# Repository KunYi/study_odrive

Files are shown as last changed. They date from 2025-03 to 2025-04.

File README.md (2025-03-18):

## Important Note

The firmware in this repository is compatible with the ODrive v3.x (NRND) and is no longer under active development.

Firmware for the new generation of ODrives ([ODrive Pro](https://odriverobotics.com/shop/odrive-pro), [S1](https://odriverobotics.com/shop/odrive-s1), [Micro](https://odriverobotics.com/shop/odrive-micro), etc.) is currently being actively maintained and developed, however its source code is currently not publicly available. Access may be available under NDA, please [reach out to us](mailto:info@odriverobotics.com) for inquiries.

## Overview

ODrive Logo

This project is all about accurately driving brushless motors, for cheap. The aim is to make it possible to use inexpensive brushless motors in high performance robotics projects, like [this](https://www.youtube.com/watch?v=WT4E5nb3KtY).

| Branch | Build Status |
|---|---|
| master |  |
| devel  |  |



Please refer to the [Developer Guide](https://docs.odriverobotics.com/v/latest/developer-guide.html#) to get started with ODrive firmware development.

### Repository Structure
 * **Firmware**: ODrive firmware
 * **tools**: Python library & tools
 * **docs**: Documentation

### Other Resources

 * [Main Website](https://www.odriverobotics.com/)
 * [User Guide](https://docs.odriverobotics.com/)
 * [Forum](https://discourse.odriverobotics.com/)
 * [Chat](https://discourse.odriverobotics.com/t/come-chat-with-us/281)

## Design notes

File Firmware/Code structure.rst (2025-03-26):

ODrive 代碼結構
==================

啟動流程
--------

啟動程序
^^^^^^^^

- **文件位置**: `Board/v3/startup_stm32f405xx.s`
- **功能**: 設置初始堆疊指針、配置中斷向量表、跳轉到 `SystemInit()`

系統初始化
^^^^^^^^^^

- **函數**: `SystemInit()`
- **文件位置**: `Board/v3/Src/system_stm32f4xx.c`
- **功能**: 重置系統狀態、配置向量表、設置系統時鐘

啟動前檢查
^^^^^^^^^^

- **函數**: `early_start_checks()`
- **文件位置**: `MotorControl/main.cpp`
- **功能**: 檢查是否需要進入DFU模式（當AUX L/H 拉高或標誌位被設置時）

主函數
^^^^^^

- **函數**: `main()`
- **文件位置**: `MotorControl/main.cpp`
- **功能**:

  - 讀取晶片UID生成USB設備描述符的序列號
  - 調用 `system_init()` 進行系統初始化
  - 透過 `config_manager` 載入系統設定
  - 調用 `board_init()` 進行板級與外設初始化
  - 初始化外設和控制系統
  - 設定 GPIO 模式
  - 建立 FreeRTOS 執行環境與創建預設執行Task, 執行 `rtos_main()`
  - 在 rtos_main 進行USB/ADC/PWM/UART/Communication/Axes 相關初始化，並開啟 axis 的 task thread 後結束 rtos_main 自己
  - 系統透過 axis status machine 運作，執行Motors 的初始化與定位相關

系統初始化
----------

板級初始化
^^^^^^^^^^

- **函數**: `system_init()`
- **文件位置**: `Board/v3/board.cpp`
- **功能**:

  - 初始化STM32 HAL庫
  - 檢查板卡硬件版本
  - 配置系統時鐘和引腳狀態

外設初始化
----------

GPIO初始化
^^^^^^^^^^

- **文件位置**: `Board/v3/Src/gpio.c`
- **相關函數**: `MX_GPIO_Init()`

ADC初始化
^^^^^^^^^

- **文件位置**: `Board/v3/Src/adc.c`
- **相關函數**: `MX_ADC1_Init()`, `MX_ADC2_Init()`, `MX_ADC3_Init()`
- **功能**: 用於電流檢測、電壓檢測等

定時器初始化
^^^^^^^^^^^^

- **文件位置**: `Board/v3/Src/tim.c`
- **相關函數**: `MX_TIM1_Init()`, `MX_TIM8_Init()`
- **功能**: 用於PWM生成控制電機

SPI初始化
^^^^^^^^^

- **文件位置**: `Board/v3/Src/spi.c`
- **相關函數**: `MX_SPI3_Init()`
- **功能**: 用於編碼器接口

CAN總線初始化
^^^^^^^^^^^^^

- **文件位置**: `Board/v3/Src/can.c`
- **相關函數**: `MX_CAN1_Init()`

USB初始化
^^^^^^^^^

- **文件位置**: `Board/v3/Src/usbd_conf.c`, `Board/v3/Src/usbd_cdc_if.c`
- **相關函數**: `MX_USB_DEVICE_Init()`

FOC電機控制
-----------

電機控制類
^^^^^^^^^^

- **文件位置**: `MotorControl/motor.cpp`, `MotorControl/motor.hpp`
- **主要類**: `Motor`
- **功能**: 電機參數初始化、電流控制、速度控制、位置控制

編碼器接口
^^^^^^^^^^

- **文件位置**: `MotorControl/encoder.cpp`, `MotorControl/encoder.hpp`
- **主要類**: `Encoder`
- **功能**: 編碼器初始化、位置讀取、速度計算

FOC控制算法
^^^^^^^^^^^

- **文件位置**: `MotorControl/foc.cpp`, `MotorControl/foc.hpp`
- **主要函數**: `FOC_current()`, `FOC_voltage()`
- **功能**: 實現Field Oriented Control算法

軸控制
^^^^^^

- **文件位置**: `MotorControl/axis.cpp`, `MotorControl/axis.hpp`
- **主要類**: `Axis`
- **功能**: 協調電機和編碼器，實現位置/速度閉環控制

軌跡規劃
^^^^^^^^

- **文件位置**: `MotorControl/trajectory.cpp`, `MotorControl/trajectory.hpp`
- **主要類**: `Trajectory`
- **功能**: 實現平滑的運動軌跡規劃

通信接口
--------

USB通信
^^^^^^^

- **文件位置**: `MotorControl/usb_communication.cpp`, `MotorControl/usb_communication.hpp`
- **功能**: 處理USB通信，解析命令

CAN總線通信
^^^^^^^^^^^^

- **文件位置**: `MotorControl/can_communication.cpp`, `MotorControl/can_communication.hpp`
- **功能**: 處理CAN總線通信

命令處理
^^^^^^^^

- **文件位置**: `MotorControl/commands.cpp`, `MotorControl/commands.hpp`
- **功能**: 解析和執行來自通信接口的命令

主循環與狀態機
--------------

主循環
^^^^^^

- **文件位置**: `MotorControl/main.cpp`
- **功能**: 調用狀態機更新、處理通信、執行控制算法

狀態機
^^^^^^

- **文件位置**: `MotorControl/state_machine.cpp`, `MotorControl/state_machine.hpp`
- **主要類**: `StateMachine`
- **功能**: 管理電機控制器的不同狀態（校準、閉環控制、錯誤狀態等）

安全檢查與錯誤處理
------------------

錯誤處理
^^^^^^^^

- **文件位置**: `MotorControl/error.cpp`, `MotorControl/error.hpp`
- **功能**: 定義錯誤類型、處理錯誤狀態

安全監控
^^^^^^^^

- **文件位置**: `MotorControl/safety.cpp`, `MotorControl/safety.hpp`
- **功能**: 監控過流、過壓、過溫等異常情況

ODrive 韌體架構分析
======================

第一章：系統初始化與啟動 (System Initialization and Startup)
--------------------------------------------------------------------

韌體的啟動流程由 rtos_main 函數開始
這個函數負責初始化核心周邊、通訊介面和馬達相關組件。

* USB 裝置初始化：首先會呼叫 MX_USB_DEVICE_Init() 初始化 USB 通訊。
* ADC 初始化：start_general_purpose_adc() 用於啟動 ADC，可能用於溫度和使用者自定義量測。
* 通訊初始化：init_communication() 負責設定不同的通訊介面，例如 UART、CAN 等。

  * 原始碼中提到 uart_poll() 函數，暗示了 UART 通訊的輪詢機制。
  * ODriveCAN can_; 的宣告表示支援 CAN Bus 通訊。
  *  程式碼中也看到對 enable_uart_a、enable_uart_b、enable_uart_c 和 enable_can_a 等配置的檢查，這些配置項在 BoardConfig_t 結構體中定義。

* PWM 輸入初始化：pwm0_input.init() 初始化 PWM 輸入捕獲模組，可能用於接收外部 PWM 訊號。
* 絕對式編碼器 CS 腳位設定：程式碼中針對具有絕對式編碼器的軸進行 CS (Chip Select) 腳位的初始化。
* 閘極驅動器初始化：每個軸的馬達物件會調用 setup() 函數，這可能包含閘極驅動器 (如 Drv8301) 的初始化。
* 編碼器初始化：每個軸的編碼器物件也會調用 setup() 函數，啟動編碼器硬體介面 (例如 HAL_TIM_Encoder_Start)。
* 組件連接：程式碼中將不同組件的輸出和輸入連接起來，例如感測器無感測估測器 (SensorlessEstimator) 的輸出連接到控制器的輸入。
* ADC PWM 同步啟動：start_adc_pwm() 啟動 PWM 產生和 ADC 中斷/回調，這是實現 FOC 的關鍵步驟。
* 類比線程啟動：start_analog_thread() 啟動一個專門處理類比訊號的線程。
* 等待馬達就緒：啟動流程會等待一段時間 (最長 2 秒) 讓馬達相關組件就緒，例如電流感測器的校準收斂。
* 載入使用者配置：韌體會嘗試載入儲存的使用者配置，如果成功則應用配置，否則清除並應用預設配置。
* ConfigManager 類別負責配置的載入和儲存。
* 板卡特定周邊初始化：board_init() 函數用於初始化特定硬體平台的周邊。
* GPIO 初始化：根據 odrv.config_.gpio_modes 中的配置，初始化每個 GPIO 腳位的功能 (例如數位輸入/輸出、類比輸入、UART、CAN、PWM、編碼器等)。

第二章：軸 (Axis) 管理
---------------------------

ODrive 的核心概念之一是 軸 (Axis)。 一個 ODrive 裝置可以有多個軸 (**在 AXIS_COUNT** 中定義)，每個軸通常對應一個馬達。

軸物件：
^^^^^^^^

**Axis** 類別封裝了控制一個馬達所需的所有組件和狀態。

每個 **Axis** 物件都包含了以下子物件

- **Encoder**: 負責馬達位置和速度的感測

  - **Controller**: 實現馬達的控制邏輯，包括位置、速度和扭矩控制模式。
  - **Motor**: 代表實際的馬達硬體，負責 PWM 控制、電流感測、溫度保護等。
  - **TrapezoidalTrajectory**: 用於產生梯形速度曲線，實現平滑的運動規劃。
  - **Endstop**: 用於限制馬達的運動範圍。
  - **MechanicalBrake**: 用於控制機械煞車 (如果存在)。

- **軸狀態機**：每個軸都有一個狀態機 (current_state_)，定義了軸的不同操作階段，例如啟動、校準、閉迴路控制、空閒等。task_chain_ 則定義了軸狀態轉換的順序。
- **執行緒管理**：每個軸都在一個獨立的 **FreeRTOS** 執行緒中運行其狀態機迴圈 (**run_state_machine_loop**)。**start_thread()** 函數負責創建這些執行緒。
- **步進/方向介面**：**Axis** 類別支援步進/方向訊號輸入，用於接收外部運動指令。**step_cb()** 函數處理步進訊號，並更新馬達的目標位置。
- **錯誤處理**：每個軸都有一個 error_ 變數，用於記錄該軸及其子組件發生的錯誤。**do_checks()** 函數會檢查軸及其子組件的錯誤狀態。
- **看門狗**： **watchdog_feed()** 和 **watchdog_check()** 函數用於實現看門狗機制，防止韌體因錯誤而停止響應。

第三章：通訊介面 (Communication Interfaces)
-----------------------------------------------

ODrive 韌體支援多種通訊介面，用於與外部設備進行控制和數據交換。

- **UART** (Universal Asynchronous Receiver/Transmitter):

在board.c 的程式碼中可以看到下面的宣告，表示使用 STM32F405 的 UASART4 作為UART_A 和 USART2 作為 UART_B。::

  UART_HandleTypeDef* uart_a = &huart4;
  UART_HandleTypeDef* uart_b = &huart2;

BoardConfig_t 設定中包含 enable_uart_a、enable_uart_b、enable_uart_c 和對應的 uart_a_baudrate 值等等。

ODriveIntf::StreamProtocolType 则是使用UART 的一種協議類型定義。

- **CAN** (Controller Area Network):

ODriveCAN can_; 的宣告表示支援 CAN Bus 通訊。

BoardConfig_t 中包含 enable_can_a 設定值

另外GPIO 配置中包含 ODriveIntf::GPIO_MODE_CAN_A 選項，並指定了相關的 GPIO 腳位 (CAN_R, CAN_D)。程式碼中檢查 GPIO 模式是否與 CAN 模式一致。

- **USB** (Universal Serial Bus):

  **MX_USB_DEVICE_Init()** 用於初始化 USB 裝置功能。

  - SystemStats_t 結構體中包含與 USB 相關的統計資訊，例如最大堆疊使用量 (max_stack_usage_usbv) 和優先級 (prio_usb)。
  - ODriveIntf::StreamProtocolType usb_cdc_protocol 用於定義 USB CDC (Communication Device Class) 的通訊協定。

- **GPIO** 作為通訊介面:

GPIO 可以配置為多種通訊相關的功能，例如 UART 和 I2C 的替代功能 (AF, Alternate Function)。

第四章：馬達控制 (Motor Control)
------------------------------------------

ODrive 主要採用 磁場導向控制 (Field-Oriented Control, FOC)。**FieldOrientedController** 類別實現了 FOC 演算法。

- 電流感測：馬達電流透過 ADC 進行感測。**Motor::current_meas_cb()** 函數處理電流感測的回調，並進行零點校準 ( DC_calib_ ) 和資料更新。**phase_current_from_adcval()** 函數將 **ADC** 值轉換為相電流。
- 電壓應用：FOC 控制器計算出所需的 α-β 參考系電壓 ( final_v_alpha_, final_v_beta_ )，然後透過 **空間向量脈寬調變 (Space Vector Modulation, SVM)** 將其轉換為三個 PWM 訊號的佔空比 (pwm_timings)。**Motor::pwm_update_cb()** 函數在 PWM 更新事件發生時被調用，並應用新的 PWM 時序。
  呼叫順序如下::

  Motor::pwm_update_cb() ==>> control_law_->get_output() (實際就是　AlphaBetaFrameController::get_output()) ==>> FieldOrientedController::get_alpha_beta_output() ==>> SVM()

- 控制模式：Controller 類別支援多種控制模式:

  - 位置控制 (Position Control): 將馬達控制到指定的角度。
  - 速度控制 (Velocity Control): 將馬達控制到指定的轉速。
  - 扭矩控制 (Torque Control): 直接控制馬達輸出的扭矩。

- 電流控制迴路：在電流控制模式下，FOC 控制器使用 PI (比例積分) 控制器 來追蹤目標 d 軸和 q 軸電流 (Idq_setpoint_)。PI 控制器的增益 (pi_gains_) 可以在電阻和電感測量後自動設定.
- 電壓控制迴路：在電壓控制模式下，FOC 控制器直接輸出目標 d 軸和 q 軸電壓 (Vdq_setpoint_)。
- 前饋控制：FOC 控制器支援多種前饋控制項，例如 bEMF 前饋 (bEMF_FF_enable) 和 RI、wL*I 前饋 (R_wL_FF_enable)，以提高控制性能。
- 扭矩限制和速度限制：控制器可以設定扭矩上限 (torque_limit) 和速度上限 (vel_limit)，以保護馬達和系統。
- 反饋來源：控制器可以選擇不同的位置和速度反饋來源，例如編碼器或無感測估測器.
- 開環控制：OpenLoopController 類別實現了開環控制模式，在沒有位置或速度反饋的情況下直接控制馬達的相位和電壓/電流。這通常用於馬達參數校準階段。

第五章：位置和速度估測 (Position and Velocity Estimation)
----------------------------------------------------------------------

韌體使用兩種主要方法來獲取馬達的位置和速度資訊：

- **編碼器 (Encoder)** ：Encoder 類別處理來自各種編碼器的訊號。支援增量式編碼器透過計數器 (timer_) 測量相對位置變化。也支援霍爾感測器，透過解碼霍爾訊號 (decode_hall_samples()) 獲取粗略的位置和速度資訊。對於絕對式編碼器，韌體透過 SPI 通訊 (abs_spi_start_transaction(), abs_spi_cb()) 讀取絕對位置。對於正餘弦編碼器，韌體讀取類比訊號 (sincos_sample_s_, sincos_sample_c_) 並計算相位。編碼器物件還實現了 鎖相迴路 (Phase-Locked Loop, PLL) (pll_)，用於濾除編碼器雜訊並估計速度。

- **無感測估測器 (Sensorless Estimator)** ：SensorlessEstimator 類別在沒有編碼器的情況下，基於馬達的電壓和電流資訊來估計轉子位置和速度。它使用基於磁鏈觀測器的演算法，通過測量到的相電流和施加的電壓來估計磁鏈狀態 (flux_state_)，進而推斷轉子位置和速度。

模式切換：韌體可以根據配置在編碼器模式和無感測模式之間切換。

第六章：校準程序 (Calibration Procedures)
--------------------------------------------------

為了獲得最佳的控制性能，ODrive 韌體包含多個校準程序-
- **電流感測器零點校準 (DC Calibration)** ： *Motor::dc_calib_cb()* 函數用於校準電流感測器的偏移量 ( DC_calib_ )。
- **相電阻測量 (Phase Resistance Measurement)** ： *Motor::measure_phase_resistance()* 函數透過施加一個已知的測試電流並測量電壓來估計馬達的相電阻 ( config_.phase_resistance )。
- **相電感測量 (Phase Inductance Measurement)** ： *Motor::measure_phase_inductance()* 函數透過快速切換輸出電壓並觀察電流漣波來估計馬達的相電感 ( config_.phase_inductance )。
- **編碼器偏移校準 (Encoder Offset Calibration)** ： *Encoder::run_offset_calibration()* 函數用於確定編碼器計數和馬達電氣相位的對應關係 ( config_.phase_offset, config_.phase_offset_float )。這通常涉及在開環模式下旋轉馬達並採集編碼器讀數。
- **霍爾感測器極性校準 (Hall Polarity Calibration)** ： *Encoder::run_hall_polarity_calibration()* 函數用於確定霍爾感測器的極性 ( config_.hall_polarity )。
- **霍爾感測器相位校準 (Hall Phase Calibration)** ： *Encoder::run_hall_phase_calibration()* 函數用於校準霍爾感測器訊號和馬達電氣相位的對應關係 ( config_.hall_edge_phcnt )。
- **方向尋找 (Direction Find)** ： *Encoder::run_direction_find()* 函數用於確定編碼器的方向 ( config_.direction )。
- **反齒槽效應校準 (Anticogging Calibration)** ： *Controller::anticogging_calibration()* 函數用於測量並補償由馬達磁極齒槽效應引起的扭矩波動 ( config_.anticogging.cogging_map )。

第七章：配置管理 (Configuration Management)
----------------------------------------------------

ODrive 韌體使用 ConfigManager 類別來管理配置參數的儲存和載入。

- **配置結構體** ：主要的配置參數儲存在 ODrive::config_ ( BoardConfig_t ) 和每個軸的 Axis::config_、Controller::config_、Motor::config_、Encoder::config_ 等結構體中。
- **預設配置** ：程式碼中可以看到許多預設配置值的定義 (例如 DEFAULT_BRAKE_RESISTANCE, DEFAULT_MIN_DC_VOLTAGE, DEFAULT_GPIO_MODES)。
- **載入配置** ：在啟動時，韌體會嘗試從非揮發性記憶體 (例如 Flash) 載入使用者配置。如果載入成功，則應用這些配置 ( config_read_all(), config_apply_all() ).
- **儲存配置** ：使用者可以透過通訊介面將目前的配置儲存到非揮發性記憶體 ( config_write_all(), config_manager.start_store(), config_manager.finish_store() ).
- **清除配置** ：韌體也提供清除所有使用者配置並恢復到預設值的機制 ( config_clear_all() ).
- **GPIO 模式配置** ：BoardConfig_t::gpio_modes 陣列定義了每個 GPIO 腳位的功能模式。在啟動時，韌體會根據這些配置初始化 GPIO 腳位。

第八章：錯誤處理與安全 (Error Handling and Safety)
------------------------------------------------------------------

ODrive 韌體具有完善的錯誤處理機制。

- 錯誤碼：每個主要組件 (ODrive 本身、Axis、Motor、Encoder、Controller、SensorlessEstimator) 都有一個 error_ 變數，用於記錄發生的錯誤。錯誤碼通常是枚舉類型 (例如 ODrive::Error, Axis::Error, Motor::Error)。
- 設定錯誤：組件可以使用 set_error() 函數設定其錯誤狀態。
- 檢查錯誤：Axis::do_checks() 函數會檢查軸及其子組件的錯誤狀態。ODrive::any_error() 函數檢查整個系統是否存在任何錯誤。
- 解除武裝 (Disarming)：在檢測到嚴重錯誤時，韌體會將馬達解除武裝 (Motor::disarm(), ODrive::disarm_with_error())，停止 PWM 輸出，以防止硬體損壞。
- 煞車電阻控制 (Brake Resistor Control)：韌體支援使用煞車電阻來吸收再生能量，防止直流母線過壓。brake_resistor_armed_, brake_resistor_saturated_, brake_resistor_current_ 等變數用於追蹤煞車電阻的狀態。 *update_brake_current()* 函數計算並設定煞車電阻的佔空比。
- 電流限制：Motor::effective_current_lim() 函數計算有效的電流限制。在 FOC 控制器中，電流會被限制在安全範圍內。
- 溫度保護：OnboardThermistorCurrentLimiter 和 OffboardThermistorCurrentLimiter 類別用於監控 FET 和馬達的溫度，並在溫度過高時限制電流或觸發錯誤。
- 看門狗計時器 (Watchdog Timer)：看門狗用於檢測韌體是否停止運行，並在超時時重置系統。

第九章：即時作業系統 (Real-Time Operating System, RTOS)
------------------------------------------------------------------

ODrive 韌體基於 FreeRTOS 運行。

- **執行緒 (Tasks)** ：系統和每個軸的功能都運行在不同的 FreeRTOS 執行緒中，實現並行處理.
- **優先級 (Priorities)** ：每個執行緒可以設定不同的優先級 (例如 thread_priority_, osPriorityHigh)，以確保關鍵任務 (例如控制迴路) 能夠及時執行.
- **訊號量 (Signals)** ： *osSignalWait()* 和 *osSignalSet()* 等 FreeRTOS API 可能用於執行緒間的同步和通訊 (例如 Axis::wait_for_control_iteration() 使用訊號量等待控制迴路完成).
- **互斥鎖 (Mutexes) 和臨界區段 (Critical Sections)** ： *CRITICAL_SECTION()* 宏用於保護共享資源免受多個執行緒同時存取的影響，防止競爭條件.
- **堆疊大小 (Stack Size)** ：每個執行緒都有分配的堆疊空間 (stack_size_)，用於儲存局部變數和函數調用資訊.

第十章：硬體抽象層 (Hardware Abstraction Layer, HAL)
---------------------------------------------------------

ODrive 韌體廣泛使用 STM32 HAL (Hardware Abstraction Layer) 庫來與底層的 STM32 微控制器硬體進行互動。
HAL 提供了對微控制器各種周邊 (例如 ADC、TIM、SPI、UART、GPIO) 的標準化 API，使得韌體開發人員可以更方便地存取和控制硬體，而無需深入了解底層硬體細節。
例如，HAL_ADC_Start_DMA(), HAL_TIM_Encoder_Start(), HAL_GPIO_Init(), HAL_SPI_TxRxCpltCallback() 等函數都是 HAL 庫提供的 API.
韌體中定義了許多指向 HAL 結構體的指標 (例如 TIM_HandleTypeDef* timer_, ADC_HandleTypeDef hadc1, SPI_HandleTypeDef hspi3)，用於操作特定的硬體周邊

系統主要參數設計
=================



ODrive 使用 TIMER1 & TIMER8 產生控制MOSFET 開關用的PWM，這也是STM32 本身具有的兩個高級定時器，它們兩個分別對應兩顆FOC馬達控制使用TIM1 對應M0, TIM8 對應M1，
都是使用 **TIM_COUNTERMODE_CENTERALIGNED3** (參考tim.c or ODrive.ioc)，所以向上或向下開始計數的時候都會產生事件, TIM_1_8_RCR(Repetition Counter Register) 設定為2

main.h 是透過 **ODrive.ioc** (*STM32CubeMX* 設定檔) 產生的。

- **TIM_1_8_CLOCK_HZ**: TIM1 & TIM8 的頻率來源 (168MHz), 定義在 main.h
- **TIM_1_8_PERIOD_CLOCKS**: TIM1 & TIM8 每個週期的計數 (3500), 所以TIM1/TIM8 的PWM一個週期為 168MHz/3500/2 = 24KHz, 2 是因為 center_aligned 上下數各一次，定義在 main.h
- **TIM_1_8_DEADTIME_CLOCKS**: TIM1 & TIM8 輸出的死區定義時間時脈數(20), 定義在 main.h

- **CURRENT_MEAS_PERIOD**:　量測電流的週期，目前設計為PWM週期的3倍長, 指定給常數 *current_meas_period* 定義在 board.h
- **CURRENT_MEAS_HZ**: 量測電流的頻率， 目前設計為PWM頻率的1/3，指定給常數 *current_meas_hz* 定義在board.h
- **VBUS_S_DIVIDER_RATIO**: 量測DCBUS/VBUS 電壓的分壓器比率, 24V 使用R6(10KOhm), R7(1KOhm) 分壓比率為11.0f, 大於等於48V系統則為R6(18KOhm), R7(1KOhm), 分壓比率為19.0f

所以 ODrive 的 FOC 控制頻率是24KHz, 電流環是 24KHz/3 = 8KHz。但是實際電流取樣的頻率設計不是透過這個常數進行。

而是在TIM8_UP_TIM13_IRQ 設定，因為它設定中間對齊與模式3 上下都觸發，因此為48KHz，但是該RCR 為 2，所以它實際的觸發頻率為48KHz/(2+1)=16KHz,等於一次觸發為上數，一次觸發為下數。
但是它又不是每次觸發都取樣，它只在TIM8上數時，進行取樣，所以為16KHz/2=8KHz。

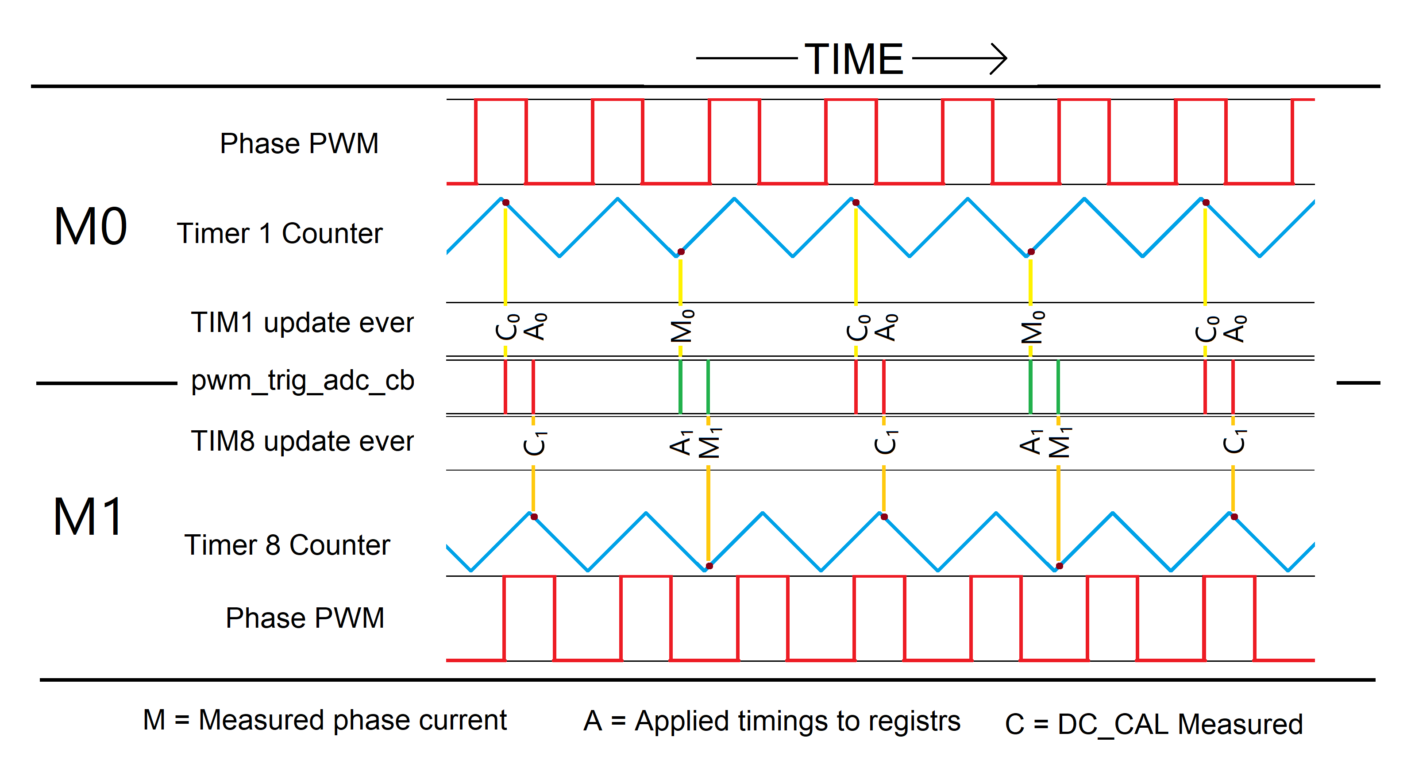
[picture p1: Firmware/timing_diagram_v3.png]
sampling timing


電流環的頻率設定，跟電機的電頻率跟磁極數目與轉速正相關，一般需要最少10倍來設計。

ODrive 中斷表與優先權
=========================

.. list-table:: **Interrupt Table**
   :widths: 25 25 25 25 50
   :header-rows: 1

   * - Interrupt Name
     - Priority Level
     - SubPriority
     - Source
     - Notes
   * - NMI_Handler
     - --
     - --
     - Default Cortex-M4
     - Non-Maskable Interrupt (Highest Priority)
   * - HardFault_Handler
     - --
     - --
     - Default Cortex-M4
     - Hard Fault (Second Highest Priority)
   * - MemoryManagement_IRQn
     - --
     - --
     - CubeMX Config []
     - Configured in CubeMX
   * - BusFault_IRQn
     - --
     - --
     - CubeMX Config []
     - Configured in CubeMX
   * - UsageFault_IRQn
     - --
     - --
     - CubeMX Config []
     - Configured in CubeMX
   * - TIM8_UP_TIM13_IRQn
     - 0
     - 0
     - board.cpp [], CubeMX Config []
     - Timer 8 Update and Timer 13 Interrupt (Note: Priority 0 is higher than 1)
   * - TIM1_UP_TIM10_IRQn
     - 0
     - 0
     - CubeMX Config []
     - Timer 1 Update and Timer 10 Interrupt (Note: Priority 0 is higher than 1)
   * - TIM8_TRG_COM_TIM14_IRQn
     - 0
     - 0
     - CubeMX Config []
     - Timer 8 Trigger and Commutation, Timer 14 Interrupt (Note: Priority 0 is higher than 1)
   * - EXTI0_IRQn
     - 1
     - 0
     - board.cpp []
     - External Interrupt 0
   * - EXTI1_IRQn
     - 1
     - 0
     - board.cpp []
     - External Interrupt 1
   * - EXTI2_IRQn
     - 1
     - 0
     - board.cpp []
     - External Interrupt 2
   * - EXTI3_IRQn
     - 1
     - 0
     - board.cpp []
     - External Interrupt 3
   * - EXTI4_IRQn
     - 1
     - 0
     - board.cpp []
     - External Interrupt 4
   * - EXTI9_5_IRQn
     - 1
     - 0
     - board.cpp []
     - External Interrupts 5 to 9
   * - EXTI15_10_IRQn
     - 1
     - 0
     - board.cpp []
     - External Interrupts 10 to 15
   * - ControlLoop_IRQn
     - 5
     - 0
     - board.cpp [], (OTG_HS_IRQHandler define [], CubeMX)
     - Used for the Field-Oriented Control (FOC) loop
   * - ADC_IRQn (ADC1, ADC2, ADC3)
     - 5
     - 0
     - CubeMX Config []
     - ADC1, ADC2, and ADC3 Interrupts (likely priority as per CubeMX, though not explicitly set in board.cpp like ControlLoop_IRQn)
   * - SPI3_IRQn
     - 5
     - 0
     - CubeMX Config []
     - SPI3 Interrupt (likely priority as per CubeMX)
   * - UART4_IRQn
     - 5
     - 0
     - board.cpp [], CubeMX Config []
     - UART4 Interrupt (if enable_uart_a is true)
   * - USART2_IRQn
     - 5
     - 0
     - CubeMX Config [] (likely)
     - USART2 Interrupt (if enable_uart_b is true, likely priority as per CubeMX)
   * - TIM5_IRQn
     - 5
     - 0
     - CubeMX Config []
     - TIM5 Interrupt (likely priority as per CubeMX)
   * - OTG_FS_IRQn
     - 5
     - 0
     - CubeMX Config []
     - USB OTG FS Interrupt
   * - DMA1_Stream0_IRQn
     - 5
     - 0
     - CubeMX Config []
     - DMA1 Stream 0 Interrupt (likely priority as per CubeMX)
   * - DMA1_Stream2_IRQn
     - 5
     - 0
     - CubeMX Config []
     - DMA1 Stream 2 Interrupt (likely priority as per CubeMX)
   * - DMA1_Stream4_IRQn
     - 5
     - 0
     - CubeMX Config []
     - DMA1 Stream 4 Interrupt (likely priority as per CubeMX)
   * - DMA1_Stream5_IRQn
     - 5
     - 0
     - CubeMX Config []
     - DMA1 Stream 5 Interrupt (likely priority as per CubeMX)
   * - DMA2_Stream0_IRQn
     - 5
     - 0
     - CubeMX Config []
     - DMA2 Stream 0 Interrupt (likely priority as per CubeMX)
   * - CAN1_TX_IRQn
     - 6
     - 0
     - CubeMX Config []
     - CAN1 Transmit Interrupt
   * - CAN1_RX0_IRQn
     - 6
     - 0
     - CubeMX Config []
     - CAN1 Receive FIFO 0 Interrupt
   * - CAN1_RX1_IRQn
     - 6
     - 0
     - CubeMX Config []
     - CAN1 Receive FIFO 1 Interrupt
   * - CAN1_SCE_IRQn
     - 6
     - 0
     - CubeMX Config []
     - CAN1 Status Change Interrupt
   * - DebugMonitor_IRQn
     - 0
     - 0
     - CubeMX Config []
     - Debug Monitor Interrupt
   * - SVCall_IRQn
     - 0
     - 0
     - CubeMX Config []
     - System Service Call via SWI instruction
   * - I2C1_EV_IRQn
     - N/A
     - N/A
     - board.cpp [] (HAL_I2C_EV_IRQHandler)
     - I2C1 Event Interrupt (Priority likely set in MX_I2C1_Init, but not explicitly shown in board_init like ControlLoop_IRQn)
   * - I2C1_ER_IRQn
     - N/A
     - N/A
     - board.cpp [] (HAL_I2C_ER_IRQHandler)
     - I2C1 Error Interrupt (Priority likely set in MX_I2C1_Init)
   * - PendSV_IRQn
     - 15
     - 0
     - CubeMX Config []
     - FreeRTOS PendSV Interrupt (for context switching)
   * - SysTick_IRQn
     - 15
     - 0
     - CubeMX Config []
     - FreeRTOS SysTick Interrupt (for time slicing and system tick)

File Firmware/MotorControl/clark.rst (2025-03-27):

Clarke 變換
==============

**1. 為何需要 Clarke 變換？**

在三相平衡交流系統中，通常會有三個相電壓/電流（Va, Vb, Vc），它們是彼此相差 120° 的正弦波。然而，這三個變數並非完全獨立，它們本身也受 **克希荷夫電流定律 (KCL)** 限制。把負載看成單一節點使用，所以一定會滿足 **KCL**：

.. math::

   V_a + V_b + V_c = 0

由於這個限制，三個變數中只有兩個是獨立的。**Clarke 變換** 的目的就是找到一個 **變換矩陣 T**，將三相電壓/電流 (Va, Vb, Vc) 轉換到一個二維的正交 **α-β 靜止坐標系** (Vα, Vβ) 中：

.. math::

   \left[
   \begin{matrix}
    V_\alpha \\
    V_\beta
   \end{matrix}
   \right]
   = T *
   \left[
   \begin{matrix}
   V_a \\
   V_b \\
   V_c
   \end{matrix}
   \right]

這樣做的優點是，我們可以使用兩個獨立的變數 :math:`\left(\textbf{V$_\mathbf{\alpha}, V_\mathbf{\beta}$}\right)` 在二維平面上 **完整地描述** 原始三相系統的電壓/電流資訊，簡化後續的分析和控制。

**2. 幾何直覺**

為了更好地理解 Clarke 變換，我們可以從幾何的角度來看：

-   **原始三相坐標 (Va, Vb, Vc)**：每一相電壓可以想像成對應到一個基底向量，這些向量之間相隔 120°。
-   **目標 α-β 二維坐標系**：我們希望建立一個 **正交基底** 來表示新的二維系統，方便分析：

    -   **α 軸**：方向與 A 相（Va）相同。
    -   **β 軸**：方向與 α 軸正交。

Clarke 變換的幾何意義就是將原始三相系統中的每個相電壓 **投影** 到這個新的正交 α 和 β 軸上，得到它們在二維平面上的分量 Vα 和 Vβ。

**3. 基底向量推導**

根據上述幾何直覺，我們可以推導出 Clarke 變換的基底向量和轉換矩陣：

-   **Va 的基底表示**: :math:`\left(\begin{matrix} 1_, 0\end{matrix}\right)`
-   **Vb 的基底表示**: :math:`\left(\begin{matrix} -\frac{1}{2}_, \frac{\sqrt{3}}{2}\end{matrix}\right)`
-   **Vc 的基底表示**: :math:`\left(\begin{matrix} -\frac{1}{2}_, -\frac{\sqrt{3}}{2}\end{matrix}\right)`

基於這些基底向量，我們可以 **構造出 Clarke 變換的矩陣 T**：

.. math::

   T =
   \left[
   \begin{matrix}
   1 & -\frac{1}{2} & -\frac{1}{2} \\
   0 & \frac{\sqrt{3}}{2} & -\frac{\sqrt{3}}{2}
   \end{matrix}
   \right]

**4. 矩陣驗證與標準公式**

將三相電壓 [Va, Vb, Vc]ᵀ 帶入上述轉換矩陣，我們可以得到 α 和 β 分量：

.. code-block::

   Vα = Va - 1/2Vb - 1/2Vc
   Vβ = √3/2Vb - √3/2Vc

這與常見的 Clarke 變換公式一致，證明了我們推導的正確性。

**5. Clarke 變換的程式碼實現**

在程式碼中，Clarke 變換通常會接收三相電流（Ia, Ib, Ic）或電壓作為輸入，並輸出兩相的 α-β 分量（Iα, Iβ 或 Vα, Vβ）。根據提供的程式碼片段，以下是一個 Clarke 變換的實現範例（針對電流）：

.. code-block:: c++

   std::optional<float2D> Ialpha_beta;

   if (currents.has_value()) {
       // Clarke transform
       Ialpha_beta = {
           (*currents),
           one_by_sqrt3 * ((*currents) - (*currents))
       };
   }

以及另一個範例：

.. code-block:: c++

   float I_alpha_beta = {
       current_meas->phA,
       one_by_sqrt3 * (current_meas->phB - current_meas->phC)};

在這些程式碼片段中，**三相電流被轉換為兩相靜止坐標系下的電流分量 Iα 和 Iβ**。``one_by_sqrt3`` 代表 **1/√3**。需要注意的是，Clarke 變換存在不同的版本，它們在最終的 α-β 分量上可能會有一個比例因子，例如 **功率保持不變** 的版本和 **幅值保持不變** 的版本。在實際應用中，應根據具體需求選擇合適的版本。

總結來說，**Clarke 變換** 是一種重要的坐標轉換，它將三相交流系統的變數轉換到一個更易於分析和控制的二維靜止坐標系中，是 **場導向控制 (FOC)** 等現代電機控制技術的基礎。

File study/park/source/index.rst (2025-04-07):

.. Park Transformation documentation master file, created by
   sphinx-quickstart on Wed Apr  2 17:21:10 2025.
   You can adapt this file completely to your liking, but it should at least
   contain the root `toctree` directive.

Park 轉換
===============================================

**Park 轉換 (Park Transformation)** 是電機工程中一種關鍵的數學工具，
常用於電機控制與向量控制 (Field-Oriented Control, FOC)。其基本概念是將二維靜態正交坐標 ( :math:`\alpha-\beta` 座標)
轉換至二維旋轉坐標 ( :math:`\mathbf{d-q}` 座標 )，以便簡化交流電機的控制與分析。

幾何原理與座標系統
----------------------------

在交流電機控制中，為了便於分析與控制，我們通常使用下列兩種不同的坐標系：

- :math:`\mathbf{\alpha-\beta}` **座標系**：靜態的直角坐標系，通常來自於 **Clarke 轉換** ，( :math:`i_\alpha` ) 和 ( :math:`i_\beta` ) 代表兩個正交的電壓或電流分量。
- **d-q 座標系**：一個相對於轉子磁場同步旋轉的坐標系，其中 **d 軸(Direct Axis)** 與磁場對齊， **q 軸(Quadrature Axis)** 則與 **d 軸** 垂直。

核心概念就是將 **Clarke 轉換** 後的 :math:`\alpha-\beta` 正交靜止座標，
透過代入旋轉的角速度 :math:`\mathbf{(\theta)}` 參數進行同步旋轉，
使其投影到 :math:`\mathbf{d-q}`　旋轉座標系 。在 **馬達上的角速度** 指的是 **電角速度(Electrical Angular Velocity)**

這樣本來觀察的弦波，就會變成直流信號，因為我們觀察的參考座標時刻隨著弦波同步旋轉，達到相對靜止的效果。

Park 轉換的推導過程
-----------------------

幾何推導
^^^^^^^^^^^^^^

考慮一個向量( :math:`\mathbf{I}` ) 在 :math:`\mathbf{\alpha-\beta}` 坐標系中的表示為：

.. math::
      \mathbf{I} = I_\alpha \hat{\imath} + I_\beta \hat{\jmath}

其中 :math:`(\hat{\imath})` 與 :math:`(\hat{\jmath})` 分別是 :math:`(\alpha)` 與 :math:`(\beta)` 軸的單位向量。

現在，假設 :math:`\mathbf{d-q}` 坐標系相對於 :math:`\mathbf{\alpha-\beta}` 坐標系旋轉了一個角度 :math:`(\theta)` ，我們希望將 :math:`(\mathbf{I})` 重新表示在 :math:`\mathbf{d-q}` 坐標系上。

d-q 坐標軸的表達式
^^^^^^^^^^^^^^^^^^^^^^^^^

當 dq 坐標系相對於 :math:`\mathbf{\alpha-\beta}` 坐標系 **順時針旋轉** :math:`\mathbf{(\theta)}` 角時，其新的基底向量 (單位向量) 可以表示為：

.. math::
   \begin{align}
   \hat{d} &= \cos\theta \hat{\imath} + \sin\theta \hat{\jmath}
   \\
   \hat{q} &= -\sin\theta \hat{\imath} + \cos\theta \hat{\jmath}
   \end{align}

這兩個向量的推導來自於標準二維旋轉矩陣的概念。若一個點 :math:`(x, y)` **逆時針旋轉** :math:`(\theta)` 角後的新坐標 :math:`(x', y')` 滿足：

.. math::
   \begin{bmatrix} x' \\ y' \end{bmatrix} =
   \begin{bmatrix} \cos\theta & -\sin\theta \\ \sin\theta & \cos\theta \end{bmatrix}
   \begin{bmatrix} x \\ y \end{bmatrix}

則相對於 :math:`\mathbf{\alpha-\beta}` 坐標系， :math:`\mathbf{d-q}` 坐標的單位向量由此獲得，
可以觀察到，就是只是旋轉方式的不同，一個 **逆時針方向**，一個 **順時針方向**。

向量投影計算
^^^^^^^^^^^^^^^^^^^

由於 :math:`\mathbf{d-q}` 軸的方向已知，:math:`(\mathbf{I})` 在 :math:`\mathbf{d-q}` 坐標上的投影可以通過 **內積** 計算：

.. math::
   \begin{align}
   i_d &= \mathbf{I} \cdot \hat{d} = i_\alpha \cos\theta + i_\beta \sin\theta
   \\
   i_q &= \mathbf{I} \cdot \hat{q} = -i_\alpha \sin\theta + i_\beta \cos\theta
   \end{align}

這兩個方程式可以用矩陣形式表示為：

.. math::
   \begin{bmatrix}
   i_d \\
   i_q
   \end{bmatrix} =
   \begin{bmatrix}
   \cos\theta & \sin\theta \\
   -\sin\theta & \cos\theta
   \end{bmatrix}
   \begin{bmatrix}
   i_\alpha \\
   i_\beta
   \end{bmatrix}

旋轉矩陣的特性
^^^^^^^^^^^^^^^^^^

上述矩陣是一個 **正交旋轉矩陣**，其特性如下：

1. 行向量與列向量皆為單位正交向量，確保坐標變換不改變向量長度。
2. 逆變換是其轉置，即：

.. math::
   \begin{bmatrix}
   \cos\theta & \sin\theta \\
   -\sin\theta & \cos\theta
   \end{bmatrix}^{-1} =
   \begin{bmatrix}
   \cos\theta & -\sin\theta \\
   \sin\theta & \cos\theta
   \end{bmatrix}

這表示若已知 :math:`\mathbf{d-q}` 坐標，可以逆推回 :math:`\mathbf{\alpha-\beta}` 坐標。

物理意義與應用
----------------

Park 轉換的主要優勢是簡化交流電機的控制。經過變換後：

- **d 軸** 分量對應於磁場方向的電壓或電流，用於控制磁場強度。因為 **d 軸** 與轉子磁場對齊，調節 :math:`\mathbf{i_d}` 影響磁鏈強度，進而影響電機勵磁。
- **q 軸** 分量對應於垂直於磁場的電壓或電流，用於控制轉矩。由於轉矩是由定子電流與轉子磁場的交互作用產生，因此調節 :math:`\mathbf{i_q}` 可以直接影響轉矩。

這樣，原本複雜的三相交流電機數學模型轉變為類似直流電機的控制方式，使向量控制更加直觀。

Park 的程式碼實現
----------------------

下面是ODrive 使用的代碼，位於 **FieldOriented::get_alpha_beta_output()** 內，
函式內進行了 **Park轉換** 與計算完畢後的 **逆Park轉換** 。

.. code-block:: c++

   ODriveIntf::MotorIntf::Error FieldOrientedController::get_alpha_beta_output(
      uint32_t output_timestamp, std::optional<float2D>* mod_alpha_beta,
      std::optional<float>* ibus) {

   if (!vbus_voltage_measured_.has_value() || !Ialpha_beta_measured_.has_value()) {
      // FOC didn't receive a current measurement yet.
      return Motor::ERROR_CONTROLLER_INITIALIZING;
   } else if (abs((int32_t)(i_timestamp_ - ctrl_timestamp_)) > MAX_CONTROL_LOOP_UPDATE_TO_CURRENT_UPDATE_DELTA) {
      // Data from control loop and current measurement are too far apart.
      return Motor::ERROR_BAD_TIMING;
   }

   // TODO: improve efficiency in case PWM updates are requested at a higher
   // rate than current sensor updates. In this case we can reuse mod_d and
   // mod_q from a previous iteration.

   if (!Vdq_setpoint_.has_value()) {
      return Motor::ERROR_UNKNOWN_VOLTAGE_COMMAND;
   } else if (!phase_.has_value() || !phase_vel_.has_value()) {
      return Motor::ERROR_UNKNOWN_PHASE_ESTIMATE;
   } else if (!vbus_voltage_measured_.has_value()) {
      return Motor::ERROR_UNKNOWN_VBUS_VOLTAGE;
   }

   auto [Vd, Vq] = *Vdq_setpoint_;
   float phase = *phase_;
   float phase_vel = *phase_vel_;
   float vbus_voltage = *vbus_voltage_measured_;

   std::optional<float2D> Idq;

   // Park transform
   if (Ialpha_beta_measured_.has_value()) {
      auto [Ialpha, Ibeta] = *Ialpha_beta_measured_;
      float I_phase = phase + phase_vel * ((float)(int32_t)(i_timestamp_ - ctrl_timestamp_) / (float)TIM_1_8_CLOCK_HZ);
      float c_I = our_arm_cos_f32(I_phase);
      float s_I = our_arm_sin_f32(I_phase);
      Idq = {
            c_I * Ialpha + s_I * Ibeta,
            c_I * Ibeta - s_I * Ialpha
      };
      Id_measured_ += I_measured_report_filter_k_ * (Idq->first - Id_measured_);
      Iq_measured_ += I_measured_report_filter_k_ * (Idq->second - Iq_measured_);
   } else {
      Id_measured_ = 0.0f;
      Iq_measured_ = 0.0f;
   }

   float mod_to_V = (2.0f / 3.0f) * vbus_voltage;
   float V_to_mod = 1.0f / mod_to_V;
   float mod_d;
   float mod_q;

   if (enable_current_control_) {
      // Current control mode

      if (!pi_gains_.has_value()) {
            return Motor::ERROR_UNKNOWN_GAINS;
      } else if (!Idq.has_value()) {
            return Motor::ERROR_UNKNOWN_CURRENT_MEASUREMENT;
      } else if (!Idq_setpoint_.has_value()) {
            return Motor::ERROR_UNKNOWN_CURRENT_COMMAND;
      }

      auto [p_gain, i_gain] = *pi_gains_;
      auto [Id, Iq] = *Idq;
      auto [Id_setpoint, Iq_setpoint] = *Idq_setpoint_;

      float Ierr_d = Id_setpoint - Id;
      float Ierr_q = Iq_setpoint - Iq;

      // Apply PI control (V{d,q}_setpoint act as feed-forward terms in this mode)
      mod_d = V_to_mod * (Vd + v_current_control_integral_d_ + Ierr_d * p_gain);
      mod_q = V_to_mod * (Vq + v_current_control_integral_q_ + Ierr_q * p_gain);

      // Vector modulation saturation, lock integrator if saturated
      // TODO make maximum modulation configurable
      float mod_scalefactor = 0.80f * sqrt3_by_2 * 1.0f / std::sqrt(mod_d * mod_d + mod_q * mod_q);
      if (mod_scalefactor < 1.0f) {
            mod_d *= mod_scalefactor;
            mod_q *= mod_scalefactor;
            // TODO make decayfactor configurable
            v_current_control_integral_d_ *= 0.99f;
            v_current_control_integral_q_ *= 0.99f;
      } else {
            v_current_control_integral_d_ += Ierr_d * (i_gain * current_meas_period);
            v_current_control_integral_q_ += Ierr_q * (i_gain * current_meas_period);
      }

   } else {
      // Voltage control mode
      mod_d = V_to_mod * Vd;
      mod_q = V_to_mod * Vq;
   }

   // Inverse park transform
   float pwm_phase = phase + phase_vel * ((float)(int32_t)(output_timestamp - ctrl_timestamp_) / (float)TIM_1_8_CLOCK_HZ);
   float c_p = our_arm_cos_f32(pwm_phase);
   float s_p = our_arm_sin_f32(pwm_phase);
   float mod_alpha = c_p * mod_d - s_p * mod_q;
   float mod_beta = c_p * mod_q + s_p * mod_d;

   // Report final applied voltage in stationary frame (for sensorless estimator)
   final_v_alpha_ = mod_to_V * mod_alpha;
   final_v_beta_ = mod_to_V * mod_beta;

   *mod_alpha_beta = {mod_alpha, mod_beta};

   if (Idq.has_value()) {
      auto [Id, Iq] = *Idq;
      *ibus = mod_d * Id + mod_q * Iq;
      power_ = vbus_voltage * (*ibus).value();
   }

   return Motor::ERROR_NONE;
   }

而下面的程式碼來自 STM MCSDK v6.2， 因為他的Clarke轉換出來的 :math:`\mathbf{i_\beta}` 方向相反，所以它轉換方程式也需要旋轉

.. code-block:: c++

   /**
   * @brief  This function transforms stator values alpha and beta, which
   *         belong to a stationary qd reference frame, to a rotor flux
   *         synchronous reference frame (properly oriented), so as q and d.
   *                   d= alpha *sin(theta)+ beta *cos(Theta)
   *                   q= alpha *cos(Theta)- beta *sin(Theta)
   * @param  Input: stator values alpha and beta in alphabeta_t format.
   * @param  Theta: rotating frame angular position in q1.15 format.
   * @retval Stator values q and d in qd_t format
   */
   __weak qd_t MCM_Park(alphabeta_t Input, int16_t Theta)
   {
   qd_t Output;
   int32_t d_tmp_1;
   int32_t d_tmp_2;
   int32_t q_tmp_1;
   int32_t q_tmp_2;
   int32_t wqd_tmp;
   int16_t hqd_tmp;
   Trig_Components Local_Vector_Components;

   Local_Vector_Components = MCM_Trig_Functions(Theta);

   /* No overflow guaranteed */
   q_tmp_1 = Input.alpha * ((int32_t )Local_Vector_Components.hCos);

   /* No overflow guaranteed */
   q_tmp_2 = Input.beta * ((int32_t)Local_Vector_Components.hSin);

   /* Iq component in Q1.15 Format */
   #ifndef FULL_MISRA_C_COMPLIANCY_MC_MATH
   /* WARNING: the below instruction is not MISRA compliant, user should verify
      that Cortex-M3 assembly instruction ASR (arithmetic shift right) is used by
      the compiler to perform the shift (instead of LSR logical shift right) */
   wqd_tmp = (q_tmp_1 - q_tmp_2) >> 15; //cstat !MISRAC2012-Rule-1.3_n !ATH-shift-neg !MISRAC2012-Rule-10.1_R6
   #else
   wqd_tmp = (q_tmp_1 - q_tmp_2) / 32768;
   #endif

   /* Check saturation of Iq */
   if (wqd_tmp > INT16_MAX)
   {
      hqd_tmp = INT16_MAX;
   }
   else if (wqd_tmp < (-32768))
   {
      hqd_tmp = ((int16_t)-32768);
   }
   else
   {
      hqd_tmp = ((int16_t)wqd_tmp);
   }

   Output.q = hqd_tmp;

   if (((int16_t)-32768) == Output.q)
   {
      Output.q = -32767;
   }
   else
   {
      /* Nothing to do */
   }

   /* No overflow guaranteed */
   d_tmp_1 = Input.alpha * ((int32_t )Local_Vector_Components.hSin);

   /* No overflow guaranteed */
   d_tmp_2 = Input.beta * ((int32_t )Local_Vector_Components.hCos);

   /* Id component in Q1.15 Format */
   #ifndef FULL_MISRA_C_COMPLIANCY_MC_MATH
   /* WARNING: the below instruction is not MISRA compliant, user should verify
      that Cortex-M3 assembly instruction ASR (arithmetic shift right) is used by
      the compiler to perform the shift (instead of LSR logical shift right) */
   wqd_tmp = (d_tmp_1 + d_tmp_2) >> 15; //cstat !MISRAC2012-Rule-1.3_n !ATH-shift-neg !MISRAC2012-Rule-10.1_R6
   #else
   wqd_tmp = (d_tmp_1 + d_tmp_2) / 32768;
   #endif

   /* Check saturation of Id */
   if (wqd_tmp > INT16_MAX)
   {
      hqd_tmp = INT16_MAX;
   }
   else if (wqd_tmp < (-32768))
   {
      hqd_tmp = ((int16_t)-32768);
   }
   else
   {
      hqd_tmp = ((int16_t)wqd_tmp);
   }

   Output.d = hqd_tmp;

   if (((int16_t)-32768) == Output.d)
   {
      Output.d = -32767;
   }
   else
   {
      /* Nothing to do */
   }

      return (Output);
   }

下面則是 **ARM CMSIS DSP Pack** 內的轉換函式 **Park轉換**

.. code-block:: c++

  /**
   * @brief Floating-point Park transform
   * @param[in]  Ialpha  input two-phase vector coordinate alpha
   * @param[in]  Ibeta   input two-phase vector coordinate beta
   * @param[out] pId     points to output   rotor reference frame d
   * @param[out] pIq     points to output   rotor reference frame q
   * @param[in]  sinVal  sine value of rotation angle theta
   * @param[in]  cosVal  cosine value of rotation angle theta
   * @return     none
   *
   * The function implements the forward Park transform.
   *
   */
  __STATIC_FORCEINLINE void arm_park_f32(
  float32_t Ialpha,
  float32_t Ibeta,
  float32_t * pId,
  float32_t * pIq,
  float32_t sinVal,
  float32_t cosVal)
  {
    /* Calculate pId using the equation, pId = Ialpha * cosVal + Ibeta * sinVal */
    *pId = Ialpha * cosVal + Ibeta * sinVal;

    /* Calculate pIq using the equation, pIq = - Ialpha * sinVal + Ibeta * cosVal */
    *pIq = -Ialpha * sinVal + Ibeta * cosVal;
  }

結論
-----

透過幾何分析與數學推導，我們得到了 Park 轉換的標準矩陣。這一變換是交流電機控制中的重要工具，使得三相電機的控制變得更為簡單高效。

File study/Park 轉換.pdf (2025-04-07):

# Park 轉換

## Park 轉換 (Park Transformation) 是電機⼯程中⼀種關鍵的數學⼯具，常⽤於電機控制與向量控制 (Field-Oriented Control, FOC)。其基本概念是將⼆維靜態正交坐標 ( 座標) 轉換⾄⼆維旋轉坐標 ( 座標 )，以便簡化交流電機的控制與分析。

# 幾何原理與座標系統

## 在交流電機控制中，為了便於分析與控制，我們通常使⽤下列兩種不同的坐標系：

## - 座標系：靜態的直角坐標系，通常來⾃於 Clarke 轉換 ，( ) 和 ( ) 代表兩個正交的電壓或 電流分量。 - d-q 座標系：⼀個相對於轉⼦磁場同步旋轉的坐標系，其中 d 軸(Direct Axis) 與磁場對⿑， q 軸 (Quadrature Axis) 則與 d 軸 垂直。

核心概念就是將 Clarke 轉換 後的 | 正交靜⽌座標，透過代⼊旋轉的角速度 | 參數進⾏同步旋轉，
使其投影到 | 旋轉座標系 。在 ⾺達上的角速度 指的是 電角速度(Electrical Angular Velocity)

## 這樣本來觀察的弦波，就會變成直流信號，因為我們觀察的參考座標時刻隨著弦波同步旋轉，達到相對靜⽌ 的效果。

# Park 轉換的推導過程

# 幾何推導

考慮⼀個向量( ) 在 | 坐標系中的表⽰為：
其中 | 與 | 分別是 | 與 | 軸的單位向量。
現在，假設 | 坐標系相對於 | 坐標系旋轉了⼀個角度 | ，我們希望將 | 重新表⽰在 | 坐

## 標系上。

# d-q 坐標軸的表達式

當 dq 坐標系相對於 | 坐標系 順時針旋轉 | 角時，其新的基底向量 (單位向量) 可以表⽰為：
這兩個向量的推導來⾃於標準⼆維旋轉矩陣的概念。若⼀個點 | 逆時針旋轉 | 角後的新坐標
滿⾜：
則相對於 | 坐標系， | 坐標的單位向量由此獲得，可以觀察到，就是只是旋轉⽅式的不同，⼀個

## 逆時針⽅向，⼀個 順時針⽅向。

# 向量投影計算

由於 | 軸的⽅向已知， 在 | 坐標上的投影可以通過 內積 計算：

α − β
d − q
α − β | i | i
α − β | (θ)
d − q

### I α − β

### I = I^ı + I^ȷ

(^ı) | (^ȷ) | (α) | (β)
d − q | α − β | (θ) | (I) | d − q
α − β | (θ)

### ^d = cos θı^ + sin θȷ^ ^q = − sin θı^ + cos θȷ^

(x, y) | (θ) | (x

, y
)
x
y

=

### cos θ −sin θ sin θ cos θ

⎤
⎦

x
y

⎤
⎦
α − β | d − q
d − q | (I) | d − q

## 這兩個⽅程式可以⽤矩陣形式表⽰為：

# 旋轉矩陣的特性

## 上述矩陣是⼀個 正交旋轉矩陣，其特性如下：

## 1. ⾏向量與列向量皆為單位正交向量，確保坐標變換不改變向量⻑度。 2. 逆變換是其轉置，即：

這表⽰若已知 | 坐標，可以逆推回 | 坐標。

# 物理意義與應⽤

## Park 轉換的主要優勢是簡化交流電機的控制。經過變換後：

## - d 軸 分量對應於磁場⽅向的電壓或電流，⽤於控制磁場強度。因為 d 軸 與轉⼦磁場對⿑，調節 影響 磁鏈強度，進⽽影響電機勵磁。 - q 軸 分量對應於垂直於磁場的電壓或電流，⽤於控制轉矩。由於轉矩是由定⼦電流與轉⼦磁場的交互作 ⽤產⽣，因此調節 可以直接影響轉矩。

## 這樣，原本複雜的三相交流電機數學模型轉變為類似直流電機的控制⽅式，使向量控制更加直觀。

# Park 的程式碼實現

## 下⾯是ODrive 使⽤的代碼，位於 FieldOriented::get_alpha_beta_output() 內，函式內進⾏了 Park轉 換 與計算完畢後的 逆Park轉換 。

ODriveIntf::MotorIntf::Error FieldOrientedController::get_alpha_beta_output(
uint32_t output_timestamp, std::optional<float2D>* mod_alpha_beta, std::optional<float>* ibus) {

if (!vbus_voltage_measured_.has_value() || !Ialpha_beta_measured_.has_value()) {
// FOC didn't receive a current measurement yet.
return Motor::ERROR_CONTROLLER_INITIALIZING;
} else if (abs((int32_t)(i_timestamp_ - ctrl_timestamp_)) > MAX_CONTROL_LOOP_UPDATE_TO_CURRENT_UPDATE_DELTA // Data from control loop and current measurement are too far apart.
return Motor::ERROR_BAD_TIMING;
}

// TODO: improve efficiency in case PWM updates are requested at a higher // rate than current sensor updates. In this case we can reuse mod_d and // mod_q from a previous iteration.

if (!Vdq_setpoint_.has_value()) {
return Motor::ERROR_UNKNOWN_VOLTAGE_COMMAND;
} else if (!phase_.has_value() || !phase_vel_.has_value()) { return Motor::ERROR_UNKNOWN_PHASE_ESTIMATE;
} else if (!vbus_voltage_measured_.has_value()) {
return Motor::ERROR_UNKNOWN_VBUS_VOLTAGE;
}

### i = I ⋅ d^ = i cos θ + i sin θ

### i = I ⋅ q^ = − i sin θ + i cos θ

i
i

=

### cos θ sin θ −sin θ cos θ

⎤
⎦
i
i

### cos θ sin θ −sin θ cos θ

⎤
⎦

−
=

### cos θ −sin θ sin θ cos θ

⎤
⎦
d − q | α − β

i

i

auto [Vd, Vq] = *Vdq_setpoint_;
float phase = *phase_;
float phase_vel = *phase_vel_;
float vbus_voltage = *vbus_voltage_measured_;

std::optional<float2D> Idq;

// Park transform
if (Ialpha_beta_measured_.has_value()) {
auto [Ialpha, Ibeta] = *Ialpha_beta_measured_;
float I_phase = phase + phase_vel * ((float)(int32_t)(i_timestamp_ - ctrl_timestamp_) / ( float c_I = our_arm_cos_f32(I_phase);
float s_I = our_arm_sin_f32(I_phase);
Idq = {
c_I * Ialpha + s_I * Ibeta,
c_I * Ibeta - s_I * Ialpha
};
Id_measured_ += I_measured_report_filter_k_ * (Idq->first - Id_measured_); Iq_measured_ += I_measured_report_filter_k_ * (Idq->second - Iq_measured_); } else {
Id_measured_ = 0.0f;
Iq_measured_ = 0.0f;
}

float mod_to_V = (2.0f / 3.0f) * vbus_voltage; float V_to_mod = 1.0f / mod_to_V;
float mod_d;
float mod_q;

if (enable_current_control_) { // Current control mode

if (!pi_gains_.has_value()) {
return Motor::ERROR_UNKNOWN_GAINS;
} else if (!Idq.has_value()) {
return Motor::ERROR_UNKNOWN_CURRENT_MEASUREMENT; } else if (!Idq_setpoint_.has_value()) {
return Motor::ERROR_UNKNOWN_CURRENT_COMMAND;
}

auto [p_gain, i_gain] = *pi_gains_;
auto [Id, Iq] = *Idq;
auto [Id_setpoint, Iq_setpoint] = *Idq_setpoint_;

float Ierr_d = Id_setpoint - Id;
float Ierr_q = Iq_setpoint - Iq;

// Apply PI control (V{d,q}_setpoint act as feed-forward terms in this mode) mod_d = V_to_mod * (Vd + v_current_control_integral_d_ + Ierr_d * p_gain); mod_q = V_to_mod * (Vq + v_current_control_integral_q_ + Ierr_q * p_gain);

// Vector modulation saturation, lock integrator if saturated
// TODO make maximum modulation configurable
float mod_scalefactor = 0.80f * sqrt3_by_2 * 1.0f / std::sqrt(mod_d * mod_d + mod_q * mod_q if (mod_scalefactor < 1.0f) {
mod_d *= mod_scalefactor;
mod_q *= mod_scalefactor;
// TODO make decayfactor configurable v_current_control_integral_d_ *= 0.99f;
v_current_control_integral_q_ *= 0.99f;
} else {
v_current_control_integral_d_ += Ierr_d * (i_gain * current_meas_period); v_current_control_integral_q_ += Ierr_q * (i_gain * current_meas_period); }

} else {
// Voltage control mode

mod_d = V_to_mod * Vd;
mod_q = V_to_mod * Vq;

// Inverse park transform
float pwm_phase = phase + phase_vel * ((float)(int32_t)(output_timestamp - ctrl_timestamp_) float c_p = our_arm_cos_f32(pwm_phase);
float s_p = our_arm_sin_f32(pwm_phase);
float mod_alpha = c_p * mod_d - s_p * mod_q;
float mod_beta = c_p * mod_q + s_p * mod_d;

// Report final applied voltage in stationary frame (for sensorless estimator) final_v_alpha_ = mod_to_V * mod_alpha;
final_v_beta_ = mod_to_V * mod_beta;

*mod_alpha_beta = {mod_alpha, mod_beta};

if (Idq.has_value()) {
auto [Id, Iq] = *Idq;
*ibus = mod_d * Id + mod_q * Iq; power_ = vbus_voltage * (*ibus).value(); }

return Motor::ERROR_NONE;
}

## ⽽下⾯的程式碼來⾃ STM MCSDK v6.2， 因為他的Clarke轉換出來的 ⽅向相反，所以它轉換⽅程式也 需要旋轉

/**
* @brief This function transforms stator values alpha and beta, which
* | belong to a stationary qd reference frame, to a rotor flux
* | synchronous reference frame (properly oriented), so as q and d.
* | d= alpha *sin(theta)+ beta *cos(Theta)
* | q= alpha *cos(Theta)- beta *sin(Theta)
* @param Input: stator values alpha and beta in alphabeta_t format.
* @param Theta: rotating frame angular position in q1.15 format. * @retval Stator values q and d in qd_t format
*/
__weak qd_t MCM_Park(alphabeta_t Input, int16_t Theta)
{
qd_t Output;
int32_t d_tmp_1;
int32_t d_tmp_2;
int32_t q_tmp_1;
int32_t q_tmp_2;
int32_t wqd_tmp;
int16_t hqd_tmp;
Trig_Components Local_Vector_Components;

Local_Vector_Components = MCM_Trig_Functions(Theta);

/* No overflow guaranteed */
q_tmp_1 = Input.alpha * ((int32_t )Local_Vector_Components.hCos);

/* No overflow guaranteed */
q_tmp_2 = Input.beta * ((int32_t)Local_Vector_Components.hSin);

/* Iq component in Q1.15 Format */
#ifndef FULL_MISRA_C_COMPLIANCY_MC_MATH

/* WARNING: the below instruction is not MISRA compliant, user should verify
| that Cortex-M3 assembly instruction ASR (arithmetic shift right) is used by
| the compiler to perform the shift (instead of LSR logical shift right) */
wqd_tmp = (q_tmp_1 - q_tmp_2) >> 15; //cstat !MISRAC2012-Rule-1.3_n !ATH-shift-neg !MISRAC2012-Rule-10.1_R6 #else
wqd_tmp = (q_tmp_1 - q_tmp_2) / 32768;
#endif

i

/* Check saturation of Iq */ if (wqd_tmp > INT16_MAX)
{
hqd_tmp = INT16_MAX;
}
else if (wqd_tmp < (-32768))
{
hqd_tmp = ((int16_t)-32768); }
else
{
hqd_tmp = ((int16_t)wqd_tmp); }

Output.q = hqd_tmp;

if (((int16_t)-32768) == Output.q) {
Output.q = -32767;
}
else
{
/* Nothing to do */
}

/* No overflow guaranteed */
d_tmp_1 = Input.alpha * ((int32_t )Local_Vector_Components.hSin);

/* No overflow guaranteed */
d_tmp_2 = Input.beta * ((int32_t )Local_Vector_Components.hCos);

/* Id component in Q1.15 Format */
#ifndef FULL_MISRA_C_COMPLIANCY_MC_MATH

/* WARNING: the below instruction is not MISRA compliant, user should verify
that Cortex-M3 assembly instruction ASR (arithmetic shift right) is used by
the compiler to perform the shift (instead of LSR logical shift right) */
wqd_tmp = (d_tmp_1 + d_tmp_2) >> 15; //cstat !MISRAC2012-Rule-1.3_n !ATH-shift-neg !MISRAC2012-Rule-10.1_R6 #else
wqd_tmp = (d_tmp_1 + d_tmp_2) / 32768;
#endif

/* Check saturation of Id */
if (wqd_tmp > INT16_MAX)
{
hqd_tmp = INT16_MAX;
}
else if (wqd_tmp < (-32768))
{
hqd_tmp = ((int16_t)-32768); }
else
{
hqd_tmp = ((int16_t)wqd_tmp); }

Output.d = hqd_tmp;

if (((int16_t)-32768) == Output.d) {
Output.d = -32767;
}
else
{
/* Nothing to do */
}

return (Output);

## 下⾯則是 ARM CMSIS DSP Pack 內的轉換函式 Park轉換

/**
* @brief Floating-point Park transform
* @param[in] Ialpha input two-phase vector coordinate alpha
* @param[in] Ibeta | input two-phase vector coordinate beta
* @param[out] pId | points to output | rotor reference frame d
* @param[out] pIq | points to output | rotor reference frame q
* @param[in] sinVal sine value of rotation angle theta
* @param[in] cosVal cosine value of rotation angle theta
* @return none
*
* The function implements the forward Park transform.
*
*/
__STATIC_FORCEINLINE void arm_park_f32(
float32_t Ialpha,
float32_t Ibeta,
float32_t * pId,
float32_t * pIq,
float32_t sinVal,
float32_t cosVal)
{
/* Calculate pId using the equation, pId = Ialpha * cosVal + Ibeta * sinVal */ *pId = Ialpha * cosVal + Ibeta * sinVal;

/* Calculate pIq using the equation, pIq = - Ialpha * sinVal + Ibeta * cosVal */ *pIq = -Ialpha * sinVal + Ibeta * cosVal;
}
結論

## 透過幾何分析與數學推導，我們得到了 Park 轉換的標準矩陣。這⼀變換是交流電機控制中的重要⼯具，使 得三相電機的控制變得更為簡單⾼效。

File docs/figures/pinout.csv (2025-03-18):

# | Label | GPIO_MODE_DIGITAL | GPIO_MODE_ANALOG_IN | GPIO_MODE_UART_A | GPIO_MODE_UART_B | GPIO_MODE_PWM | GPIO_MODE_CAN_A | GPIO_MODE_I2C_A | GPIO_MODE_ENC0 | GPIO_MODE_ENC1 | GPIO_MODE_MECH_BRAKE
0 | not a pin
1 | GPIO1 (+) | general purpose | analog input | **UART_A.TX** |  | PWM0.0 |  |  |  |  | mechanical brake
2 | GPIO2 (+) | general purpose | analog input | **UART_A.RX** |  | PWM0.1 |  |  |  |  | mechanical brake
3 | GPIO3 | general purpose | **analog input** |  | **UART_B.TX** | PWM0.2 |  |  |  |  | mechanical brake
4 | GPIO4 | general purpose | **analog input** |  | **UART_B.RX** | PWM0.3 |  |  |  |  | mechanical brake
5 | GPIO5 | general purpose | **analog input (*)** |  |  |  |  |  |  |  | mechanical brake
6 | GPIO6 (*) (+) | **general purpose** |  |  |  |  |  |  |  |  | mechanical brake
7 | GPIO7 (*) (+) | **general purpose** |  |  |  |  |  |  |  |  | mechanical brake
8 | GPIO8 (*) (+) | **general purpose** |  |  |  |  |  |  |  |  | mechanical brake
9 | M0.A | general purpose |  |  |  |  |  |  | **ENC0.A**
10 | M0.B | general purpose |  |  |  |  |  |  | **ENC0.B**
11 | M0.Z | **general purpose**
12 | M1.A | general purpose |  |  |  |  |  | I2C.SCL |  | **ENC1.A**
13 | M1.B | general purpose |  |  |  |  |  | I2C.SDA |  | **ENC1.B**
14 | M1.Z | **general purpose**
15 | not exposed | general purpose |  |  |  |  | **CAN_A.RX** | I2C.SCL
16 | not exposed | general purpose |  |  |  |  | **CAN_A.TX** | I2C.SDA

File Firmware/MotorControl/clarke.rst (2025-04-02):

Clarke 變換
==============

**1. 為何需要 Clarke 變換？**

在三相平衡交流系統中，通常會有三個相電壓/電流（ :math:`i_A, i_B, i_C` ），它們是彼此相差 120° 的正弦波。然而，這三個變數並非完全獨立，它們本身也受 **克希荷夫電流定律 (KCL)** 限制。
從馬達的三相看，電流一定是任意一相或兩相流入，配合另外兩相或一相流出，所以一定會滿足 **KCL**。

三相電機控制中，三相電流在物理上代表一個旋轉向量( :math:`i_A,i_B,i_C` )，Clarke 變換的目標是把三相電流轉換成二維正交坐標系 ( :math:`i_\alpha,i_\beta` )，這樣可以用二維空間來描述三相電流的變化，可以更容易處理旋轉坐標的問題。

基於 **KCL**，三個變數中只有兩個是獨立的。**Clarke 變換** 的目的就是找到一個 **變換矩陣 T**，將三相電壓/電流 ( :math:`i_A,i_B,i_C` ) 轉換到一個二維的正交 **α-β 靜止坐標系** ( :math:`i_\alpha,i_\beta` ) 中：

.. math::
   \left[
   \begin{matrix}
    i_\alpha \\
    i_\beta
   \end{matrix}
   \right]
   = T *
   \left[
   \begin{matrix}
   i_A \\
   i_B \\
   i_C
   \end{matrix}
   \right]

這樣做的優點是，我們可以使用兩個獨立的變數 :math:`\left(\textbf{i}_\mathbf{\alpha}, \textbf{i}_\mathbf{\beta}\right)` 在二維平面上 **完整地描述** 原始三相系統的電壓/電流資訊，簡化後續的分析和控制。

**2. 幾何直覺**

為了更好地理解 Clarke 變換，我們可以從幾何的角度來看：

-   **原始三相坐標** ( :math:`\mathbf{i_A, i_B, i_C}` )：每一相電流可以想像成對應到一個基底向量，這些向量之間相隔 **120°**。

.. math::
   0 &= i_A + i_B + i_C　\\
   \omega &= 2{\pi}f \\
   i_A &= sin({\omega}t + \theta) \\
   i_B &= sin({\omega}t + \theta + \frac{2\pi}{\sqrt{3}}) \\
   i_C &= sin({\omega}t + \theta - \frac{2\pi}{\sqrt{3}})

-   **目標 α-β 二維坐標系**：我們希望建立一個 **正交基底** 來表示新的二維系統，方便分析：

    -   **α 軸**：方向與 A 相（ :math:`i_A` ）相同。
    -   **β 軸**：方向與 α 軸正交。

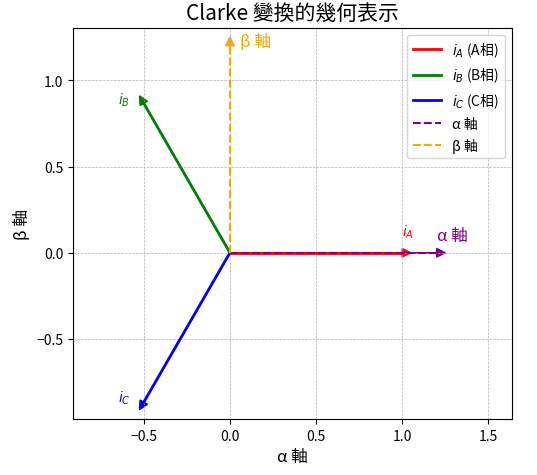
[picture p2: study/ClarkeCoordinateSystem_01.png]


Clarke 變換的幾何意義就是將原始三相系統中的每個相電流 **投影** 到這個新的正交 :math:`\mathbf{\alpha}` 和 :math:`\mathbf{\beta}` 軸上，
得到它們在二維平面上的分量 :math:`i_\mathbf{\alpha}` 和 :math:`i_\mathbf{\beta}`。

**3. 基底向量推導**

根據上述幾何直覺，我們可以推導出 Clarke 變換的基底向量和轉換矩陣：

-   :math:`\textbf{i}_A` **的基底表示**: :math:`\left(\begin{matrix} 1,& 0\end{matrix}\right)`

    將 :math:`i_A 對齊 \alpha軸`, 可以得到下面投影

    .. math::
      \alpha 軸&: cos(0^\circ) &= 1 \\
      \beta 軸&: sin(0^\circ) &= 0

-   :math:`\textbf{i}_B` **的基底表示**: :math:`\left(\begin{matrix} \frac{-1}{2},& \frac{\sqrt{3}}{2}\end{matrix}\right)`

    而 :math:`i_B` 的投影則對應到

    .. math::
      \alpha 軸&: cos(120^\circ) &= \frac{-1}{2} \\
      \beta 軸&: sin(120^\circ) &= \frac{2}{\sqrt{3}}

-   :math:`\textbf{i}_C` **的基底表示**: :math:`\left(\begin{matrix} \frac{-1}{2},& \frac{-\sqrt{3}}{2}\end{matrix}\right)`

    而 :math:`i_C` 的投影則對應到

    .. math::
      \alpha 軸&: cos(240^\circ) &= \frac{-1}{2} \\
      \beta 軸&: sin(240^\circ) &= \frac{-2}{\sqrt{3}}

基於這些基底向量，我們可以 **構造出 Clarke 變換的矩陣 T**：

.. math::

   T =
   \left[
   \begin{matrix}
   1 & -\frac{1}{2} & -\frac{1}{2} \\
   0 & \frac{\sqrt{3}}{2} & -\frac{\sqrt{3}}{2}
   \end{matrix}
   \right]

**4. 矩陣驗證與標準公式**

將三相電流 :math:`[i_A, i_B, i_C]^T` 帶入上述轉換矩陣，我們可以得到 :math:`\mathbf{\alpha}` 和 :math:`\mathbf{\beta}` 分量：

.. math::
   i_\alpha &= i_A - \frac{1}{2}i_B - \frac{1}{2}i_C \\
            &= i_A - \frac{1}{2}(i_B + i_C) \\
   i_\beta &= \frac{\sqrt{3}}{2}i_B - \frac{\sqrt{3}}{2}i_C \\
           &= \frac{\sqrt{3}}{2}(i_B - i_C)

上面的變換只是做了相關相位角度的變換，我們期望轉換完後的　:math:`(i_A, i_B, i_C)` 與 :math:`(i_\alpha, i_\beta)` 的功率大小(RMS)也不變。

.. math::
      {i_A}^2 + {i_B}^2 + {i_C}^2 = {i_{\alpha}}^2 + {i_{\beta}}^2

經過均方根計算比較後，我們得到一個需要相乘縮放係數　:math:`k = \frac{2}{3}` 才能讓信號維持相同振幅(RMS相等)。而基於 **KCL**　原則，則可以進一步簡化為下列形式

.. math::
      i_A &= -(i_B + i_C) \\
      i_\alpha &= k(i_A - \frac{1}{2}(i_B + i_C)) \\
      &= \frac{2}{3}(i_A + \frac{1}{2}i_A) \\
      &= i_A \\
      \\
      i_\beta &= k\frac{\sqrt{3}}{2}(i_B - i_C) \\
      &= \frac{2}{3}\frac{\sqrt{3}}{2}(i_B - i_C) \\
      &=\frac{\sqrt{3}}{3}(i_B - i_C)\quad\dots\text{將分子, 分母同乘}\sqrt{3} 有理化　\\
      &=\frac{1}{\sqrt{3}}(i_B - i_C)

倘若系統不平衡的話，需要另外一個零序分量，我們現在只考慮平衡狀態

**5. Clarke 變換的程式碼實現**

在程式碼中，Clarke 變換通常會接收三相電流 :math:`(i_A, i_B, i_C)` 或電壓作為輸入，並輸出兩相的 :math:`{\alpha}-{\beta}` 分量 :math:`(i_{\alpha}, i_{\beta})` 。以下是ODrive 使用的　Clarke 變換的實現程式碼：

.. code-block:: c++

   Motor::Error AlphaBetaFrameController::on_measurement(
               std::optional<float> vbus_voltage,
               std::optional<std::array<float, 3>> currents,
               uint32_t input_timestamp) {

      std::optional<float2D> Ialpha_beta;

      if (currents.has_value()) {
         // Clarke transform
         Ialpha_beta = {
               (*currents)[0],
               one_by_sqrt3 * ((*currents)[1] - (*currents)[2])
         };
      }

      return on_measurement(vbus_voltage, Ialpha_beta, input_timestamp);
   }

而 STM32 的MCSDK 則使用下面程式碼實做，一樣透過**KCL** 把 :math:`(i_B - i_C)` 轉換為 :math:`(2i_B - i_A)` :

.. code-block:: c++

   /**
   * @brief  This function transforms stator values a and b (which are
   *         directed along axes each displaced by 120 degrees) into values
   *         alpha and beta in a stationary qd reference frame.
   *                               alpha = a
   *                       beta = -(2*b+a)/sqrt(3)
   * @param  Input: stator values a and b in ab_t format.
   * @retval Stator values alpha and beta in alphabeta_t format.
   */
   __weak alphabeta_t MCM_Clarke(ab_t Input)
   {
      alphabeta_t Output;

      int32_t a_divSQRT3_tmp;
      int32_t b_divSQRT3_tmp;
      int32_t wbeta_tmp;
      int16_t hbeta_tmp;

      /* qIalpha = qIas*/
      Output.alpha = Input.a;

      a_divSQRT3_tmp = divSQRT_3 * ((int32_t)Input.a);

      b_divSQRT3_tmp = divSQRT_3 * ((int32_t)Input.b);

      /* qIbeta = -(2*qIbs+qIas)/sqrt(3) */
      #ifndef FULL_MISRA_C_COMPLIANCY_MC_MATH
      /* WARNING: the below instruction is not MISRA compliant, user should verify
         that Cortex-M3 assembly instruction ASR (arithmetic shift right) is used by
         the compiler to perform the shift (instead of LSR logical shift right) */
      //cstat !MISRAC2012-Rule-1.3_n !ATH-shift-neg !MISRAC2012-Rule-10.1_R6
      wbeta_tmp = (-(a_divSQRT3_tmp) - (b_divSQRT3_tmp) - (b_divSQRT3_tmp)) >> 15;
      #else
      wbeta_tmp = (-(a_divSQRT3_tmp) - (b_divSQRT3_tmp) - (b_divSQRT3_tmp)) / 32768;
      #endif

      /* Check saturation of Ibeta */
      if (wbeta_tmp > INT16_MAX)
      {
         hbeta_tmp = INT16_MAX;
      }
      else if (wbeta_tmp < (-32768))
      {
         hbeta_tmp =  ((int16_t)-32768);
      }
      else
      {
         hbeta_tmp = ((int16_t)wbeta_tmp);
      }

      Output.beta = hbeta_tmp;

      if (((int16_t )-32768) == Output.beta)
      {
         Output.beta = -32767;
      }
      else
      {
         /* Nothing to do */
      }

      return (Output);
   }

在 ARM CMSIS-DSP Pack 中則定義為下面，一樣為 :math:`\frac{1}{\sqrt{3}}(2i_B + i_A)`

.. code-block:: c++

   /**
   *
   * @brief  Floating-point Clarke transform
   * @param[in]  Ia       input three-phase coordinate <code>a</code>
   * @param[in]  Ib       input three-phase coordinate <code>b</code>
   * @param[out] pIalpha  points to output two-phase orthogonal vector axis alpha
   * @param[out] pIbeta   points to output two-phase orthogonal vector axis beta
   * @return        none
   */
   __STATIC_FORCEINLINE void arm_clarke_f32(
   float32_t Ia,
   float32_t Ib,
   float32_t * pIalpha,
   float32_t * pIbeta)
   {
     /* Calculate pIalpha using the equation, pIalpha = Ia */
     *pIalpha = Ia;

     /* Calculate pIbeta using the equation, pIbeta = (1/sqrt(3)) * Ia + (2/sqrt(3)) * Ib */
     *pIbeta = ((float32_t) 0.57735026919 * Ia + (float32_t) 1.15470053838 * Ib);
   }

在程式碼中，**三相電流被轉換為兩相靜止坐標系下的電流分量** :math:`i_\alpha` **和** :math:`i_\beta` 。

上面的程式碼中的 ``one_by_sqrt3``　與 ``divSQRT_3`` 都是代表 :math:`\mathbf{\frac{1}{\sqrt{3}}}` ，
並且所有程式碼內都是預先計算好的常數。

總體來說，**Clarke 變換** 是一種重要的坐標轉換手段，它將三相交流系統的變數轉換到一個更易於分析和控制的二維靜止坐標系中，是 **場導向控制 (FOC)** 等現代電機控制技術的基礎。

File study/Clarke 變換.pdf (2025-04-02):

# Clarke 變換

## 1. 為何需要 Clarke 變換？

在三相平衡交流系統中，通常會有三個相電壓/電流（ | ），它們是彼此相差 | 的正弦波。然

## ⽽，這三個變數並⾮完全獨⽴，它們本⾝也受 克希荷夫電流定律 (KCL) 限制。從⾺達的三相看，電流⼀定 是任意⼀相或兩相流⼊，配合另外兩相或⼀相流出，所以⼀定會滿⾜ KCL。

三相電機控制中，三相電流在物理上代表⼀個旋轉向量( | )，Clarke 變換的⽬標是把三相電流轉
換成⼆維正交坐標系 ( | )，這樣可以⽤⼆維空間來描述三相電流的變化，可以更容易處理旋轉坐標的
問題。

## 基於 KCL，三個變數中只有兩個是獨⽴的。Clarke 變換 的⽬的就是找到⼀個 變換矩陣 T，將三相電壓/電

流 ( | ) 轉換到⼀個⼆維的正交 α-β 靜⽌坐標系 ( | ) 中：
這樣做的優點是，我們可以使⽤兩個獨⽴的變數 | 在⼆維平⾯上 完整地描述 原始三相系統的電壓/電

## 流資訊，簡化後續的分析和控制。

## 2. 幾何直覺

## 為了更好地理解 Clarke 變換，我們可以從幾何的角度來看：

- 原始三相坐標 ( | )：每⼀相電流可以想像成對應到⼀個基底向量，這些向量之間相隔 120°。

## - ⽬標 α-β ⼆維坐標系：我們希望建⽴⼀個 正交基底 來表⽰新的⼆維系統，⽅便分析： - α 軸：⽅向與 A 相（ ）相同。 - β 軸：⽅向與 α 軸正交。

i,i,i | 120∘

### i,i,i

i,i

i,i,i | i,i
i
i

= T ∗

| i i i

⎤
⎦

i, i

### i, i, i

### 0 = i + i + i ω = 2πf i = sin(ωt + θ)

### i = sin(ωt + θ +

2π
3 √ )

### i = sin(ωt + θ − 2π

3 √ )

i

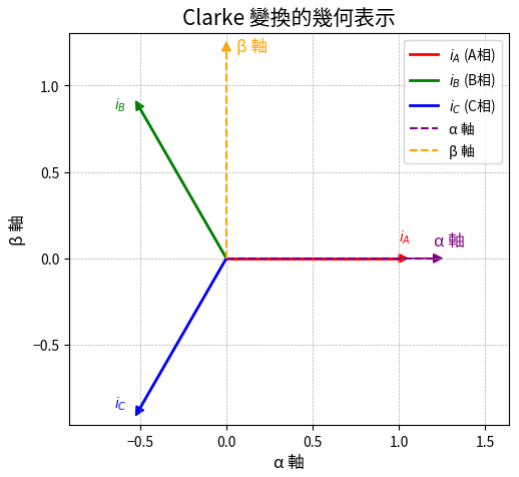
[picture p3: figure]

## Clarke 變換的幾何意義就是將原始三相系統中的每個相電流 投影 到這個新的正交 和 軸上，得到它們 在⼆維平⾯上的分量 和 。

## 3. 基底向量推導

## 根據上述幾何直覺，我們可以推導出 Clarke 變換的基底向量和轉換矩陣：

## - 的基底表⽰:

將 | , 可以得到下⾯投影

## - 的基底表⽰:

## ⽽ 的投影則對應到

## - 的基底表⽰:

## ⽽ 的投影則對應到

## 基於這些基底向量，我們可以 構造出 Clarke 變換的矩陣 T：

## 4. 矩陣驗證與標準公式

α | β
i | i
i | 1, 0

### i 對⿑ α 軸

### α 軸: cos(0∘

) = 1

### β 軸: sin(0∘

) = 0

i | ⁻
, | √

i

### α 軸: cos(120∘

) = −1
2

### β 軸: sin(120∘

) = 2
3 √
i | ⁻
, | − √

i

### α 軸: cos(240∘

) = −1
2

### β 軸: sin(240∘

) = −2
3 √

T =

1 −

−
0 | √
| − √

將三相電流 | 帶⼊上述轉換矩陣，我們可以得到 和 分量：
上⾯的變換只是做了相關相位角度的變換，我們期望轉換完後的 | 與 | 的功率⼤⼩

## (RMS)也不變。

## 經過均⽅根計算⽐較後，我們得到⼀個需要相乘縮放係數 才能讓信號維持相同振幅(RMS相等)。⽽ 基於 KCL 原則，則可以進⼀步簡化為下列形式

## 倘若系統不平衡的話，需要另外⼀個零序分量，我們現在只考慮平衡狀態

## 5. Clarke 變換的程式碼實現

在程式碼中，Clarke 變換通常會接收三相電流 | 或電壓作為輸⼊，並輸出兩相的 | 分量

## 。以下是ODrive 使⽤的 Clarke 變換的實現程式碼：

Motor::Error AlphaBetaFrameController::on_measurement( std::optional<float> vbus_voltage, std::optional<std::array<float, 3>> currents, uint32_t input_timestamp) {

std::optional<float2D> Ialpha_beta;

if (currents.has_value()) {
// Clarke transform
Ialpha_beta = {
(*currents)[0],
one_by_sqrt3 * ((*currents)[1] - (*currents)[2]) };
}

return on_measurement(vbus_voltage, Ialpha_beta, input_timestamp); }

### [i,i,i]

| α | β

i = i − 1
2
| i − 1
| 2

i

= i − 1
2
| (i + i)
i = 3 √

2

i − 3 √

2

| i
= 3 √
| 2 (i − i)
(i,i,i) | (i,i)

i

+ i

+ i

= i

+ i

k =

### i = − (i + i) i = k(i − 1

2

(i + i))

= 2
3

(i +

1
2

i)

= i
i = k 3 √
2 (i − i)

= 2
3

3 √
2 (i − i)
= 3 √

### 3 (i − i) …將分⼦, 分⺟同乘 3

# √ 有理化

= 1
3 √ (i − i)
(i,i,i) | α − β | (
i,i)

⽽ STM32 的MCSDK v6.2 則使⽤下⾯程式碼實做，⼀樣透過 KCL 把 | 轉換為

## 這裡差了⼀個 - 號，表⽰⽅向跟公式相反:

/**
* @brief This function transforms stator values a and b (which are
* | directed along axes each displaced by 120 degrees) into values
* | alpha and beta in a stationary qd reference frame.
* | alpha = a
* | beta = -(2*b+a)/sqrt(3)
* @param Input: stator values a and b in ab_t format.
* @retval Stator values alpha and beta in alphabeta_t format. */
__weak alphabeta_t MCM_Clarke(ab_t Input)
{
alphabeta_t Output;

int32_t a_divSQRT3_tmp;
int32_t b_divSQRT3_tmp;
int32_t wbeta_tmp;
int16_t hbeta_tmp;

/* qIalpha = qIas*/
Output.alpha = Input.a;

a_divSQRT3_tmp = divSQRT_3 * ((int32_t)Input.a);

b_divSQRT3_tmp = divSQRT_3 * ((int32_t)Input.b);

/* qIbeta = -(2*qIbs+qIas)/sqrt(3) */
#ifndef FULL_MISRA_C_COMPLIANCY_MC_MATH

/* WARNING: the below instruction is not MISRA compliant, user should verify that Cortex-M3 assembly instruction ASR (arithmetic shift right) is used by the compiler to perform the shift (instead of LSR logical shift right) */ //cstat !MISRAC2012-Rule-1.3_n !ATH-shift-neg !MISRAC2012-Rule-10.1_R6 wbeta_tmp = (-(a_divSQRT3_tmp) - (b_divSQRT3_tmp) - (b_divSQRT3_tmp)) >> 15; #else
wbeta_tmp = (-(a_divSQRT3_tmp) - (b_divSQRT3_tmp) - (b_divSQRT3_tmp)) / 32768; #endif

/* Check saturation of Ibeta */
if (wbeta_tmp > INT16_MAX)
{
hbeta_tmp = INT16_MAX;
}
else if (wbeta_tmp < (-32768))
{
hbeta_tmp = ((int16_t)-32768); }
else
{
hbeta_tmp = ((int16_t)wbeta_tmp); }

Output.beta = hbeta_tmp;

if (((int16_t )-32768) == Output.beta) {
Output.beta = -32767;
}
else
{
/* Nothing to do */
}

return (Output);
}

(i − i)

−(2i + i)

## 在 ARM CMSIS-DSP Pack 中則定義為下⾯，⼀樣為

/**
*
* @brief Floating-point Clarke transform
* @param[in] Ia | input three-phase coordinate <code>a</code>
* @param[in] Ib | input three-phase coordinate <code>b</code>
* @param[out] pIalpha points to output two-phase orthogonal vector axis alpha
* @param[out] pIbeta | points to output two-phase orthogonal vector axis beta
* @return | none
*/
__STATIC_FORCEINLINE void arm_clarke_f32(
float32_t Ia,
float32_t Ib,
float32_t * pIalpha,
float32_t * pIbeta)
{
/* Calculate pIalpha using the equation, pIalpha = Ia */
*pIalpha = Ia;

/* Calculate pIbeta using the equation, pIbeta = (1/sqrt(3)) * Ia + (2/sqrt(3)) * Ib */ *pIbeta = ((float32_t) 0.57735026919 * Ia + (float32_t) 1.15470053838 * Ib);
}

## 在程式碼中，三相電流被轉換為兩相靜⽌坐標系下的電流分量 和 。

## 上⾯的程式碼中的 one_by_sqrt3 與 divSQRT_3 都是代表 ，並且所有程式碼內都是預先計算好的常

數。

## 總體來說，Clarke 變換 是⼀種重要的坐標轉換⼿段，它將三相交流系統的變數轉換到⼀個更易於分析和控 制的⼆維靜⽌坐標系中，是 場導向控制 (FOC) 等現代電機控制技術的基礎。

√ (2i + i)

i i

√

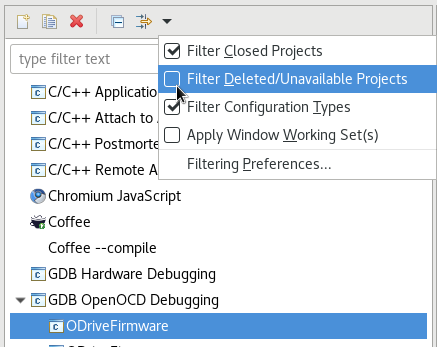
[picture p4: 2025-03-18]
docs/figures/LaunchConfigFilter.png

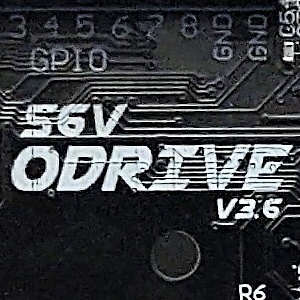
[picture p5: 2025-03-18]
GUI/src/assets/images/56v_300x300.png

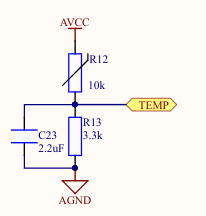
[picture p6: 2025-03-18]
docs/figures/thermistor-voltage-divider.png

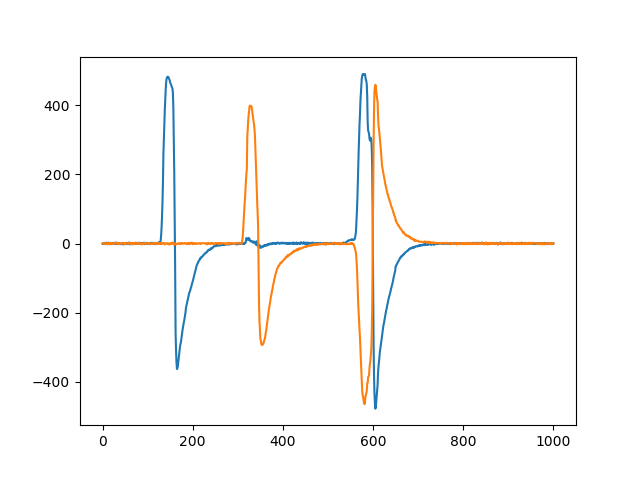
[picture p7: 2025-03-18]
docs/figures/liveplotter-pos-estimate.png

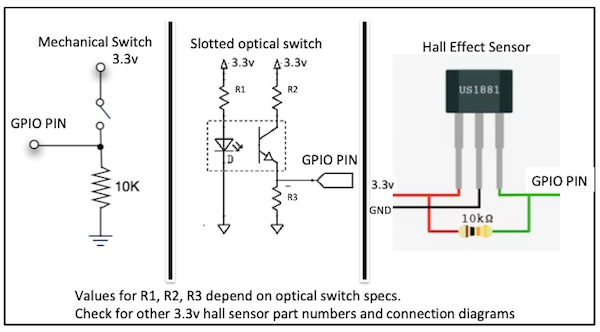
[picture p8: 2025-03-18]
docs/figures/endstop_figure.png

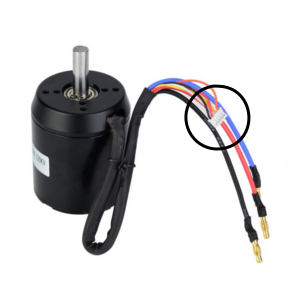
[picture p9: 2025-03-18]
GUI/src/assets/images/hall_effect_300x300.png

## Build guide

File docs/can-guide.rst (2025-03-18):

.. _can-guide:

================================================================================
CAN Bus Guide for ODrive
================================================================================

.. contents::
   :depth: 1
   :local:
   
ODrive v3 supports CAN 2.0b. We've built a :ref:`simple protocol <can-protocol>` (named CANSimple) so that most ODrive functions can be controlled without a full CAN Open or similar stack.  
This guide is intended for beginners to set up CAN on the ODrive and on their host device.  
We will be focusing on Raspberry Pi and Arduino-compatible devices using the MCP2515 CAN Controller.

What is CAN bus?
--------------------------------------------------------------------------------

Borrowing from `Wikipeda <https://en.wikipedia.org/wiki/CAN_bus>`_:

> A Controller Area Network (CAN bus) is a robust vehicle bus standard designed to allow microcontrollers and devices to communicate with each other's applications without a host computer. 
It is a message-based protocol, designed originally for multiplex electrical wiring within automobiles to save on copper, but it can also be used in many other contexts. 
For each device, the data in a frame is transmitted sequentially but in such a way that if more than one device transmits at the same time, the highest priority device can continue while the others back off. 
Frames are received by all devices, including by the transmitting device.

In simple terms, CAN is a way of communicating between many devices over a single twisted pair of wires. 
The signal is transmitted as the difference in voltage between the two wires (differential signalling), which makes it very robust against noise. 
Instead of using a unique address (like I2C) or a select pin (like SPI), CAN *messages* have a unique ID that also acts as the priority. 
At the beginning of a message frame, all devices talk and read at the same time.  As the message ID is transmitted, the lowest value "wins" and that message will be transmitted (ID **0** has the *highest* priority). 
All other devices will wait for the next chance to send.  If two devices send the same message ID at the same time, they will conflict and a bus failure may occur. 
Make sure your devices can never send the same message ID at the same time!

See also `this great article <https://danfosseditron.zendesk.com/hc/en-gb/articles/360042232992-CAN-bus-physical-layer>`_ from Danfoss that quickly describes how to put together the wiring for a CAN bus 

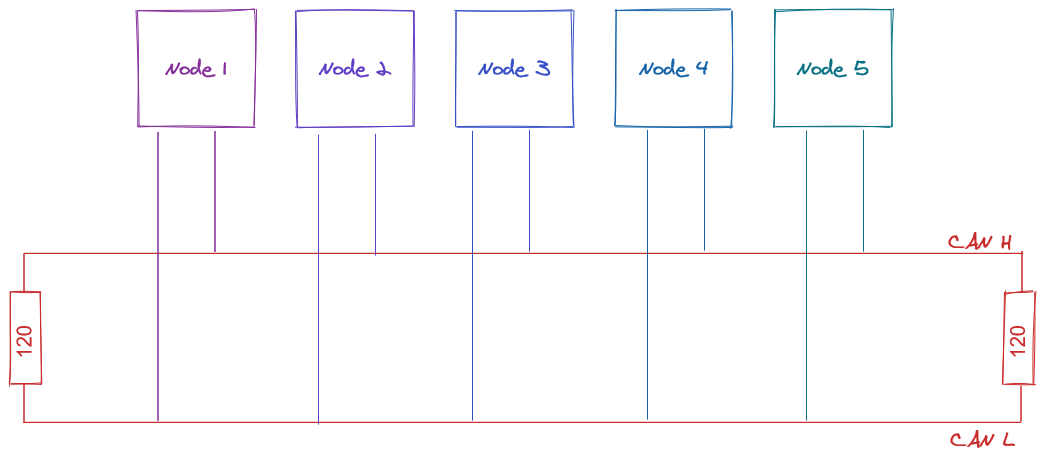
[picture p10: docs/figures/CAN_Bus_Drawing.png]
CAN picture


Why use CAN?
--------------------------------------------------------------------------------

CAN is convenient for its simple and robust Physical Layer (PHY) that requires only a twisted pair of wires and a 120ohm termination resistor at each end. 
It has low jitter and low latency, because there is no host computer.  It is relatively fast (CAN 2.0b supports 1 Mbps).  Messages are easy to configure and load with data. 
Transceivers and controllers are inexpensive and widely available, thanks to its use in automotive.

Hardware Setup
--------------------------------------------------------------------------------

ODrive assumes the CAN PHY is a standard differential twisted pair in a linear bus configuration with 120 ohm termination resistance at each end. 
ODrive versions less than V3.5 include a soldered 120 ohm termination resistor, but ODrive versions V3.5 and greater implement a dip switch to toggle the termination.  
ODrive uses 3.3v as the high output, but conforms to the CAN PHY requirement of achieving a differential voltage > 1.5V to represent a "0".  
As such, it is compatible with standard 5V bus architectures.

Setting up CAN on ODrive
--------------------------------------------------------------------------------

CANSimple breaks the CAN Message ID into two parts:  An axis ID and a command ID.  By default, CAN is enabled on the ODrive, where Axis 0 has ID 0, and Axis 1 has ID 1.  
The ID of each axis should be unique; each should be set via :code:`odrivetool` before connecting to the bus with the command:

.. code:: iPython
    
    <odrv>.<axis>.config.can.node_id = <number>

By default, ODrive supports a value up to 63 (:code:`0x3F`).  See :ref:`can-protocol <can-protocol>` for more information.

You should also set the CAN bus speed on ODrive with the command 

.. code:: iPython
    
    <odrv>.can.config.baud_rate = <number>

.. list-table:: 
   :widths: 25 25
   :header-rows: 1

   * - Speed
     - value
   * - 125 kbps
     - 125000
   * - 250 kbps
     - 250000
   * - 500 kbps
     - 500000
   * - 1000 kbps
     - 1000000

That's it!  You're ready to set up your host device.

Example
~~~~~~~~~~~~~~~~~~~~~~~~~~~~~~~~~~~~~~~~~~~~~~~~~~~~~~~~~~~~~~~~~~~~~~~~~~~~~~~~

.. code:: iPython
    
    odrv0.axis0.config.can.node_id = 0
    odrv0.axis1.config.can.node_id = 1
    odrv0.can.config.baud_rate = 250000

Setting up a Raspberry Pi for CAN Communications
--------------------------------------------------------------------------------

First, you will need a CAN Hat for your Raspberry Pi.  
We are using `this CAN hat <https://www.amazon.com/Raspberry-Long-Distance-Communication-Transceiver-SN65HVD230/dp/B07DQPYFYV>`_.

Setting up the Raspberry Pi essentially involves the following:
#. Enable SPI communications to the MCP2515
#. Install :code:`can-utils` with :code:`apt-get install can-utils`
#. Creating a connection between your application and the :code:`can0` socket

There are many tutorials for this process. 
`This one is pretty good <https://www.hackster.io/youness/how-to-connect-raspberry-pi-to-can-bus-b60235>`_, and `this recent forum post <https://www.raspberrypi.org/forums/viewtopic.php?t=296117>`_ also works.  
However, be careful.  You have to set the correct parameters for the particular CAN hat you're using!

#. Set the correct oscillator value

We configure the MCP2515 in section 2.2 of the tutorial, but the hat we recommend uses a 12MHz crystal instead of a 16 MHz crystal. 
If you're not sure what value to use, the top of the `oscillator <https://en.wikipedia.org/wiki/Crystal_oscillator>`_ will have the value printed on it in MHz.

My Settings:

.. code:: Bash
    
    dtparam=spi-on
    dtoverlay=mcp2515-can0,oscillator=12000000,interrupt=25
    dtoverlay=spi0-hw-cs

#. Use the correct CAN baud rate

By default, ODrive uses 250 kbps (250000) but the tutorial is using 500 kbps.  Make sure you use the value set earlier on the ODrive.

.. code:: Bash

    sudo ip link set can0 up type can bitrate 250000

Wiring ODrive to CAN
~~~~~~~~~~~~~~~~~~~~~~~~~~~~~~~~~~~~~~~~~~~~~~~~~~~~~~~~~~~~~~~~~~~~~~~~~~~~~~~~

The CANH and CANL pins on J2 are used for CAN communication.  Connect CANH to CANH on all other devices, and CANL to CANL.

If your ODrive is the "last" (furthest) device on the bus, you can use the on-board 120 Ohm termination resistor by switching the DIP switch to "CAN 120R". 
Otherwise, add an external resistor.

Follow this recommended wiring schematic for non-isolated systems (most systems):

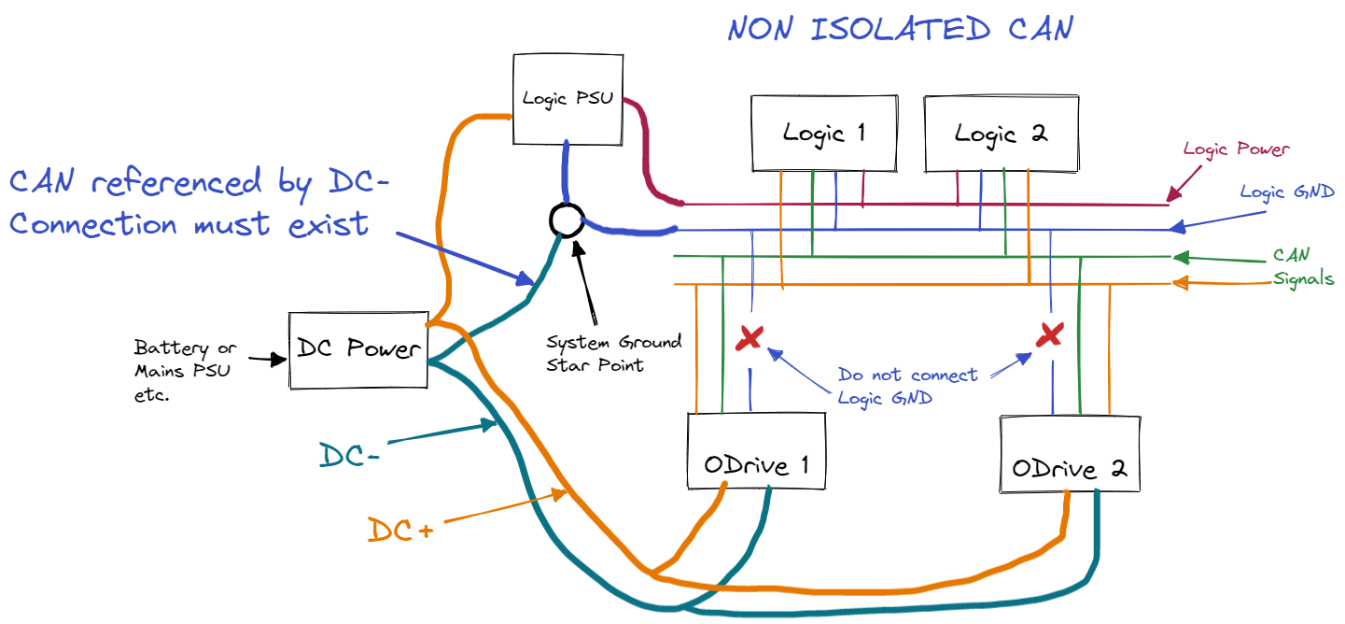
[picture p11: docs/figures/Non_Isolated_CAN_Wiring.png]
CAN Wiring


Verifying Communcation
~~~~~~~~~~~~~~~~~~~~~~~~~~~~~~~~~~~~~~~~~~~~~~~~~~~~~~~~~~~~~~~~~~~~~~~~~~~~~~~~

By default, each ODrive axis will send a heartbeat message at 10Hz.  We can confirm our ODrive communication is working by starting the :code:`can0` interface, and then reading from it:

.. code:: Bash

    sudo ip link set can0 up type can bitrate 250000
    candump can0 -xct z -n 10

This will read the first 10 messages from the ODrive and stop.  If you'd like to see all messages, remove the :code:`-n 10` part (hit CTRL+C to exit).  
The other flags (x, c, t) are adding extra information, colouring, and a timestamp, respectively.

.. code:: Bash

    candump can0 -xct z -n 10
    (000.000000)  can0  RX - -  001   [8]  00 00 00 00 01 00 00 00
    (000.001995)  can0  RX - -  021   [8]  00 00 00 00 08 00 00 00
    (000.099978)  can0  RX - -  001   [8]  00 00 00 00 01 00 00 00
    (000.101963)  can0  RX - -  021   [8]  00 00 00 00 08 00 00 00
    (000.199988)  can0  RX - -  001   [8]  00 00 00 00 01 00 00 00
    (000.201980)  can0  RX - -  021   [8]  00 00 00 00 08 00 00 00
    (000.299986)  can0  RX - -  001   [8]  00 00 00 00 01 00 00 00
    (000.301976)  can0  RX - -  021   [8]  00 00 00 00 08 00 00 00
    (000.399986)  can0  RX - -  001   [8]  00 00 00 00 01 00 00 00
    (000.401972)  can0  RX - -  021   [8]  00 00 00 00 08 00 00 00

Alternatively, if you have python can installed (:code:`pip3 install python-can`), you can use the can.viewer script:

:code:`python3 -m can.viewer -c "can0" -i "socketcan"` which will give you a nice readout.  
See the `python-can docs <https://python-can.readthedocs.io/en/master/scripts.html#can-viewer>`_ for an example.

Commanding the ODrive
--------------------------------------------------------------------------------

Now that we've verified the communication is working, we can try commanding the ODrive. 
Make sure your ODrive is configured and working properly over USB with:code:`odrivetool` before continuing. 
See the :ref:`Getting Started Guide <getting-started>` for help with first-time configuration.

To move the ODrive, we use the command :code:`Set Input Pos`, or cmd ID :code:`0x00C`.  First we create a message with this ID, and then "OR" in the axis ID. 
Then we create an 8-byte array of data with input position that we want, with a float value turned into bytes... this can be a pain though.

DBC Files
--------------------------------------------------------------------------------

A DBC file (.dbc) is a database of all the messages and signals in a CAN protocol. 
This file can be used with Python cantools to serialize and deserialize messages without having to handle the bitshifting etc yourself. 
We have generated a .dbc for CANSimple for you!

* `CANSimple DBC File <https://github.com/odriverobotics/ODrive/tree/master/tools/odrive-cansimple.dbc>`_
* `CANSimple DBC Generator Script <https://github.com/odriverobotics/ODrive/tree/master/tools/create_can_dbc.py>`_

Instead of manually writing values into the data, we can create a dictionary of signal:value pairs and serialize the data according to the database definition.

#. Load the database into memory
#. Use :code:`encode_message()` to get a byte array representation of data for sending
#. Use :code:`decode_message()` to get a dictionary representation of data for receiving

The `CAN DBC Example <https://github.com/odriverobotics/ODrive/blob/master/tools/can_dbc_example.py>`_ script shows you how this can be used.  This is the recommended method of serializing and deserializing.

If you're using C++, then you can use the `CANHelpers <https://github.com/odriverobotics/ODrive/blob/master/Firmware/communication/can/can_helpers.hpp>`_ single-header library to do this instead, although the DBC file isn't used.

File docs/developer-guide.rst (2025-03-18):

.. _developer-guide-doc:

================================================================================
ODrive Firmware Developer Guide
================================================================================

.. contents::
   :depth: 1
   :local:

This guide is intended for developers who wish to modify the firmware of the ODrive.
As such it assumes that you know things like how to use Git, what a compiler is, etc. If that sounds scary, turn around now.

The official releases are maintained on the `master` branch. However since you are a developer, you are encouraged to use the `devel` branch, as it contains the latest features.

The project is under active development, so make sure to check the `Changelog <https://github.com/odriverobotics/ODrive/tree/master/CHANGELOG.md>`_ to keep track of updates.

.. _dev-prereq:

Prerequisites
-------------------------------------------------------------------------------

The recommended tools for ODrive development are:

 * **make**: Used to invoke tup
 * **Tup**: The build system used to invoke the compile commands
 * **ARM GNU Compiler**: For cross-compiling code
 * **ARM GDB**: For debugging the code and stepping through on the device
 * **OpenOCD**: For flashing the ODrive with the STLink/v2 programmer
 * **Python 3**, along with the packages :code:`PyYAML`, :code:`Jinja2` and :code:`jsonschema`: For running the Python tools (:code:`odrivetool`). Also required for compiling firmware.

See below for specific installation instructions for your OS.

Depending on what you're gonna do, you may not need all of the components.

Once you have everything, you can verify the correct installation by running:

.. code:: Bash

  arm-none-eabi-gcc --version
  arm-none-eabi-gdb --version
  openocd --version             # should be 0.10.0 or later
  tup --version                 # should be 0.7.5 or later
  python --version              # should be 3.7 or later

**Installing Prerequisites**

.. tabs::
  .. tab:: Linux (Ubuntu < 20.04)

    .. code:: Bash
      
      sudo add-apt-repository ppa:team-gcc-arm-embedded/ppa

    .. code:: Bash
      
      sudo apt-get update

    .. code:: Bash
      
      sudo apt-get install gcc-arm-embedded

    .. code:: Bash
      
      sudo apt-get install openocd

    .. code:: Bash
      
      sudo apt-get install git-lfs

    .. code:: Bash
      
      sudo add-apt-repository ppa:jonathonf/tup && sudo apt-get update && sudo apt-get install tup

    .. code:: Bash
      
      sudo apt-get install python3 python3-yaml python3-jinja2 python3-jsonschema

  .. tab:: Linux (Ubuntu >= 20.04)

    .. code:: Bash
      
      sudo apt install gcc-arm-none-eabi

    .. code:: Bash
      
      sudo apt install openocd

    .. code:: Bash
      
      sudo apt install git-lfs

    .. code:: Bash
      
      sudo apt install tup

    .. code:: Bash
      
      sudo apt install python3 python3-yaml python3-jinja2 python3-jsonschema

  .. tab:: Arch Linux

    .. code:: Bash
      
      sudo pacman -S arm-none-eabi-gcc arm-none-eabi-binutils

    .. code:: Bash
      
      sudo pacman -S arm-none-eabi-gdb

    .. code:: Bash
      
      sudo pacman -S git-lfs

    .. code:: Bash
      
      sudo pacman -S tup

    .. code:: Bash
      
      sudo pacman -S python python-yaml python-jinja python-jsonschema

    * `OpenOCD AUR package <https://aur.archlinux.org/packages/openocd/>`__

  .. tab:: Mac
    First install `Homebrew <https://brew.sh/>`__ Then you can run these commands in Terminal:

    .. code:: Bash
      
      brew install armmbed/formulae/arm-none-eabi-gcc

    .. code:: Bash
      
      brew install --cask osxfuse && brew install tup

    .. code:: Bash
      
      brew install openocd

    .. code:: Bash
      
      brew install git-lfs

    .. code:: Bash
      
      pip3 install PyYAML Jinja2 jsonschema

  .. tab:: Windows

    .. note:: make sure these programs are not only installed but also added to your `PATH`.

    Some instructions in this document may assume that you're using a bash command prompt, such as the Windows 10 built-in bash or `Git <https://git-scm.com/download/win>`__ bash.

    * `ARM compiler <https://developer.arm.com/open-source/gnu-toolchain/gnu-rm/downloads>`__

      .. note:: 

        After installing, create an environment variable named `ARM_GCC_ROOT` whose value is the path you installed to.  e.g. :code:`C:\Program Files (x86)\GNU Tools Arm Embedded\7 2018-q2-update`.  
        This variable is used to locate include files for the c/c++ Visual Studio Code extension.

      .. note:: 8-2018-q4-major seems to have a bug on Windows.  Please use 7-2018-q2-update.
    * `Tup <http://gittup.org/tup/index.html>`__
    * `GNU MCU Eclipse's Windows Build Tools <https://github.com/gnu-mcu-eclipse/windows-build-tools/releases>`__
    * `Python 3 <https://www.python.org/downloads/>`__
      * Install Python packages: :code:`pip install PyYAML Jinja2 jsonschema`
    * `OpenOCD <https://github.com/xpack-dev-tools/openocd-xpack/releases/>`__
    * `ST-Link/V2 Drivers <https://www.st.com/content/st_com/en/products/development-tools/software-development-tools/stm32-software-development-tools/stm32-utilities/stsw-link009.html>`__

Configuring the Build
--------------------------------------------------------------------------------

To customize the compile time parameters, copy or rename the file :code:`Firmware/tup.config.default` to :code:`Firmware/tup.config` and edit the following parameters in that file:

* **CONFIG_BOARD_VERSION** The board version you're using. Can be `v3.1`, `v3.2`, `v3.3`, `v3.4-24V`, `v3.4-48V`, `v3.5-24V`, `v3.5-48V`, etc. Check for a label on the upper side of the ODrive to find out which version you have. 
  Some ODrive versions don't specify the voltage: in that case you can read the value of the main capacitors: 120uF are 48V ODrives, 470uF are 24V ODrives.

* **CONFIG_DEBUG** Defines whether debugging will be enabled when compiling the firmware; specifically the :code:`-g -gdwarf-2` flags. 
  Note that printf debugging will only function if your tup.config specifies the :code:`USB_PROTOCOL` or :code:`UART_PROTOCOL` as stdout and :code:`DEBUG_PRINT` is defined. 
  See the IDE specific documentation for more information.

You can also modify the compile-time defaults for all :code:`.config` parameters. 
You will find them if you search for :code:`AxisConfig`, :code:`MotorConfig`, etc.

.. _build-and-flash:

Building and Flashing the Firmware
--------------------------------------------------------------------------------

#. Run :code:`make` in the :code:`Firmware` directory.
#. Connect the ODrive via USB and power it up.
#. Flash the firmware using :ref:`odrivetool dfu <firmware-update>`.

.. _flashing-with-an-stlink: 

Flashing using an STLink/v2 
~~~~~~~~~~~~~~~~~~~~~~~~~~~~~~~~~~~~~~~~~~~~~~~~~~~~~~~~~~~~~~~~~~~~~~~~~~~~~~~~

* Connect `GND`, `SWD`, and `SWC` on connector J2 to the programmer. 

  .. note:: Always plug in `GND` first!

* You need to power the board by only **ONE** of the following: VCC(3.3v), 5V, or the main power connection (the DC bus). The USB port (J1) does not power the board.
* Run :code:`make flash` in the :code:`Firmware` directory.

.. note:: If you receive the error `can't find target interface/stlink-v2.cfg` or similar, create and set an environment variable named :code:`OPENOCD_SCRIPTS` to the location of the openocd scripts directory.

If the flashing worked, you can connect to the board using the :ref:`odrivetool <odrivetool-startup>`.

Testing
--------------------------------------------------------------------------------

.. include:: testing.rst

Debugging
--------------------------------------------------------------------------------

If you're using VSCode, make sure you have the Cortex Debug extension, OpenOCD, and the STLink.  
You can verify that OpenOCD and STLink are working by ensuring you can flash code.  
Open the ODrive_Workspace.code-workspace file, and start a debugging session (F5).  
VSCode will pick up the correct settings from the workspace and automatically connect.  
Breakpoints can be added graphically in VSCode.

* Run :code:`make gdb`. This will reset and halt at program start. Now you can set breakpoints and run the program. If you know how to use gdb, you are good to go.

Setting up an IDE
--------------------------------------------------------------------------------

For working with the ODrive code you don't need an IDE, but the open-source IDE VSCode is recommended.  
It is also possible to use Eclipse. If you'd like to go that route, please see the respective configuration document:

* :ref:`Configuring VSCode <configuring-vscode>`
* :ref:`Configuring Eclipse <configuring-eclipse>`

STM32CubeMX
--------------------------------------------------------------------------------

This project uses the STM32CubeMX tool to generate startup code and to ease the configuration of the peripherals. 
You can download it from `here <http://www2.st.com/content/st_com/en/products/development-tools/software-development-tools/stm32-software-development-tools/stm32-configurators-and-code-generators/s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>`___. 
All CubeMX related files are in :code:`Firmware/Board/v3`.

You will likely want the pinout for this process. It is available `here <https://docs.google.com/spreadsheets/d/1QXDCs1IRtUyG__M_9WruWOheywb-GhOwFtfPcHuN2Fg/edit#gid=404444347>`__.

Maintaining Modified Generated Code
~~~~~~~~~~~~~~~~~~~~~~~~~~~~~~~~~~~~~~~~~~~~~~~~~~~~~~~~~~~~~~~~~~~~~~~~~~~~~~~~

When generating the code, STM32CubeMX will nuke everything except some special sections that they provide. 
These sections are marked like `USER CODE BEGIN`...`USER CODE END`.
We used to try to make sure all edits we made to the generated code would only go in these sections, so some code structrure may reflect that.
However over time we realized this will not be tenable, so instead we use git to rebase all changes of the generated code whenever we need to regenerate it.
We use two special branches that will help us to do this, they are :code:`STM32CubeMX-start` and :code:`STM32CubeMX-end`.
How to use these is shown in the following example.

.. note:: 
  Due to how this rebasing is done, all development that changes the generated code should be done directly on :code:`STM32CubeMX-end`, and not based on :code:`devel`, then follow step 4 below to carry them over to your feature branch. If you did some changes to the generated code based from :code:`devel`, you need to cherry pick just those changes over to :code:`STM32CubeMX-end`.

#. **Ensuring a clean slate**

  * We do all changes to the STM32CubeMX config and regenerate the code on top of :code:`STM32CubeMX-start`.
    * :code:`git checkout STM32CubeMX-start`

  * Run stm32cubeMX and load the :code:`Firmware/Board/v3/Odrive.ioc` project file.
    * If the tool asks if you wish to migrate to a new version, choose to download the old firmware package (unless you want to use the latest libraries)
  
  * Without changing any settings, press :code:`Project -> Generate code`.
  * You may need to let it download some drivers and such.
  * STM32CubeMX may now have a newer version of some of the libraries, so there may be changes to the generated code even though we didn't change any settings. We need to check that everything is still working, and hence check in the changes:
  * :code:`git config --local core.autocrlf input` - This will tell git that all files should be checked in with LF endings (CubeMX generates CRLF endings).
  * :code:`git diff` - Ignore the pile of line ending warnings.
  * If you feel qualified: you can now ispect if CubeMX introduced something stupid. If there were any changes, and they look acceptable, we should commit them:
    
    * :code:`git commit -am "Run STM32CubeMX v1.21"` - Replace with actual version of CubeMX

#. **Making Changes to the STM32CubeMX Config**

  * After completing the above steps, make sure the working directory is clean:
    * :code:`git status` should include "nothing to commit, working tree clean"

  * Make your changes in STM32CubeMX, save the project and generate the code. (:code:`Project -> Generate code`)
  * :code:`git diff` - Check that the introduced changes are as expected
  * If everything looks ok, you can commit your changes.

#. **Rebasing the Modifications to the Generated Code**

  * :code:`git checkout STM32CubeMX-end`
  * :code:`git rebase STM32CubeMX-start`
  * Make sure the rebase finishes, fixing any conflicts that may arise

#. **Merge New STM32CubeMX Code to your Feature Branch**

  Simply merge the new state at:code: `STM32CubeMX-end` into your feature branch.
  * :code:`git checkout your-feature`
  * :code:`git merge STM32CubeMX-end`

#. **Pushing back Upstream**

  * Generate a PR like normal for your feature.
  * Make sure youhave pushed to the :code:`STM32CubeMX-start` and :code:`STM32CubeMX-end` branches on your fork.
  * Make a note in your PR to the maintainer that they need to update the STM32CubeMX branches when they merge the PR.

Troubleshooting
--------------------------------------------------------------------------------

:code:`LIBUSB_ERROR_IO` when flashing with the STLink/v2
~~~~~~~~~~~~~~~~~~~~~~~~~~~~~~~~~~~~~~~~~~~~~~~~~~~~~~~~~~~~~~~~~~~~~~~~~~~~~~~~

**Problem:** when I try to flash the ODrive with the STLink using :code:`make flash` I get this error:

.. code:: Bash

  Open On-Chip Debugger 0.10.0
  Licensed under GNU GPL v2
  For bug reports, read
    http://openocd.org/doc/doxygen/bugs.html
  Info : auto-selecting first available session transport "hla_swd". To override use 'transport select <transport>'.
  Info : The selected transport took over low-level target control. The results might differ compared to plain JTAG/SWD
  adapter speed: 2000 kHz
  adapter_nsrst_delay: 100
  none separate
  Info : Unable to match requested speed 2000 kHz, using 1800 kHz
  Info : Unable to match requested speed 2000 kHz, using 1800 kHz
  Info : clock speed 1800 kHz
  Error: libusb_open() failed with LIBUSB_ERROR_IO
  Error: open failed
  in procedure 'init' 
  in procedure 'ocd_bouncer'

**Solution:**
This happens from time to time.

#. Unplug the STLink and all ODrives from your computer
#. Power off the ODrive you're trying to flash
#. Plug in the STLink into your computer
#. Power on the ODrive
#. Run :code:`make flash` again

:code:`Cannot identify target as a STM32 family` when flashing using openocd
~~~~~~~~~~~~~~~~~~~~~~~~~~~~~~~~~~~~~~~~~~~~~~~~~~~~~~~~~~~~~~~~~~~~~~~~~~~~~~~~

**Problem:** When I try to flash ODrive v4.1 with :code:`make flash` then I get:

.. code:: Bash

  [...]
  ** Programming Started **
  auto erase enabled
  Info : device id = 0x10006452
  Warn : Cannot identify target as a STM32 family.
  Error: auto_probe failed
  embedded:startup.tcl:487: Error: ** Programming Failed **
  in procedure 'program' 
  in procedure 'program_error' called at file "embedded:startup.tcl", line 543
  at file "embedded:startup.tcl", line 487

**Solution:**
Compile and install a recent version of openocd from source. 
The latest official release (0.10.0 as of Nov 2020) doesn't support the STM32F722 yet.

.. code:: Bash

  sudo apt-get install libtool libusb-1.0
  git clone https://git.code.sf.net/p/openocd/code openocd
  cd openocd/
  ./bootstrap
  ./configure --enable-stlink
  make
  sudo make install

Documentation
--------------------------------------------------------------------------------
.. admonition:: In Progress 

  ODrive documentation is now built using `Sphinx <https://www.sphinx-doc.org/en/master/>`_.

  * Prerequisites:

    * Install Sphinx: :code:`pip install -U sphinx`
    * Install packages: :code:`pip install sphinx-copybutton sphinx-panels sphinx-rtd-theme`

  * Run :code:`make html` within the :kbd:`./docs/reStructuredText` folder 
  * Open :kbd:`./docs/reStructuredText/_build/index.html` to view

.. _modifying-libfibre:

Modifying libfibre
--------------------------------------------------------------------------------

If you need to modify libfibre add :code:`CONFIG_BUILD_LIBFIBRE=true` to your tup.config and rerun :code:`make`. 
After this you can start :code:`odrivetool` (on your local PC) and it will use the updated libfibre.

To cross-compile libfibre for the Raspberry Pi, run :code:`make libfibre-linux-armhf` or :code:`make libfibre-all`. 
This will require a docker container. See ;:ref:`fibre-cpp readme <../Firmware/fibre-cpp/README.md>` for details.

.. code:: Bash

  docker run -it -v "$(pwd)":/build -v /tmp/build:/build/build -w /build fibre-compiler configs/linux-armhf.config

If you're satisfied with the changes don't forget to generate binaries for all
supported systems using :code:`make libfibre-all`.

Releases
--------------------------------------------------------------------------------

We use GitHub Releases to provide firmware releases.

#. Cut off the changelog to reflect the new release
#. Merge the release candidate into master.
#. Push a (lightweight) tag to the master branch. Follow the existing naming convention.
#. If you changed something in libfibre, regenerate the binaries using :code:`make libfibre-all`. 
   See :ref:`Modifying libfibre <modifying-libfibre>` for details.
#. Push the python tools to PyPI (see setup.py for details).
#. Edit the release on GitHub to add a title and description (copy&paste from changelog).

Code Maintenance Notes
--------------------------------------------------------------------------------

The cortex M4F processor has hardware single precision float unit. However double precision operations are not accelerated, and hence should be avoided. 
The following regex is helpful for cleaning out double constants:

find: 

.. code::

  ([-+]?[0-9]+\.[0-9]+(?:[eE][-+]?[0-9]+)?)([^f0-9e])

replace: 

  .. code::

    \1f\2

Notes for Contributors
--------------------------------------------------------------------------------

In general the project uses the `Google C++ Style Guide <https://google.github.io/styleguide/cppguide.html>`__ with a few exceptions:

 * The default indentation is 4 spaces.
 * The 80 character limit is not very strictly enforced, merely encouraged.
 * The file extensions `*.cpp` and `*.hpp` are used instead of `*.cc` and `*.h`.

Your help is welcome! However before you start working on a feature/change that will take you a non-negligible amount of time and that you plan to upstream please discuss your plans with us on GitHub or Discord. 
This will ensure that your implementation is in line with the direction that ODrive is going.

When filing a PR please go through this checklist:

 * Make sure you adhere to the same coding style that we use (see note above).
 * Update CHANGELOG.md.
 * If you removed/moved/renamed things in :code:`odrive-interface.yaml` make sure to add corresponding bullet points tp the "API migration notes" section in the changelog. Use git to compare against the :code:`devel` branch.
 * Also, for each removed/moved/renamed API item use your IDE's search feature to search for occurrences of this name. Update the places you found (this will usually be documentation and test scripts).
 * If you added things to :code:`odrive-interface.yaml` make sure the new things have decent documentation in the YAML file. We don't expect 100% coverage but use good sense of what to document.
 * Make sure your PR doesn't contain spurious changes that unnecessarily add or remove whitespace. These add noise and make the reviewer's lifes harder.
 * If you changed any enums in :code:`odrive-interface.yaml`, make sure you update `enums.py <https://github.com/odriverobotics/ODrive/blob/master/tools/odrive/enums.py>`_ and `ODriveEnums.h <https://github.com/odriverobotics/ODrive/blob/master/Arduino/ODriveArduino/ODriveEnums.h>`_. 
   The file includes instructions on how to do this. Check the diff to verify that none of the existing enumerators changed their value.

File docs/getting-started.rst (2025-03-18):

================================================================================
Getting Started
================================================================================

.. contents::
   :depth: 1
   :local:

Hardware Requirements
--------------------------------------------------------------------------------

**You will need**

* One or two `brushless motors <https://docs.google.com/spreadsheets/d/12vzz7XVEK6YNIOqH0jAz51F5VUpc-lJEs3mmkWP1H4Y>`__. It is fine, even recommended, to start testing with just a single motor and encoder.
* One or two `encoder(s) <https://docs.google.com/spreadsheets/d/1OBDwYrBb5zUPZLrhL98ezZbg94tUsZcdTuwiVNgVqpU>`__.
* A power supply (12V-24V for the 24V board variant, 12V-56V for the 56V board variant). A battery is also fine. Some advice on choosing a power supply can be found `here <https://things-in-motion.blogspot.com/2018/12/how-to-select-right-power-source-for.html>`__.

.. dropdown:: What voltage variant do I have?

    On all ODrives shipped July 2018 or after have a silkscreen label clearly indicating the voltage variant.

    ODrives before this may or may not have this label. If you don't have a label, then you can look at the bus capacitors (8 gray cylinder components on the underside of the board). If they read 470uF, you have a 24V version; if they read 120uF you have a 48V version.
 
* A power resistor. A good starting point would be the 50W resistor included with your ODrive.

.. dropdown:: Do I really need a power resistor? What values to choose?

    If you don't have a brake resistor, the ODrive will pump excess power back into the power supply during deceleration to achieve the desired deceleration torque. If your power supply doesn't eat that power (which it won't if it's not a battery), the bus voltage will inevitebly rise. If you're unlucky this will break the power supply.
    At some point, the ODrive's overvoltage protection will trip, after which both motors will be allowed to spin freely. Depending on your machine, this may or may not be a problem.

    The power resistor values you need depends on your motor setup, and peak/average deceleration power.

    To be on the safe side, think about what speed and current limits you want to set for the motor.

    When braking at max speed and with maximum motor current, the power that is dissipated in the power resistor can be calulated as: `P_brake = V_emf * I_motor` where `V_emf = motor_rpm / motor_kv`.

Wiring up the ODrive
~~~~~~~~~~~~~~~~~~~~~~~~~~~~~~~~~~~~~~~~~~~~~~~~~~~~~~~~~~~~~~~~~~~~~~~~~~~~~~~~

.. warning:: Firmware, software, and documentation is intended for use with ODrive motor controllers purchased from odriverobotics.com. ODrive Robotics does not sell products through any channel other than odriverobotics.com. We do not provide support for ODrives purchased elsewhere.

.. warning:: Make sure you have a good mechanical connection between the encoder and the motor, slip can cause disastrous oscillations or runaway.

All non-power I/O is 3.3V output and 5V tolerant on input, on ODrive v3.3 and newer.

Wiring up the motors
********************************************************************************

Connect the motor phases into the 3-phase screw terminals. It is not recommended to use a clip-on connector such as an alligator clip, as this can cause issues with the phase resistance/inductance measurements. 

Wiring up the encoders
********************************************************************************

Connect the encoder(s) to J4. The A,B phases are required, and the Z (index pulse) is optional. The A,B and Z lines have 3.3k pull up resistors, for use with open-drain encoder outputs. For single ended push-pull signals with weak drive current (\<4mA), you may want to desolder the pull-ups.

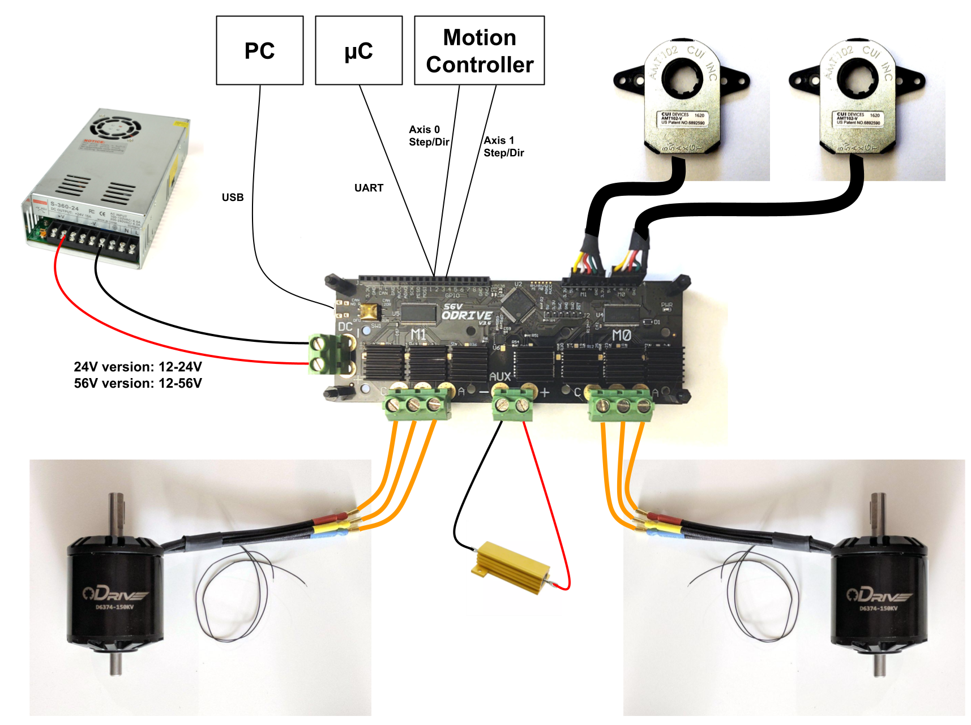
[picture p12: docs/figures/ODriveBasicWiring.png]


Safety & Power UP
********************************************************************************
.. warning:: Always think safety before powering up the ODrive if motors are attached. Consider what might happen if the motor spins as soon as power is applied.

* Unlike some devices, the ODrive does not recieve power over the USB port so the 24/56 volt power input is required even just to communicate with it using USB. It is ok to power up the ODrive before or after connecting the USB cable.

* To power up the ODrive, connect the power source to the DC terminals. Make sure to pay attention to the polarity. Try to connect the power source first and then turn it on to avoid inrush current. If this can't be avoided then a small spark is normal. This is caused by the capacitors charging up.

* Make sure to avoid a ground loop! See the :ref:`ground loop page <ground-loops>` for details.

.. _install-odrivetool:

Downloading and Installing :code:`odriveool`
~~~~~~~~~~~~~~~~~~~~~~~~~~~~~~~~~~~~~~~~~~~~~~~~~~~~~~~~~~~~~~~~~~~~~~~~~~~~~~~~

Most instructions in this guide refer to a utility called `odrivetool`, so you should install that first.

.. tabs::
    .. tab:: Windows

        #. Install Python 3

            We recommend the Anaconda distribution because it packs a lot of useful scientific tools, however you can also install the standalone python.
            
            * **Anaconda**: Download the installer from `here <https://www.anaconda.com/download/#windows>`__. Execute the downloaded file and follow the instructions.
            * **Standalone Python**: Download the installer for 3.8.6 from `here <https://www.python.org/downloads/release/python-386/>`__. Execute the downloaded file and follow the instructions.  As of Oct 2020, Matplotlib (required by odrivetool) had not been updated to work with 3.9, so please use 3.8.6.
            * If you have Python 2 installed alongside Python 3, replace :code:`pip` by :code:`C:\Users\YOUR_USERNAME\AppData\Local\Programs\Python\Python36-32\Scripts\pip`. If you have trouble with this step then refer to `this walkthrough <https://www.youtube.com/watch?v=jnpC_Ib_lbc>`__.

        #. Launch the command prompt.

            * **Anaconda**: In the start menu, type :code:`Anaconda Prompt` :kbd:`Enter`
            * **Standalone Python** In the start menu, type :code:`cmd` :kbd:`Enter`

        #. Install odrivetool by running      

            .. code-block:: Bash
                
                pip install --upgrade odrive

    .. tab:: macOS

        We are going to run the following commands for installation in Terminal.

        #. If you don't already have it, install homebrew: 

            .. code-block:: Bash

                /usr/bin/ruby -e "$(curl -fsSL https://raw.githubusercontent.com/Homebrew/install/master/install)"

        #. Install python:

            .. code-block:: Bash

                brew install python

            .. note::
                If you get an error saying `python 2.7.* is already installed`, then upgrade to Python 3 by running:  

                .. code-block:: Bash

                    brew upgrade python

        #. Install libusb:

            libusb is required for odrivetool to communicate with the ODrive:
        
            .. code-block:: Bash

                brew install libusb

            .. _installodrivetool:

        #. Install odrivetool:

            Now that you have Python 3 and all the package managers, run:
        
            .. code-block:: Bash

                pip3 install --upgrade odrive

        **Troubleshooting**

        #. Permission Errors:

            Just run the previous command in sudo

            .. code-block:: Bash

                sudo pip3 install --upgrade odrive

        #. Dependency Errors:

            If the installer doesn't complete and you get a dependency error (Ex. :code:`No module...`` or :code:`module_name not found`), run the command
            
            .. code-block:: Bash

                sudo pip3 install module_name

            and try to :ref:`install odrivetool <installodrivetool>` again.

        #. Other Install Errors: 

            If the installer fails at installing dependencies, try

            .. code-block:: Bash

                sudo pip3 install odrive --no-deps

            .. warning:: If you do this, brace yourself for runtime errors when you run :code:`odrivetool` (the basic functionality should work though).

    .. tab:: Linux

        #. `Install Python 3 <https://www.python.org/downloads/>`__. 
        
            For example, on Ubuntu, run

            .. code-block:: Bash

                sudo apt install python3 python3-pip

        #. Install odrivetool by opening a terminal and typing

            .. code-block:: Bash

                sudo pip3 install --upgrade odrive

            .. note:: This should automatically add the udev rules. If this fails for some reason you can add them manually:

                .. code-block:: Bash

                    echo 'SUBSYSTEM=="usb", ATTR{idVendor}=="1209", ATTR{idProduct}=="0d[0-9][0-9]", MODE="0666"' | sudo tee /etc/udev/rules.d/91-odrive.rules
                    sudo udevadm control --reload-rules
                    sudo udevadm trigger

        .. admonition:: **Ubuntu**, **Raspbian**

            If you can't invoke :code:`odrivetool` at this point, try adding :code:`~/.local/bin` to your :code:`$PATH`, `see related bug <https://unix.stackexchange.com/a/392710/176715>`__. 
            This is done for example by running :code:`nano ~/.bashrc`, scrolling to the bottom, pasting :code:`export PATH=$PATH:~/.local/bin`, and then saving and closing, then close and reopen the terminal window.

Firmware
~~~~~~~~~~~~~~~~~~~~~~~~~~~~~~~~~~~~~~~~~~~~~~~~~~~~~~~~~~~~~~~~~~~~~~~~~~~~~~~~

To simplify the start up procedure we suggest using the latest firmware verion. Please follow the instructions :ref:`here <firmware-update>` to make sure your firmware is up to date.

.. admonition:: **ODrive v3.5 and later**

    Your board should come preflashed with the latest firmware. If you run into problems, check your firmware version and upgrade if possible.

.. admonition:: **ODrive v3.4 and earlier**

    Your board does **not** come preflashed with any firmware. Follow the instructions :ref:`here <st-link-flash>` on the ST Link procedure before you continue.

.. _odrivetool-startup:

Start :code:`odrivetool`
--------------------------------------------------------------------------------

* To launch the main interactive ODrive tool, type :code:`odrivetool` and :kbd:`Enter`. 
* Connect your ODrive and wait for the tool to find it. If it dos not connect after a few seconds refer to the :ref:`troubleshooting guide <troubleshooting>`. 
* Now you can, for instance type :code:`odrv0.vbus_voltage` :kbd:`Enter` to inspect the boards main supply voltage.

It should look something like this:

.. code:: iPython

    ODrive control utility v0.5.4
    Please connect your ODrive.
    Type help() for help.

    Connected to ODrive 306A396A3235 as odrv0
    In [1]: odrv0.vbus_voltage
    Out[1]: 11.97055721282959

The tool you're looking at is a fully capable Python command prompt, so you can type any valid python code.
You can read more about :code:`odrivetool` :ref:`here <odrivetool-doc>`.

.. _motor-config:

Motor Configuration
--------------------------------------------------------------------------------

.. warning:: Read this section carefully, else you risk breaking something.

Configuration of a motor is done within the :code:`odrivetool` console, type :code:`odrivetool` and :kbd:`Enter` to launch. Make sure you have completed :ref:` Start odrivetool <odrivetool-startup>` before continuing.

This section assumes that the motor being configured is connected to the ODrive as M0 (:code:`axis0`). To configure M1, simply replace all instances of :code:`axis0` with :code:`axis1`. 

If any of the following steps fail, print the errors by running :code:`dump_errors(odrv0)` and refer to the :ref:`Error codes <error-codes>` section for debugging.
Once the error(s) have been identified and corrected, run :code:`odrv0.clear_errors()` to clear them before moving forward.

.. admonition:: Working on a hoverboard?

    There is a :ref:`separate guide <hoverboard-doc>` specifically for hoverboard motors

Setting the Limits
~~~~~~~~~~~~~~~~~~~~~~~~~~~~~~~~~~~~~~~~~~~~~~~~~~~~~~~~~~~~~~~~~~~~~~~~~~~~~~~~

With :code:`odrivetool` open you can assign variables directly by name.
For instance, to set the current limit of M0 to 10A you would type

.. code:: iPython

    odrv0.axis0.motor.config.current_lim = 10

Current limit
*********************************************************************************

    The default current limit, for safety reasons, is set to 10A. This is quite weak, but good for making sure the drive is stable. 
    To change the current limit, 

    .. code:: iPython

        odrv0.axis0.motor.config.current_lim = val

    Once you have tuned the ODrive, you can increase this to 60A to increase performance.   

    .. dropdown:: Need more than 60A?

        For current limits above 60A, you must change the current amplifier gains. 
        You do this by requesting a different current range. i.e. for 90A on M0

        .. code:: iPython

            odrv0.axis0.motor.config.requested_current_range = 90   

        then :ref:`save the configuration and reboot <save-config>` as the gains are written out to the DRV (MOSFET driver) only during startup.
    
    .. Note:: The motor current and the current drawn from the power supply is not the same in general. You should not look at the power supply current to see what is going on with the motor current.*

        .. dropdown:: Ok, so tell me how it actually works then...

            The current in the motor is only connected to the current in the power supply `sometimes` and other times it just cycles out of one phase and back in the other. 
            This is what the modulation magnitude is (sometimes people call this duty cycle, but that's a bit confusing because we use `SVM <https://www.mathworks.com/solutions/power-electronics-control/space-vector-modulation.html>`__ not straight PWM). 
            When the modulation magnitude is 0, the average voltage seen across the motor phases is 0, and the motor current is never connected to the power supply. 
            When the magnitude is 100%, it is always connected, and at 50% it's connected half the time, and cycled in just the motor half the time.

            The largest effect on modulation magnitude is speed. There are other smaller factors, but in general: if the motor is still it's not unreasonable to have 50A in the motor from 5A on the power supply. 
            When the motor is spinning close to top speed, the power supply current and the motor current will be somewhat close to each other.

Velocity limit
*********************************************************************************

The motor will be limited to this speed in [turn/s]. Again the default value is quite slow.

.. code:: iPython
    
    odrv0.axis0.controller.config.vel_limit = 2

Calibration Current
*********************************************************************************

You can change :code:`odrv0.axis0.motor.config.calibration_current` [A] to the largest value you feel comfortable leaving running through the motor continuously when the motor is stationary. 
If you are using a small motor (i.e. 15A current rated) you may need to reduce :code:`calibration_current` to a value smaller than the default.

Setting Other Hardware Parameters
~~~~~~~~~~~~~~~~~~~~~~~~~~~~~~~~~~~~~~~~~~~~~~~~~~~~~~~~~~~~~~~~~~~~~~~~~~~~~~~~

Enable Brake Resistor
*********************************************************************************

Set this to `True` if using a brake resistor. You need to :ref:`save the configuration and reboot <save-config>` the ODrive for this to take effect.

.. code:: iPython

    odrv0.config.enable_brake_resistor

Brake Resistor Value
*********************************************************************************

This is the resistance [Ohms] of the brake resistor. You can leave this at the default setting if you are not using a brake resistor.

.. code:: iPython
    
    odrv0.config.brake_resistance

.. note:: There may be some extra resistance in your wiring and in the screw terminals, so if you are getting issues while braking you may want to increase this parameter by around 0.05 ohm.

Negative Current
*********************************************************************************

This is the amount of current [Amps] allowed to flow back into the power supply. The convention is that it is negative. By default, it is set to a conservative value of 10mA. If you are using a brake resistor and getting :code:`DC_BUS_OVER_REGEN_CURRENT` errors, raise it slightly. 
If you are not using a brake resistor and you intend to send braking current back to the power supply, set this to a safe level for your power source.

.. code:: iPython

    odrv0.config.dc_max_negative_current

Pole Pairs
*********************************************************************************

This is the number of **magnet poles** in the rotor, **divided by two**. To find this, you can simply count the number of permanent magnets in the rotor, if you can see them.

.. code:: iPython
    
    odrv0.axis0.motor.config.pole_pairs

.. Note:: This is **not** the same as the number of coils in the stator.

A good way to find the number of pole pairs is with a current limited power supply. Connect any two of the three phases to a power supply outputting around 2A, spin the motor by hand, and count the number of detents. 
This will be the number of pole pairs. If you can't distinguish the detents from the normal cogging present when the motor is disconnected, increase the current.
Another way is sliding a loose magnet in your hand around the rotor, and counting how many times it stops. This will be the number of `pole pairs`. If you use a ferrous piece of metal instead of a magnet, you will get the number of `magnet poles`.

Torque Constant
*********************************************************************************

This is the ratio of torque produced by the motor per Amp of current delivered to the motor. This should be set to **8.27 / (motor KV)**.

.. code:: iPython
    
    odrv0.axis0.motor.config.torque_constant

If you decide that you would rather command torque in units of Amps, you could simply set the torque constant to 1.

Motor Type
*********************************************************************************

This is the type of motor being used. Currently two types of motors are supported: High-current motors (`MOTOR_TYPE_HIGH_CURRENT, [0]`) and gimbal motors (`MOTOR_TYPE_GIMBAL, [2]`).

.. code:: iPython

    odrv0.axis0.motor.config.motor_type

.. dropdown:: Which :code:`motor_type` to choose?

    If you're using a regular hobby brushless motor like `this <https://hobbyking.com/en_us/turnigy-aerodrive-sk3-5065-236kv-brushless-outrunner-motor.html>`__ one, you should set :code:`motor_mode` to :code:`MOTOR_TYPE_HIGH_CURRENT`. 
    For low-current gimbal motors like `this <https://hobbyking.com/en_us/turnigy-hd-5208-brushless-gimbal-motor-bldc.html>`__ one, you should choose :code:`MOTOR_TYPE_GIMBAL`. Do not use :code:`MOTOR_TYPE_GIMBAL` on a motor that is not a gimbal motor, as it may overheat the motor or the ODrive.

    **Further detail:**
    If 100's of mA of current noise is "small" for you, you can choose :code:`MOTOR_TYPE_HIGH_CURRENT`.
    If 100's of mA of current noise is "large" for you, and you do not intend to spin the motor very fast (Ω * L << R), and the motor is fairly large resistance (1 ohm or larger), you can chose :code:`MOTOR_TYPE_GIMBAL`.
    If 100's of mA current noise is "large" for you, `and` you intend to spin the motor fast, then you need to replace the shunt resistors on the ODrive.

.. note:: 
    When using gimbal motors, :code:`current_lim` `and` :code:`calibration_current` actually mean `voltage limit` and `calibration voltage` respectively, since we don't use current feedback. 
    This means that if you set it to 10, it means 10V, despite the name of the parameter.

Motor Thermistor
*********************************************************************************

If using motor thermistor please see the :ref:`thermistors <thermistor-doc>` page for setup.

Encoder Configuration
--------------------------------------------------------------------------------

With Encoder
~~~~~~~~~~~~~~~~~~~~~~~~~~~~~~~~~~~~~~~~~~~~~~~~~~~~~~~~~~~~~~~~~~~~~~~~~~~~~~~~

Set the encoder count per revolution [CPR] value

.. code:: iPython
    
    odrv0.axis0.encoder.config.cpr

This is 4x the Pulse Per Revolution (PPR) value. Usually this is indicated in the datasheet of your encoder.
If you purchased an encoder from our shop, you can find the parameters `here <https://docs.google.com/spreadsheets/d/1OBDwYrBb5zUPZLrhL98ezZbg94tUsZcdTuwiVNgVqpU/edit#gid=0>`__.

Without Encoder
~~~~~~~~~~~~~~~~~~~~~~~~~~~~~~~~~~~~~~~~~~~~~~~~~~~~~~~~~~~~~~~~~~~~~~~~~~~~~~~~

* If you wish to run in sensorless mode, please see :ref:`Setting up sensorless. <sensorless-setup>`
* If you are using hall sensor feedback, please see the :ref:`hoverboard motor example <hoverboard-doc>`.

.. _save-config:

Save Configuration
--------------------------------------------------------------------------------

You can save all :code:`.config` parameters to persistent memory so the ODrive remembers them between power cycles. This will reboot the board.

.. code:: iPython
    
    odrv0.save_configuration() 

Position control of M0
--------------------------------------------------------------------------------
Let's get motor 0 up and running. The procedure for motor 1 is exactly the same, so feel free to substitute :code:`axis1` wherever it says :code:`axis0`.

    #. Start the calibratrion sequence by entering

    .. code:: iPython
        
        odrv0.axis0.requested_state = AXIS_STATE_FULL_CALIBRATION_SEQUENCE
        
    and press :kbd:`Enter`. 

    After about 2 seconds you should hear a beep. Then the motor will turn slowly in one direction for a few seconds, then back in the other direction.

    .. dropdown:: What's the point of this?

        This procedure first measures your motor's electrical properties (namely phase resistance and phase inductance) and then the offset between the motor's electrical phase and the encoder position.

    The startup procedure is demonstrated `here <https://www.youtube.com/watch?v=VCX1bA2xnuY>`__.

    .. note::
        The rotor must be allowed to rotate without any biased load during startup. 
        That means mass and weak friction loads are fine, but gravity or spring loads are not okay. 
        Also note that in the video, the motors spin after initialization, but in the current software the default behaviour is not like that.

    .. dropdown:: Help, something isn't working!
    
        Check the encoder wiring and that the encoder is firmly connected to the motor. Check the value of :code:`dump_errors(odrv0)` and then refer to the :ref:`error code documentation <error-codes>` for details.
        Once you understand the error and have fixed its cause, you may clear the error state with (:code:`odrv0.clear_errors()` :kbd:`Enter`) and retry.

    #. Start closed loop control by typing

        .. code:: iPython
            
            odrv0.axis0.requested_state = AXIS_STATE_CLOSED_LOOP_CONTROL
            
        and press :kbd:`Enter`. From now on the ODrive will try to hold the motor's position. If you try to turn it by hand, it will fight you gently. That is unless you bump up :code:`odrv0.axis0.motor.config.current_lim`, in which case it will fight you more fiercely. 
        If the motor begins to vibrate either immediately or after being disturbed you will need to :ref:`lower the controller gains <control-tuning>`.

    #. Send the motor a new position setpoint with 

        .. code:: iPython

            odrv0.axis0.controller.input_pos = 1
            
        The units are in turns.

    #. At this point you will probably want to :ref:`Properly tune <control-doc>` the motor controller in order to maximize system performance.

Other Control Modes
~~~~~~~~~~~~~~~~~~~~~~~~~~~~~~~~~~~~~~~~~~~~~~~~~~~~~~~~~~~~~~~~~~~~~~~~~~~~~~~~

The default control mode is unfiltered position control in the absolute encoder reference frame. 
The ODrive can be used with a variety of control modes, to learn more, check out the :ref:`control modes <control-modes-doc>` documentation page.

Watchdog Timer
--------------------------------------------------------------------------------

Each axis has a configurable watchdog timer that can stop the motors if the
control connection to the ODrive is interrupted.

Each axis has a configurable watchdog timeout: :code:`axis.config.watchdog_timeout`,
measured in seconds. Set 

.. code:: iPython
    
    axis.config.enable_watchdog = True
    
to turn on this feature.

The watchdog is fed using the :code:`axis.watchdog_feed()` method of each axis. 
Some :ref:`ascii commands <acsii-cmd-ref>` and most CANSimple commands feed the watchdog automatically.

What's next?
--------------------------------------------------------------------------------

You can now:
* :ref:`Properly tune <control-doc>` the motor controller to unlock the full potential of the ODrive.
* See what other :ref:`commands and parameters <commands-doc>` are available, in order to better control the ODrive.
* Control the ODrive from your own program or hook it up to an existing system through one of it's :ref:`interfaces <pinout-chart>`.
* See how you can improve the behavior during the startup procedure, like :ref:`bypassing encoder calibration <encoder-with-index-signal>`.
* The CAN communication is the most reliable way of talking to ODrive in a real application.  Check out the :ref:`CAN Guide <can-guide>` and :ref:`CAN Protocol <can-protocol>`

If you have any issues or any questions please get in touch. The `ODrive Community <https://discourse.odriverobotics.com/>`__ warmly welcomes you.

Upgrading from 0.4.12
--------------------------------------------------------------------------------

A new version (0.5.4) of ODrive firmware has released, complete with a new odrivetool. 
Follow the installation instructions, making sure to add the :code:`--upgrade` flag to pip commands, and check out the `Changelog <https://github.com/odriverobotics/ODrive/blob/master/CHANGELOG.md>`_ for changes!

The odrivetool will stage and restore your configuration.  
This probably isn't wise for the 0.4.12 -> 0.5.1 upgrade, so we suggest using :code:`odrv0.erase_configuration()` immediately after connecting the first time.

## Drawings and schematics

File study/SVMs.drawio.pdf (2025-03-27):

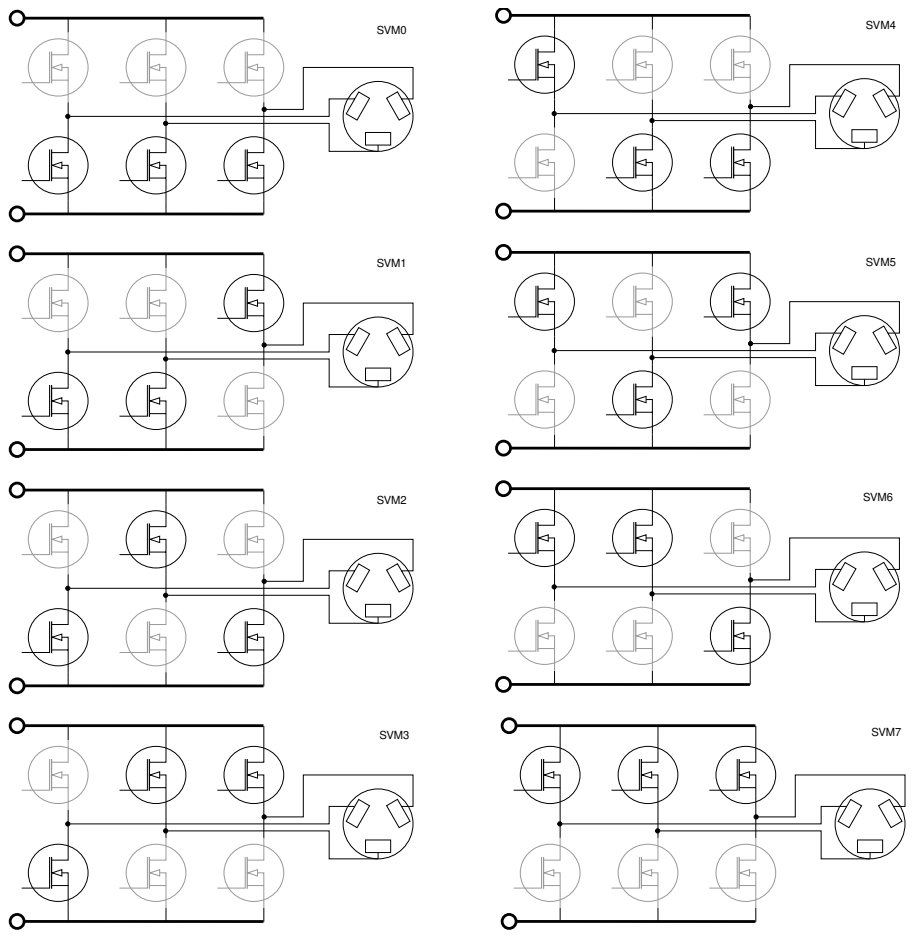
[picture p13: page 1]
SVM1; SVM4 SVM0; SVM5; SVM2; SVM6; SVM3; SVM7

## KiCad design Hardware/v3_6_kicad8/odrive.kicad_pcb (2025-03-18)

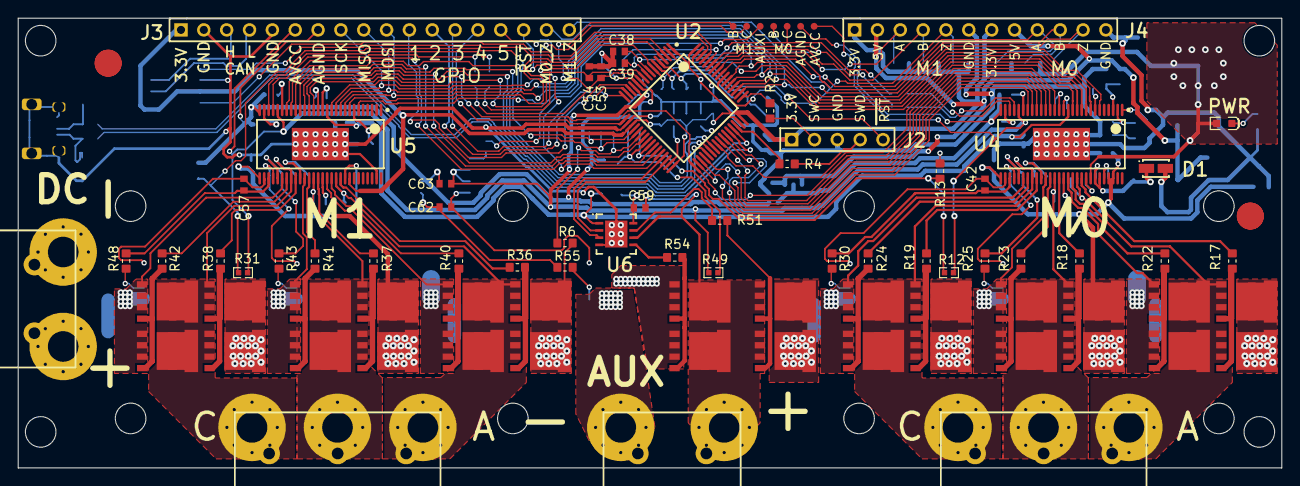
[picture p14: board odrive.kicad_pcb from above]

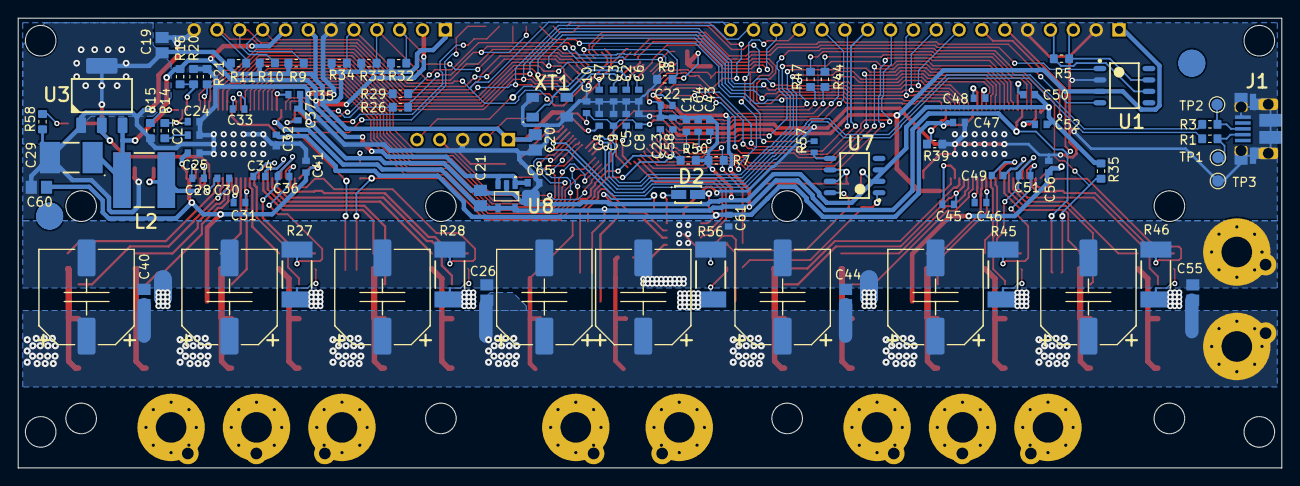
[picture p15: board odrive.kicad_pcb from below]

Board: 2 copper layers, 140.5 x 50.0 mm, 217 parts (109 on the bottom side), 152 nets.

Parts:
C1, C4, C5, C23, C32, C35, C37, C43, C47, C50, C52, C58, C61, C65: 2.2µF; CAPC1608X09L
C2, C3: 10pF; CAPC1608X09L
C6, C7, C8, C9, C10, C22, C25, C28, C30, C31, C34, C41, C45, C46, C49, C56, C59, C63: 0.1uF; CAPC1608X09L
C11, C12, C13, C14, C15, C16, C17, C18: 470uF; CAP_ELEC_SIZE_G
C19, C20, C21, C26, C40, C44, C55, C60: 4.7uF; CAPC2012X09N
C24: 82pF; CAPC1608X09L
C27: 270pF; CAPC1608X09L
C29: 68uF; CAPCP6032X28N
C33, C48: 0.022µF; CAPC1608X09L
C36, C38, C39, C42, C51, C53, C54, C57, C62, C64: 2200pF; CAPC1608X09L
D1, D2: DIOM2717X10N
FID1, FID2, FID3, FID4: FIDUCIAL
H1, H2, H3, H4, H5, H6, H7, H8, H9, H10, H11, H12: M3 Hole
J1: USB_0103594-0001LF
J2: HDR1X5
J3: Leftheader; HDR1X18
J4: Rightheader; HDR1X12
J7, J8, J11, J12, J13, J16, J17, J18, J21, J22: M3 Spade Hole
J9, J23: 1868076
J14, J19: 1704936
L2: 22uH; INDC6060X28N
LED1: Green; LED-0603-GREEN
NT1: NetTie_2mm
NT2, NT3, NT4, NT5, NT6, NT7, NT8, NT9, NT10, NT11: 0.25mm; NetTie_0.25mm
Q1, Q3, Q5, Q7, Q8, Q9, Q10, Q11, Q12, Q13, Q15, Q17, Q19, Q20, Q21, Q22, Q23, Q24, Q26, Q27, Q28: SO8FL
Q2, Q4, Q6, Q14, Q16, Q18, Q25: FILL_FOOTPRINT; SO8FL_FILL
R1, R2, R3, R4, R26, R29, R44, R47: 22R; RESC1608X55N
R5, R25, R30, R43, R48, R55: 120R; RESC1608X55N
R6: 10K; RESC1608X55N
R7, R58: 1k; RESC1608X55N
R8, R14: 47K; RESC1608X55N
R9, R10, R11, R13, R20, R32, R33, R34, R35, R50: 3.3k; RESC1608X55N
R12, R31, R49: 10k; RESC1005X40N
R15: 220k; RESC1608X55N
R16, R21, R39: 18k; RESC1608X55N
R17, R18, R19, R22, R23, R24, R36, R37, R38, R40, R41, R42, R51, R54: 2.2R; RESC1608X55N
R27, R28, R45, R46, R56: 500uOhm; RESC6432X09N
R57: 120R; RESC1608X06L
TP1, TP2, TP3: TESTPOINT; TP-R60
TP4, TP5, TP6, TP7, TP8, TP9, TP10: TESTPOINT; TP-R30
U1: SN65HVD232D; SOIC127P600X175-8N
U2: STM-LQFP64_N
U3: 3.3V; SOT223
U4, U5: TSSOP50P810X120_HS-57N
U6: SON80P400X80_HS-9N
U7: SOIC127P600X175-8N
U8: 3.3V; SOT23-5
XT1: 8 MHz; DFN220P320X110-4N

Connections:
5V: C29.1, C65.2, J4.2, J4.8, L2.2, R16.1, U3.3, U8.1, U8.3
AGND: C1.1, C21.1, C22.2, C23.1, C35.1, C37.1, C38.2, C39.2, C43.1, C50.1, C52.1, C53.2, C54.2, C58.1, C63.2, C64.2, J3.7, NT1.2, R7.1, R13.2, R35.2, R50.2, TP5.1, U2.12, U4.28, U5.28, U7.2, U7.3, U8.2
AUX_H_1: U2.30, U6.2
AUX_I_1: C64.1, R57.2, TP10.1, U2.21
AUX_L_1: U2.29, U6.3
AUX_TEMP_1: C58.2, R49.1, R50.1, U2.24
AVCC: C21.2, C22.1, C63.1, J3.6, R12.2, R31.2, R49.2, TP4.1, U2.13, U4.24, U5.24, U7.6, U7.7, U8.4, U8.5
BOOT0_1: R8.2, U2.60
CAN_D_1: U1.1, U2.62
CAN_H_1: J3.3, R5.2, U1.7
CAN_L_1: J3.4, R5.1, U1.6
CAN_R_1: U1.4, U2.61
DCBUS: C11.1, C12.1, C13.1, C14.1, C15.1, C16.1, C17.1, C18.1, C25.1, C26.2, C40.2, C41.1, C44.2, C55.2, C56.1, C60.2, J7.1, J9.2, Q1.D, Q2.D, Q3.D, Q4.D, Q5.D, Q6.D, Q13.D, Q14.D, Q15.D, Q16.D, Q17.D, Q18.D, Q25.D, Q26.D, R6.2, U4.29, U4.53, U4.54, U5.29
EN_GATE_1: U2.33, U4.16, U5.16
GH_A_2: R17.2, U4.47
GH_A_3: R36.1, U5.47
GH_B_2: R18.2, U4.42
GH_B_3: R37.1, U5.42
GH_C_2: R19.2, U4.37
GH_C_3: R38.1, U5.37
GL_A_2: R22.2, U4.45
GL_A_3: R40.1, U5.45
GL_B_2: R23.2, U4.40
GL_B_3: R41.1, U5.40
GL_C_2: R24.2, U4.35
GL_C_3: R42.1, U5.35
GND: C2.2, C3.2, C4.1, C5.1, C6.1, C7.2, C8.2, C9.2, C10.2, C19.1, C20.1, C24.2, C25.2, C27.2, C29.2, C32.1, C41.2, C47.1, C56.2, C60.1, C65.1, D1.A, J1.5, J1.SH, J2.3, J3.2, J3.5, J4.6, J4.12, NT1.1, NT7.1, R8.1, R15.2, R20.2, R21.2, R39.2, R58.2, TP3.1, U1.2, U2.18, U2.63, U3.1, U4.57, U5.55, U5.57, XT1.G
GPIO_1_1: J3.11, U2.14
GPIO_2_1: J3.12, U2.15
GPIO_3_1: J3.13, U2.16
GPIO_4_1: J3.14, U2.17
GPIO_5_1: J3.15, U2.28
GVDD: C32.2, C47.2, C61.2, D2.A, U4.13, U5.13, U6.1
M0_AH_1: U2.41, U4.17
M0_AL_1: U2.34, U4.18
M0_BH_1: U2.42, U4.19
M0_BL_1: U2.35, U4.20
M0_CH_1: U2.43, U4.21
M0_CL_1: U2.36, U4.22
M0_DC_CAL_1: U2.40, U4.12
M0_ENC_A_1: J4.9, R9.1, U2.56
M0_ENC_B_1: J4.10, R10.1, U2.57
M0_ENC_Z_1: J3.17, J4.11, R11.1, U2.50
M0_NCS_1: U2.2, U4.8
M0_SO1_1: C38.1, R26.2, TP6.1, U2.8
M0_SO2_1: C39.1, R29.2, TP7.1, U2.9
M0_TEMP_1: C23.2, R12.1, R13.1, U2.25
M1_AH_1: U2.37, U5.17
M1_AL_1: U2.23, U5.18
M1_BH_1: U2.38, U5.19
M1_BL_1: U2.26, U5.20
M1_CH_1: U2.39, U5.21
M1_CL_1: U2.27, U5.22
M1_DC_CAL_1: U2.4, U5.12
M1_ENC_A_1: J4.3, R32.2, U2.58
M1_ENC_B_1: J4.4, R33.2, U2.59
M1_ENC_Z_1: J3.18, J4.5, R34.2, U2.55
M1_NCS_1: U2.3, U5.8
M1_SO1_1: C53.1, R44.2, TP8.1, U2.11
M1_SO2_1: C54.1, R47.2, TP9.1, U2.10
M1_TEMP_1: C43.2, R31.1, R35.1, U2.20
NFAULT_1: U2.54, U4.6, U5.6
NRST_1: C6.2, J2.5, J3.16, U2.7
NetC2_1: C2.1, U2.6, XT1.1
NetC3_1: C3.1, U2.5, XT1.3
NetC4_2: C4.2, U2.47
NetC5_2: C5.2, U2.31
NetC24_1: C24.1, R14.1, U4.2
NetC27_1: C27.1, R14.2
NetC28_1: C28.1, D1.K, L2.1, U4.50, U4.51
NetC28_2: C28.2, U4.52
NetC30_2: C30.2, U4.48
NetC31_2: C31.2, U4.43
NetC33_1: C33.1, U4.14
NetC33_2: C33.2, U4.15
NetC34_2: C34.2, U4.38
NetC35_2: C35.2, U4.23
NetC36_1: C36.1, R25.2, U4.33
NetC37_2: C37.2, U4.27
NetC42_1: C42.1, R30.2, U4.31
NetC45_2: C45.2, U5.48
NetC46_2: C46.2, U5.43
NetC48_1: C48.1, U5.14
NetC48_2: C48.2, U5.15
NetC49_2: C49.2, U5.38
NetC50_2: C50.2, U5.23
NetC51_1: C51.1, R43.2, U5.33
NetC52_2: C52.2, U5.27
NetC57_1: C57.1, R48.2, U5.31
NetC59_1: C59.1, D2.K, U6.8
NetC59_2: C59.2, J21.1, J23.2, Q25.S, Q26.S, Q27.D, Q28.D, U6.6
NetC62_1: C62.1, R55.1, U7.1
NetC62_2: C62.2, NT6.1, U7.8
NetJ1_2: J1.2, R1.2, TP1.1
NetJ1_3: J1.3, R3.2, TP2.1
NetJ2_2: J2.2, R2.1
NetJ2_4: J2.4, R4.1
NetJ22_1: J22.1, J23.1, R55.2, R56.1
NetLED1_K: LED1.K, R58.1
NetQ1_G: Q1.G, Q2.G, R17.1
NetQ3_G: Q3.G, Q4.G, R18.1
NetQ5_G: Q5.G, Q6.G, R19.1
NetQ7_G: Q7.G, Q8.G, R22.1
NetQ9_G: Q9.G, Q10.G, R23.1
NetQ11_G: Q11.G, Q12.G, R24.1
NetQ13_G: Q13.G, Q14.G, R36.2
NetQ15_G: Q15.G, Q16.G, R37.2
NetQ17_G: Q17.G, Q18.G, R38.2
NetQ19_G: Q19.G, Q20.G, R40.2
NetQ21_G: Q21.G, Q22.G, R41.2
NetQ23_G: Q23.G, Q24.G, R42.2
NetQ25_G: Q25.G, Q26.G, R51.2
NetQ27_G: Q27.G, Q28.G, R54.2
NetR15_1: R15.1, U4.1
NetR16_2: R16.2, R20.1, U4.3
NetR21_1: R21.1, U4.7
NetR26_1: R26.1, U4.25
NetR29_1: R29.1, U4.26
NetR39_1: R39.1, U5.7
NetR44_1: R44.1, U5.25
NetR47_1: R47.1, U5.26
NetR51_1: R51.1, U6.7
NetR54_1: R54.1, U6.5
NetR57_1: R57.1, U7.5
PGND: C11.2, C12.2, C13.2, C14.2, C15.2, C16.2, C17.2, C18.2, C26.1, C40.1, C44.1, C55.1, C61.1, J8.1, J9.1, NT2.2, NT3.2, NT4.2, NT5.2, NT6.2, NT7.2, Q7.S, Q8.S, Q19.S, Q20.S, Q27.S, Q28.S, R27.1, R28.1, R45.1, R46.1, R56.2, U4.44, U5.44, U6.4, U6.9
SH_A_2: C30.1, J11.1, J14.3, Q1.S, Q2.S, Q7.D, Q8.D, U4.46
SH_A_3: C45.1, J16.1, J19.3, Q13.S, Q14.S, Q19.D, Q20.D, U5.46
SH_B_2: C31.1, J12.1, J14.2, Q3.S, Q4.S, Q9.D, Q10.D, U4.41
SH_B_3: C46.1, J17.1, J19.2, Q15.S, Q16.S, Q21.D, Q22.D, U5.41
SH_C_2: C34.1, J13.1, J14.1, Q5.S, Q6.S, Q11.D, Q12.D, U4.36
SH_C_3: C49.1, J18.1, J19.1, Q17.S, Q18.S, Q23.D, Q24.D, U5.36
SL_B_2: NT8.2, Q9.S, Q10.S, R27.2, U4.39
SL_B_3: NT10.2, Q21.S, Q22.S, R45.2, U5.39
SL_C_2: NT9.2, Q11.S, Q12.S, R28.2, U4.34
SL_C_3: NT11.2, Q23.S, Q24.S, R46.2, U5.34
SN1_2: NT8.1, R25.1
SN1_3: NT10.1, R43.1
SN2_2: NT9.1, R30.1
SN2_3: NT11.1, R48.1
SP1_2: C36.2, NT2.1, U4.32
SP1_3: C51.2, NT4.1, U5.32
SP2_2: C42.2, NT3.1, U4.30
SP2_3: C57.2, NT5.1, U5.30
SPI_MISO_1: J3.9, U2.52, U4.10, U5.10
SPI_MOSI_1: J3.10, U2.53, U4.9, U5.9
SPI_SCK_1: J3.8, U2.51, U4.11, U5.11
SWCLK_1: R2.2, U2.49
SWDIO_1: R4.2, U2.46
USB_DM_1: R1.1, U2.44
USB_DP_1: R3.1, U2.45
VBUS_S_1: C1.2, R6.1, R7.2, U2.22
VCC: C7.1, C8.1, C9.1, C10.1, C19.2, C20.2, J2.1, J3.1, J4.1, J4.7, LED1.A, R9.2, R10.2, R11.2, R32.1, R33.1, R34.1, U1.3, U2.1, U2.19, U2.32, U2.48, U2.64, U3.2, U3.4, U4.49, U5.49

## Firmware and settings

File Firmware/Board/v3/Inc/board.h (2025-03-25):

/*
* @brief Contains board specific configuration for ODrive v3.x
*/

#ifndef __BOARD_CONFIG_H
#define __BOARD_CONFIG_H

#include <stdbool.h>

// STM specific includes
#include <stm32f4xx_hal.h>
#include <gpio.h>
#include <spi.h>
#include <tim.h>
#include <can.h>
#include <i2c.h>
#include <usb_device.h>
#include <main.h>
#include "cmsis_os.h"

#include <arm_math.h>

#include <Drivers/STM32/stm32_system.h>

#if HW_VERSION_MINOR <= 3
#define SHUNT_RESISTANCE (675e-6f)
#else
#define SHUNT_RESISTANCE (500e-6f)
#endif

#define AXIS_COUNT (2)

// Total count of GPIOs, including encoder pins, CAN pins and a dummy GPIO0.
// ODrive v3.4 and earlier don't have GPIOs 6, 7 and 8 but to keep the numbering
// consistent we just leave a gap in the counting scheme.
#define GPIO_COUNT  (17)

#define CAN_FREQ (2000000UL)

#if HW_VERSION_MINOR >= 5 && HW_VERSION_VOLTAGE >= 48
#define DEFAULT_BRAKE_RESISTANCE (2.0f) // [ohm]
#else
#define DEFAULT_BRAKE_RESISTANCE (0.47f) // [ohm]
#endif

#define DEFAULT_ERROR_PIN 0
#define DEFAULT_MIN_DC_VOLTAGE 8.0f

#define DEFAULT_GPIO_MODES \
    ODriveIntf::GPIO_MODE_DIGITAL, \
    ODriveIntf::GPIO_MODE_UART_A, \
    ODriveIntf::GPIO_MODE_UART_A, \
    ODriveIntf::GPIO_MODE_ANALOG_IN, \
    ODriveIntf::GPIO_MODE_ANALOG_IN, \
    ODriveIntf::GPIO_MODE_ANALOG_IN, \
    ODriveIntf::GPIO_MODE_DIGITAL, \
    ODriveIntf::GPIO_MODE_DIGITAL, \
    ODriveIntf::GPIO_MODE_DIGITAL, \
    ODriveIntf::GPIO_MODE_ENC0, \
    ODriveIntf::GPIO_MODE_ENC0, \
    ODriveIntf::GPIO_MODE_DIGITAL_PULL_DOWN, \
    ODriveIntf::GPIO_MODE_ENC1, \
    ODriveIntf::GPIO_MODE_ENC1, \
    ODriveIntf::GPIO_MODE_DIGITAL_PULL_DOWN, \
    ODriveIntf::GPIO_MODE_CAN_A, \
    ODriveIntf::GPIO_MODE_CAN_A,

#define TIM_TIME_BASE TIM14

// Run control loop at the same frequency as the current measurements.
#define CONTROL_TIMER_PERIOD_TICKS  (2 * TIM_1_8_PERIOD_CLOCKS * (TIM_1_8_RCR + 1))

#define TIM1_INIT_COUNT (TIM_1_8_PERIOD_CLOCKS / 2 - 1 * 128) // TODO: explain why this offset

// The delta from the control loop timestamp to the current sense timestamp is
// exactly 0 for M0 and TIM1_INIT_COUNT for M1.
#define MAX_CONTROL_LOOP_UPDATE_TO_CURRENT_UPDATE_DELTA (TIM_1_8_PERIOD_CLOCKS / 2 + 1 * 128)

#ifdef __cplusplus
#include <Drivers/DRV8301/drv8301.hpp>
#include <Drivers/STM32/stm32_gpio.hpp>
#include <Drivers/STM32/stm32_spi_arbiter.hpp>
#include <MotorControl/pwm_input.hpp>
#include <MotorControl/thermistor.hpp>

using TGateDriver = Drv8301;
using TOpAmp = Drv8301;

#include <MotorControl/motor.hpp>
#include <MotorControl/encoder.hpp>

extern std::array<Axis, AXIS_COUNT> axes;
extern Motor motors[AXIS_COUNT];
extern OnboardThermistorCurrentLimiter fet_thermistors[AXIS_COUNT];
extern Encoder encoders[AXIS_COUNT];
extern Stm32Gpio gpios[GPIO_COUNT];

struct GpioFunction { int mode = 0; uint8_t alternate_function = 0xff; };
extern std::array<GpioFunction, 3> alternate_functions[GPIO_COUNT];

extern USBD_HandleTypeDef& usb_dev_handle;

extern Stm32SpiArbiter& ext_spi_arbiter;

extern UART_HandleTypeDef* uart_a;
extern UART_HandleTypeDef* uart_b;
extern UART_HandleTypeDef* uart_c;

extern PwmInput pwm0_input;
#endif

// Period in [s]
#define CURRENT_MEAS_PERIOD ( (float)2*TIM_1_8_PERIOD_CLOCKS*(TIM_1_8_RCR+1) / (float)TIM_1_8_CLOCK_HZ )
static const float current_meas_period = CURRENT_MEAS_PERIOD;

// Frequency in [Hz]
#define CURRENT_MEAS_HZ ( (float)(TIM_1_8_CLOCK_HZ) / (float)(2*TIM_1_8_PERIOD_CLOCKS*(TIM_1_8_RCR+1)) )
static const int current_meas_hz = CURRENT_MEAS_HZ;

#if HW_VERSION_VOLTAGE >= 48
// Voltage Divider, 18KOhm(R6)/1KOhm(R7)
#define VBUS_S_DIVIDER_RATIO 19.0f
#elif HW_VERSION_VOLTAGE == 24
// Voltage Divider, 10KOhm(R6)/1KOhm(R7)
#define VBUS_S_DIVIDER_RATIO 11.0f
#else
#error "unknown board voltage"
#endif

// Linear range of the DRV8301 opamp output: 0.3V...5.7V. We set the upper limit
// to 3.0V so that it's symmetric around the center point of 1.65V.
#define CURRENT_SENSE_MIN_VOLT  0.3f
#define CURRENT_SENSE_MAX_VOLT  3.0f

// This board has no board-specific user configurations
static inline bool board_read_config() { return true; }
static inline bool board_write_config() { return true; }
static inline void board_clear_config() { }
static inline bool board_apply_config() { return true; }

void system_init();
bool board_init();
void start_timers();

#endif // __BOARD_CONFIG_H

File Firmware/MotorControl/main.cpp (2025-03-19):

#define __MAIN_CPP__
#include "odrive_main.h"
#include "nvm_config.hpp"

#include "usart.h"
#include "freertos_vars.h"
#include "usb_device.h"
#include <communication/interface_usb.h>
#include <communication/interface_uart.h>
#include <communication/interface_i2c.h>
#include <communication/interface_can.hpp>

osSemaphoreId sem_usb_irq;
osMessageQId uart_event_queue;
osMessageQId usb_event_queue;
osSemaphoreId sem_can;

#if defined(STM32F405xx)
// Place FreeRTOS heap in core coupled memory for better performance
__attribute__((section(".ccmram")))
#endif
uint8_t ucHeap[configTOTAL_HEAP_SIZE];

uint32_t _reboot_cookie __attribute__ ((section (".noinit")));
extern char _estack; // provided by the linker script


ODrive odrv{};


ConfigManager config_manager;

class StatusLedController {
public:
    void update();
};

StatusLedController status_led_controller;

void StatusLedController::update() {
#if HW_VERSION_MAJOR == 4
    uint32_t t = HAL_GetTick();

    bool is_booting = std::any_of(axes.begin(), axes.end(), [](Axis& axis){
        return axis.current_state_ == Axis::AXIS_STATE_UNDEFINED;
    });

    if (is_booting) {
        return;
    }

    bool is_armed = std::any_of(axes.begin(), axes.end(), [](Axis& axis){
        return axis.motor_.is_armed_;
    });
    bool any_error = odrv.any_error();

    if (is_armed) {
        // Fast green pulsating
        const uint32_t period_ms = 256;
        const uint8_t min_brightness = 0;
        const uint8_t max_brightness = 255;
        uint32_t brightness = std::abs((int32_t)(t % period_ms) - (int32_t)(period_ms / 2)) * (max_brightness - min_brightness) / (period_ms / 2) + min_brightness;
        brightness = (brightness * brightness) >> 8; // eye response very roughly sqrt
        status_led.set_color(rgb_t{(uint8_t)(any_error ? brightness / 2 : 0), (uint8_t)brightness, 0});
    } else if (any_error) {
        // Red pulsating
        const uint32_t period_ms = 1024;
        const uint8_t min_brightness = 0;
        const uint8_t max_brightness = 255;
        uint32_t brightness = std::abs((int32_t)(t % period_ms) - (int32_t)(period_ms / 2)) * (max_brightness - min_brightness) / (period_ms / 2) + min_brightness;
        brightness = (brightness * brightness) >> 8; // eye response very roughly sqrt
        status_led.set_color(rgb_t{(uint8_t)brightness, 0, 0});
    } else {
        // Slow blue pulsating
        const uint32_t period_ms = 4096;
        const uint8_t min_brightness = 50;
        const uint8_t max_brightness = 160;
        uint32_t brightness = std::abs((int32_t)(t % period_ms) - (int32_t)(period_ms / 2)) * (max_brightness - min_brightness) / (period_ms / 2) + min_brightness;
        brightness = (brightness * brightness) >> 8; // eye response very roughly sqrt
        status_led.set_color(rgb_t{0, 0, (uint8_t)brightness});
    }
#endif
}

static bool config_read_all() {
    bool success = board_read_config() &&
           config_manager.read(&odrv.config_) &&
           config_manager.read(&odrv.can_.config_);
    for (size_t i = 0; (i < AXIS_COUNT) && success; ++i) {
        success = config_manager.read(&encoders[i].config_) &&
                  config_manager.read(&axes[i].sensorless_estimator_.config_) &&
                  config_manager.read(&axes[i].controller_.config_) &&
                  config_manager.read(&axes[i].trap_traj_.config_) &&
                  config_manager.read(&axes[i].min_endstop_.config_) &&
                  config_manager.read(&axes[i].max_endstop_.config_) &&
                  config_manager.read(&axes[i].mechanical_brake_.config_) &&
                  config_manager.read(&motors[i].config_) &&
                  config_manager.read(&motors[i].fet_thermistor_.config_) &&
                  config_manager.read(&motors[i].motor_thermistor_.config_) &&
                  config_manager.read(&axes[i].config_);
    }
    return success;
}

static bool config_write_all() {
    bool success = board_write_config() &&
           config_manager.write(&odrv.config_) &&
           config_manager.write(&odrv.can_.config_);
    for (size_t i = 0; (i < AXIS_COUNT) && success; ++i) {
        success = config_manager.write(&encoders[i].config_) &&
                  config_manager.write(&axes[i].sensorless_estimator_.config_) &&
                  config_manager.write(&axes[i].controller_.config_) &&
                  config_manager.write(&axes[i].trap_traj_.config_) &&
                  config_manager.write(&axes[i].min_endstop_.config_) &&
                  config_manager.write(&axes[i].max_endstop_.config_) &&
                  config_manager.write(&axes[i].mechanical_brake_.config_) &&
                  config_manager.write(&motors[i].config_) &&
                  config_manager.write(&motors[i].fet_thermistor_.config_) &&
                  config_manager.write(&motors[i].motor_thermistor_.config_) &&
                  config_manager.write(&axes[i].config_);
    }
    return success;
}

static void config_clear_all() {
    odrv.config_ = {};
    odrv.can_.config_ = {};
    for (size_t i = 0; i < AXIS_COUNT; ++i) {
        encoders[i].config_ = {};
        axes[i].sensorless_estimator_.config_ = {};
        axes[i].controller_.config_ = {};
        axes[i].controller_.config_.load_encoder_axis = i;
        axes[i].trap_traj_.config_ = {};
        axes[i].min_endstop_.config_ = {};
        axes[i].max_endstop_.config_ = {};
        axes[i].mechanical_brake_.config_ = {};
        motors[i].config_ = {};
        motors[i].fet_thermistor_.config_ = {};
        motors[i].motor_thermistor_.config_ = {};
        axes[i].clear_config();
    }
}

static bool config_apply_all() {
    bool success = odrv.can_.apply_config();
    for (size_t i = 0; (i < AXIS_COUNT) && success; ++i) {
        success = encoders[i].apply_config(motors[i].config_.motor_type)
               && axes[i].controller_.apply_config()
               && axes[i].min_endstop_.apply_config()
               && axes[i].max_endstop_.apply_config()
               && motors[i].apply_config()
               && motors[i].motor_thermistor_.apply_config()
               && axes[i].apply_config();
    }
    return success;
}

bool ODrive::save_configuration(void) {
    bool success;

    CRITICAL_SECTION() {
        bool any_armed = std::any_of(axes.begin(), axes.end(),
            [](auto& axis){ return axis.motor_.is_armed_; });
        if (any_armed) {
            return false;
        }

        size_t config_size = 0;
        success = config_manager.prepare_store()
               && config_write_all()
               && config_manager.start_store(&config_size)
               && config_write_all()
               && config_manager.finish_store();

        // FIXME: during save_configuration we might miss some interrupts
        // because the CPU gets halted during a flash erase. Missing events
        // (encoder updates, step/dir steps) is not good so to be sure we just
        // reboot.
        NVIC_SystemReset();
    }

    return success;
}

void ODrive::erase_configuration(void) {
    NVM_erase();

    // FIXME: this reboot is a workaround because we don't want the next save_configuration
    // to write back the old configuration from RAM to NVM. The proper action would
    // be to reset the values in RAM to default. However right now that's not
    // practical because several startup actions depend on the config. The
    // other problem is that the stack overflows if we reset to default here.
    NVIC_SystemReset();
}

void ODrive::enter_dfu_mode() {
    if ((hw_version_major_ == 3) && (hw_version_minor_ >= 5)) {
        __asm volatile ("CPSID I\n\t":::"memory"); // disable interrupts
        _reboot_cookie = 0xDEADBEEF;
        NVIC_SystemReset();
    } else {
        /*
        * DFU mode is only allowed on board version >= 3.5 because it can burn
        * the brake resistor FETs on older boards.
        * If you really want to use it on an older board, add 3.3k pull-down resistors
        * to the AUX_L and AUX_H signals and _only then_ uncomment these lines.
        */
        //__asm volatile ("CPSID I\n\t":::"memory"); // disable interrupts
        //_reboot_cookie = 0xDEADFE75;
        //NVIC_SystemReset();
    }
}

bool ODrive::any_error() {
    return error_ != ODrive::ERROR_NONE
        || std::any_of(axes.begin(), axes.end(), [](Axis& axis){
            return axis.error_ != Axis::ERROR_NONE
                || axis.motor_.error_ != Motor::ERROR_NONE
                || axis.sensorless_estimator_.error_ != SensorlessEstimator::ERROR_NONE
                || axis.encoder_.error_ != Encoder::ERROR_NONE
                || axis.controller_.error_ != Controller::ERROR_NONE;
        });
}

uint64_t ODrive::get_drv_fault() {
#if AXIS_COUNT == 1
    return motors[0].gate_driver_.get_error();
#elif AXIS_COUNT == 2
    return (uint64_t)motors[0].gate_driver_.get_error() | ((uint64_t)motors[1].gate_driver_.get_error() << 32ULL);
#else
    #error "not supported"
#endif
}

void ODrive::clear_errors() {
    for (auto& axis: axes) {
        axis.motor_.error_ = Motor::ERROR_NONE;
        axis.controller_.error_ = Controller::ERROR_NONE;
        axis.sensorless_estimator_.error_ = SensorlessEstimator::ERROR_NONE;
        axis.encoder_.error_ = Encoder::ERROR_NONE;
        axis.encoder_.spi_error_rate_ = 0.0f;
        axis.error_ = Axis::ERROR_NONE;
    }
    error_ = ERROR_NONE;
    if (odrv.config_.enable_brake_resistor) {
        safety_critical_arm_brake_resistor();
    }
}

extern "C" {

void vApplicationStackOverflowHook(xTaskHandle *pxTask, signed portCHAR *pcTaskName) {
    for(auto& axis: axes){
        axis.motor_.disarm();
    }
    safety_critical_disarm_brake_resistor();
    for (;;); // TODO: safe action
}

void vApplicationIdleHook(void) {
    if (odrv.system_stats_.fully_booted) {
        odrv.system_stats_.uptime = xTaskGetTickCount();
        odrv.system_stats_.min_heap_space = xPortGetMinimumEverFreeHeapSize();

        uint32_t min_stack_space[AXIS_COUNT];
        std::transform(axes.begin(), axes.end(), std::begin(min_stack_space), [](auto& axis) { return uxTaskGetStackHighWaterMark(axis.thread_id_) * sizeof(StackType_t); });
        odrv.system_stats_.max_stack_usage_axis = axes[0].stack_size_ - *std::min_element(std::begin(min_stack_space), std::end(min_stack_space));
        odrv.system_stats_.max_stack_usage_usb = stack_size_usb_thread - uxTaskGetStackHighWaterMark(usb_thread) * sizeof(StackType_t);
        odrv.system_stats_.max_stack_usage_uart = stack_size_uart_thread - uxTaskGetStackHighWaterMark(uart_thread) * sizeof(StackType_t);
        odrv.system_stats_.max_stack_usage_startup = stack_size_default_task - uxTaskGetStackHighWaterMark(defaultTaskHandle) * sizeof(StackType_t);
        odrv.system_stats_.max_stack_usage_can = odrv.can_.stack_size_ - uxTaskGetStackHighWaterMark(odrv.can_.thread_id_) * sizeof(StackType_t);
        odrv.system_stats_.max_stack_usage_analog =  stack_size_analog_thread - uxTaskGetStackHighWaterMark(analog_thread) * sizeof(StackType_t);

        odrv.system_stats_.stack_size_axis = axes[0].stack_size_;
        odrv.system_stats_.stack_size_usb = stack_size_usb_thread;
        odrv.system_stats_.stack_size_uart = stack_size_uart_thread;
        odrv.system_stats_.stack_size_startup = stack_size_default_task;
        odrv.system_stats_.stack_size_can = odrv.can_.stack_size_;
        odrv.system_stats_.stack_size_analog = stack_size_analog_thread;

        odrv.system_stats_.prio_axis = osThreadGetPriority(axes[0].thread_id_);
        odrv.system_stats_.prio_usb = osThreadGetPriority(usb_thread);
        odrv.system_stats_.prio_uart = osThreadGetPriority(uart_thread);
        odrv.system_stats_.prio_startup = osThreadGetPriority(defaultTaskHandle);
        odrv.system_stats_.prio_can = osThreadGetPriority(odrv.can_.thread_id_);
        odrv.system_stats_.prio_analog = osThreadGetPriority(analog_thread);

        status_led_controller.update();
    }
}
}

/**
 * @brief Runs system-level checks that need to be as real-time as possible.
 *
 * This function is called after every current measurement of every motor.
 * It should finish as quickly as possible.
 */
void ODrive::do_fast_checks() {
    if (!(vbus_voltage >= config_.dc_bus_undervoltage_trip_level))
        disarm_with_error(ERROR_DC_BUS_UNDER_VOLTAGE);
    if (!(vbus_voltage <= config_.dc_bus_overvoltage_trip_level))
        disarm_with_error(ERROR_DC_BUS_OVER_VOLTAGE);
}

/**
 * @brief Floats all power phases on the system (all motors and brake resistors).
 *
 * This should be called if a system level exception ocurred that makes it
 * unsafe to run power through the system in general.
 */
void ODrive::disarm_with_error(Error error) {
    CRITICAL_SECTION() {
        for (auto& axis: axes) {
            axis.motor_.disarm_with_error(Motor::ERROR_SYSTEM_LEVEL);
        }
        safety_critical_disarm_brake_resistor();
        error_ |= error;
    }
}
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
extern "C" int main(void) {
    // This procedure of building a USB serial number should be identical
    // to the way the STM's built-in USB bootloader does it. This means
    // that the device will have the same serial number in normal and DFU mode.
    uint32_t uuid0 = *(uint32_t *)(UID_BASE + 0);
    uint32_t uuid1 = *(uint32_t *)(UID_BASE + 4);
    uint32_t uuid2 = *(uint32_t *)(UID_BASE + 8);
    uint32_t uuid_mixed_part = uuid0 + uuid2;
    serial_number = ((uint64_t)uuid_mixed_part << 16) | (uint64_t)(uuid1 >> 16);

    uint64_t val = serial_number;
    for (size_t i = 0; i < 12; ++i) {
        serial_number_str[i] = "0123456789ABCDEF"[(val >> (48-4)) & 0xf];
        val <<= 4;
    }
    serial_number_str[12] = 0;

    // Init low level system functions (clocks, flash interface)
    system_init();

    // Load configuration from NVM. This needs to happen after system_init()
    // since the flash interface must be initialized and before board_init()
    // since board initialization can depend on the config.
    size_t config_size = 0;
    bool success = config_manager.start_load()
            && config_read_all()
            && config_manager.finish_load(&config_size)
            && config_apply_all();
    if (success) {
        odrv.user_config_loaded_ = config_size;
    } else {
        config_clear_all();
        config_apply_all();
    }

    odrv.misconfigured_ = odrv.misconfigured_
            || (odrv.config_.enable_uart_a && !uart_a)
            || (odrv.config_.enable_uart_b && !uart_b)
            || (odrv.config_.enable_uart_c && !uart_c);

    // Init board-specific peripherals
    if (!board_init()) {
        for (;;); // TODO: handle properly
    }

    // Init GPIOs according to their configured mode
    for (size_t i = 0; i < GPIO_COUNT; ++i) {
        // Skip unavailable GPIOs
        if (!get_gpio(i)) {
            continue;
        }

        ODriveIntf::GpioMode mode = odrv.config_.gpio_modes[i];

        GPIO_InitTypeDef GPIO_InitStruct;
        GPIO_InitStruct.Pin = get_gpio(i).pin_mask_;

        // Set Alternate Function setting for this GPIO mode
        if (mode == ODriveIntf::GPIO_MODE_DIGITAL ||
            mode == ODriveIntf::GPIO_MODE_DIGITAL_PULL_UP ||
            mode == ODriveIntf::GPIO_MODE_DIGITAL_PULL_DOWN ||
            mode == ODriveIntf::GPIO_MODE_MECH_BRAKE ||
            mode == ODriveIntf::GPIO_MODE_STATUS ||
            mode == ODriveIntf::GPIO_MODE_ANALOG_IN) {
            GPIO_InitStruct.Alternate = 0;
        } else {
            auto it = std::find_if(
                    alternate_functions[i].begin(), alternate_functions[i].end(),
                    [mode](auto a) { return a.mode == mode; });

            if (it == alternate_functions[i].end()) {
                odrv.misconfigured_ = true; // this GPIO doesn't support the selected mode
                continue;
            }
            GPIO_InitStruct.Alternate = it->alternate_function;
        }

        switch (mode) {
            case ODriveIntf::GPIO_MODE_DIGITAL: {
                GPIO_InitStruct.Mode = GPIO_MODE_INPUT;
                GPIO_InitStruct.Pull = GPIO_NOPULL;
                GPIO_InitStruct.Speed = GPIO_SPEED_FREQ_LOW;
            } break;
            case ODriveIntf::GPIO_MODE_DIGITAL_PULL_UP: {
                GPIO_InitStruct.Mode = GPIO_MODE_INPUT;
                GPIO_InitStruct.Pull = GPIO_PULLUP;
                GPIO_InitStruct.Speed = GPIO_SPEED_FREQ_LOW;
            } break;
            case ODriveIntf::GPIO_MODE_DIGITAL_PULL_DOWN: {
                GPIO_InitStruct.Mode = GPIO_MODE_INPUT;
                GPIO_InitStruct.Pull = GPIO_PULLDOWN;
                GPIO_InitStruct.Speed = GPIO_SPEED_FREQ_LOW;
            } break;
            case ODriveIntf::GPIO_MODE_ANALOG_IN: {
                GPIO_InitStruct.Mode = GPIO_MODE_ANALOG;
                GPIO_InitStruct.Pull = GPIO_NOPULL;
            } break;
            case ODriveIntf::GPIO_MODE_UART_A: {
                GPIO_InitStruct.Mode = GPIO_MODE_AF_PP;
                GPIO_InitStruct.Pull = (i == 0) ? GPIO_PULLDOWN : GPIO_PULLUP; // this is probably swapped but imitates old behavior
                GPIO_InitStruct.Speed = GPIO_SPEED_FREQ_VERY_HIGH;
                if (!odrv.config_.enable_uart_a) {
                    odrv.misconfigured_ = true;
                }
            } break;
            case ODriveIntf::GPIO_MODE_UART_B: {
                GPIO_InitStruct.Mode = GPIO_MODE_AF_PP;
                GPIO_InitStruct.Pull = (i == 0) ? GPIO_PULLDOWN : GPIO_PULLUP; // this is probably swapped but imitates old behavior
                GPIO_InitStruct.Speed = GPIO_SPEED_FREQ_VERY_HIGH;
                if (!odrv.config_.enable_uart_b) {
                    odrv.misconfigured_ = true;
                }
            } break;
            case ODriveIntf::GPIO_MODE_UART_C: {
                GPIO_InitStruct.Mode = GPIO_MODE_AF_PP;
                GPIO_InitStruct.Pull = (i == 0) ? GPIO_PULLDOWN : GPIO_PULLUP; // this is probably swapped but imitates old behavior
                GPIO_InitStruct.Speed = GPIO_SPEED_FREQ_VERY_HIGH;
                if (!odrv.config_.enable_uart_c) {
                    odrv.misconfigured_ = true;
                }
            } break;
            case ODriveIntf::GPIO_MODE_CAN_A: {
                GPIO_InitStruct.Mode = GPIO_MODE_AF_PP;
                GPIO_InitStruct.Pull = GPIO_NOPULL;
                GPIO_InitStruct.Speed = GPIO_SPEED_FREQ_VERY_HIGH;
                if (!odrv.config_.enable_can_a) {
                    odrv.misconfigured_ = true;
                }
            } break;
            case ODriveIntf::GPIO_MODE_I2C_A: {
                GPIO_InitStruct.Mode = GPIO_MODE_AF_OD;
                GPIO_InitStruct.Pull = GPIO_PULLUP;
                GPIO_InitStruct.Speed = GPIO_SPEED_FREQ_VERY_HIGH;
                if (!odrv.config_.enable_i2c_a) {
                    odrv.misconfigured_ = true;
                }
            } break;
            //case ODriveIntf::GPIO_MODE_SPI_A: { // TODO
            //} break;
            case ODriveIntf::GPIO_MODE_PWM: {
                GPIO_InitStruct.Mode = GPIO_MODE_AF_PP;
                GPIO_InitStruct.Pull = GPIO_PULLDOWN;
                GPIO_InitStruct.Speed = GPIO_SPEED_FREQ_LOW;
            } break;
            case ODriveIntf::GPIO_MODE_ENC0: {
                GPIO_InitStruct.Mode = GPIO_MODE_AF_PP;
                GPIO_InitStruct.Pull = GPIO_NOPULL;
                GPIO_InitStruct.Speed = GPIO_SPEED_FREQ_LOW;
            } break;
            case ODriveIntf::GPIO_MODE_ENC1: {
                GPIO_InitStruct.Mode = GPIO_MODE_AF_PP;
                GPIO_InitStruct.Pull = GPIO_NOPULL;
                GPIO_InitStruct.Speed = GPIO_SPEED_FREQ_LOW;
            } break;
            case ODriveIntf::GPIO_MODE_ENC2: {
                GPIO_InitStruct.Mode = GPIO_MODE_AF_PP;
                GPIO_InitStruct.Pull = GPIO_NOPULL;
                GPIO_InitStruct.Speed = GPIO_SPEED_FREQ_LOW;
            } break;
            case ODriveIntf::GPIO_MODE_MECH_BRAKE: {
                GPIO_InitStruct.Mode = GPIO_MODE_OUTPUT_PP;
                GPIO_InitStruct.Pull = GPIO_NOPULL;
                GPIO_InitStruct.Speed = GPIO_SPEED_FREQ_LOW;
            } break;
            case ODriveIntf::GPIO_MODE_STATUS: {
                GPIO_InitStruct.Mode = GPIO_MODE_OUTPUT_PP;
                GPIO_InitStruct.Pull = GPIO_NOPULL;
                GPIO_InitStruct.Speed = GPIO_SPEED_FREQ_LOW;
            } break;
            default: {
                odrv.misconfigured_ = true;
                continue;
            }
        }

        HAL_GPIO_Init(get_gpio(i).port_, &GPIO_InitStruct);
    }

    // Init usb irq binary semaphore, and start with no tokens by removing the starting one.
    osSemaphoreDef(sem_usb_irq);
    sem_usb_irq = osSemaphoreCreate(osSemaphore(sem_usb_irq), 1);
    osSemaphoreWait(sem_usb_irq, 0);

    // Create an event queue for UART
    osMessageQDef(uart_event_queue, 4, uint32_t);
    uart_event_queue = osMessageCreate(osMessageQ(uart_event_queue), NULL);

    // Create an event queue for USB
    osMessageQDef(usb_event_queue, 7, uint32_t);
    usb_event_queue = osMessageCreate(osMessageQ(usb_event_queue), NULL);

    osSemaphoreDef(sem_can);
    sem_can = osSemaphoreCreate(osSemaphore(sem_can), 1);
    osSemaphoreWait(sem_can, 0);

    // Create main thread
    osThreadDef(defaultTask, rtos_main, osPriorityNormal, 0, stack_size_default_task / sizeof(StackType_t));
    defaultTaskHandle = osThreadCreate(osThread(defaultTask), NULL);

    // Start scheduler
    osKernelStart();

    for (;;);
}

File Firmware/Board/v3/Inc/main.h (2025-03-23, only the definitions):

#define TIM_1_8_CLOCK_HZ 168000000
#define TIM_1_8_PERIOD_CLOCKS 3500
#define TIM_1_8_DEADTIME_CLOCKS 20
#define TIM_APB1_CLOCK_HZ 84000000
#define TIM_APB1_PERIOD_CLOCKS 4096
#define TIM_APB1_DEADTIME_CLOCKS 40
#define TIM_1_8_RCR 2
#define M0_nCS_Pin GPIO_PIN_13
#define M0_nCS_GPIO_Port GPIOC
#define M1_nCS_Pin GPIO_PIN_14
#define M1_nCS_GPIO_Port GPIOC
#define M1_ENC_Z_Pin GPIO_PIN_15
#define M1_ENC_Z_GPIO_Port GPIOC
#define M0_IB_Pin GPIO_PIN_0
#define M0_IB_GPIO_Port GPIOC
#define M0_IC_Pin GPIO_PIN_1
#define M0_IC_GPIO_Port GPIOC
#define M1_IC_Pin GPIO_PIN_2
#define M1_IC_GPIO_Port GPIOC
#define M1_IB_Pin GPIO_PIN_3
#define M1_IB_GPIO_Port GPIOC
#define GPIO_1_Pin GPIO_PIN_0
#define GPIO_1_GPIO_Port GPIOA
#define GPIO_2_Pin GPIO_PIN_1
#define GPIO_2_GPIO_Port GPIOA
#define GPIO_3_Pin GPIO_PIN_2
#define GPIO_3_GPIO_Port GPIOA
#define GPIO_4_Pin GPIO_PIN_3
#define GPIO_4_GPIO_Port GPIOA
#define M1_TEMP_Pin GPIO_PIN_4
#define M1_TEMP_GPIO_Port GPIOA
#define AUX_TEMP_Pin GPIO_PIN_5
#define AUX_TEMP_GPIO_Port GPIOA
#define VBUS_S_Pin GPIO_PIN_6
#define VBUS_S_GPIO_Port GPIOA
#define M1_AL_Pin GPIO_PIN_7
#define M1_AL_GPIO_Port GPIOA
#define GPIO_5_Pin GPIO_PIN_4
#define GPIO_5_GPIO_Port GPIOC
#define M0_TEMP_Pin GPIO_PIN_5
#define M0_TEMP_GPIO_Port GPIOC
#define M1_BL_Pin GPIO_PIN_0
#define M1_BL_GPIO_Port GPIOB
#define M1_CL_Pin GPIO_PIN_1
#define M1_CL_GPIO_Port GPIOB
#define GPIO_6_Pin GPIO_PIN_2
#define GPIO_6_GPIO_Port GPIOB
#define AUX_L_Pin GPIO_PIN_10
#define AUX_L_GPIO_Port GPIOB
#define AUX_H_Pin GPIO_PIN_11
#define AUX_H_GPIO_Port GPIOB
#define EN_GATE_Pin GPIO_PIN_12
#define EN_GATE_GPIO_Port GPIOB
#define M0_AL_Pin GPIO_PIN_13
#define M0_AL_GPIO_Port GPIOB
#define M0_BL_Pin GPIO_PIN_14
#define M0_BL_GPIO_Port GPIOB
#define M0_CL_Pin GPIO_PIN_15
#define M0_CL_GPIO_Port GPIOB
#define M1_AH_Pin GPIO_PIN_6
#define M1_AH_GPIO_Port GPIOC
#define M1_BH_Pin GPIO_PIN_7
#define M1_BH_GPIO_Port GPIOC
#define M1_CH_Pin GPIO_PIN_8
#define M1_CH_GPIO_Port GPIOC
#define M0_ENC_Z_Pin GPIO_PIN_9
#define M0_ENC_Z_GPIO_Port GPIOC
#define M0_AH_Pin GPIO_PIN_8
#define M0_AH_GPIO_Port GPIOA
#define M0_BH_Pin GPIO_PIN_9
#define M0_BH_GPIO_Port GPIOA
#define M0_CH_Pin GPIO_PIN_10
#define M0_CH_GPIO_Port GPIOA
#define GPIO_7_Pin GPIO_PIN_15
#define GPIO_7_GPIO_Port GPIOA
#define nFAULT_Pin GPIO_PIN_2
#define nFAULT_GPIO_Port GPIOD
#define GPIO_8_Pin GPIO_PIN_3
#define GPIO_8_GPIO_Port GPIOB
#define M0_ENC_A_Pin GPIO_PIN_4
#define M0_ENC_A_GPIO_Port GPIOB
#define M0_ENC_B_Pin GPIO_PIN_5
#define M0_ENC_B_GPIO_Port GPIOB
#define M1_ENC_A_Pin GPIO_PIN_6
#define M1_ENC_A_GPIO_Port GPIOB
#define M1_ENC_B_Pin GPIO_PIN_7
#define M1_ENC_B_GPIO_Port GPIOB

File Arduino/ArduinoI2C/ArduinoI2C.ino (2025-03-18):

#include <Wire.h>
#include "odrive.h"


// See odrive.h for a description
bool I2C_transaction(uint8_t slave_addr, const uint8_t * tx_buffer, size_t tx_length, uint8_t * rx_buffer, size_t rx_length) {
  // transmit
  if (tx_buffer) {
    Wire.beginTransmission(slave_addr);
    if (Wire.write(tx_buffer, tx_length) != tx_length)
      return false;
    bool should_stop = !rx_buffer;
    if (Wire.endTransmission(should_stop) != 0)
      return false;
  }

  // receive
  if (rx_buffer) {
    while(Wire.available()) Wire.read(); // flush input buffer
    if (Wire.requestFrom(slave_addr, (uint8_t)rx_length, (uint8_t)true /* stop after receiving */) != rx_length)
      return false;
    for (size_t i = 0; i < rx_length; ++i)
      rx_buffer[i] = Wire.read();
  }

  return true;
}


int set_and_save_configuration(uint8_t odrive_num, uint8_t axis_num) {
  bool success;
  success = odrive::clear_errors(odrive_num, axis_num);
  if (!success)
    return __LINE__;

  // select hall effect mode
  bool user_config_loaded = false;
  success = odrive::read_property<odrive::USER_CONFIG_LOADED>(odrive_num, &user_config_loaded);
  if (!success)
    return __LINE__;
  if (user_config_loaded) {
    Serial.println("ODrive already configured");
    return 0;
  }

  // select hall effect mode
  success = odrive::write_axis_property<odrive::AXIS__ENCODER__CONFIG__MODE>(odrive_num, axis_num, 1);
  if (!success)
    return __LINE__;

  // configure encoder counts per revolution (6 hall effect states * 12 pole pairs)
  success = odrive::write_axis_property<odrive::AXIS__ENCODER__CONFIG__CPR>(odrive_num, axis_num, 72);
  if (!success)
    return __LINE__;

  // disable velocity integrator
  success = odrive::write_axis_property<odrive::AXIS__CONTROLLER__CONFIG__VEL_INTEGRATOR_GAIN>(odrive_num, axis_num, 0);
  if (!success)
    return __LINE__;

  // select velocity control
  success = odrive::write_axis_property<odrive::AXIS__CONTROLLER__CONFIG__CONTROL_MODE>(odrive_num, axis_num, 2);
  if (!success)
    return __LINE__;

  // set velocity controller P-gain
  success = odrive::write_axis_property<odrive::AXIS__CONTROLLER__CONFIG__VEL_GAIN>(odrive_num, axis_num, 0.005f);
  if (!success)
    return __LINE__;

  // request state: motor calibration
  success = odrive::write_axis_property<odrive::AXIS__REQUESTED_STATE>(odrive_num, axis_num, 4);
  if (!success)
    return __LINE__;

  delay(6000);

  // check if the axis is in idle and no errors occurred
  if (!odrive::check_axis_state(odrive_num, axis_num, 1))
    return __LINE__;

  // ensure that the motor calibration is considered valid after power cycle
  success = odrive::write_axis_property<odrive::AXIS__MOTOR__CONFIG__PRE_CALIBRATED>(odrive_num, axis_num, true);
  if (!success)
    return __LINE__;

  // request state: encoder calibration
  success = odrive::write_axis_property<odrive::AXIS__REQUESTED_STATE>(odrive_num, axis_num, 7);
  if (!success)
    return __LINE__;

  delay(12000);

  // check if the axis is in idle and no errors occurred
  if (!odrive::check_axis_state(odrive_num, axis_num, 1))
    return __LINE__;

  // ensure that the encoder calibration is considered valid after power cycle
  success = odrive::write_axis_property<odrive::AXIS__ENCODER__CONFIG__PRE_CALIBRATED>(odrive_num, axis_num, true);
  if (!success)
    return __LINE__;
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

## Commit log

2025-03-18 import latest open source and hardware of Odrive
    for my study
    Hardware
    - branch:master
    - commit id:079f30ac58f193226fcc552e4d6ba24553027ee1
    - only latest v3.6
    - convert Altium design to KICAD v8 format
    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
    [AuxHalfH.kicad_sch, MotorCell.kicad_sch, MotorCell_noPow.kicad_sch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]
2025-03-18 add comment for TIM1/TIM8 and TIM2 for motors
    TIM1/TIM8 for Motors PWM Generator
    - TIM1 for M0
    - TIM8 for M1
    TIM2 for AUX (Break resistor) PWM Generator
2025-03-18 modify aux schematic for gate driver value
    [AuxHalfH.kicad_sch]
2025-03-19 assign AD8418 to current amplifier of AUX
    [AuxHalfH.kicad_sch]
2025-03-21 update somethings for odrive architecture
2025-03-23 correct PWM timing
2025-03-25 update DCBUS voltage divider for 48/56V
    [odrive.kicad_sch]
2025-03-26 add interrupt table
2025-03-26 add PWM timing update describle
2025-04-01 add clarke transform pdf by browser printing
2025-07-09 add my board config

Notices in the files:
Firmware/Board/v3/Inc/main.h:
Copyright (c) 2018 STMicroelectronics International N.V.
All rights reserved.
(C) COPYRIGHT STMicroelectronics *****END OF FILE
